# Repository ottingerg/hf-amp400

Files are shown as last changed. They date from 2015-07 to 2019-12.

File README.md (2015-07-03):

# hf-amp400

HF-Amp400 is controllerboard designed to controll the gate biasing and output power of 2 double HF-AMP FETs. 

It therefore provides 4 channels of gate biasing

4 channels of HF-Power mesaurement 

2 resetable fuses up to 10A and one auxilary resetable fuse controll for even higher currents.

This project was done as collaberation between

EMV-Consulting (http://www.emvconsulting.at)

Otelo eGen (http://www.oteloegen.at)

and

Karl Zeilhofer (http://www.zeilhofer.co.at)

it is Open Source Hardware licensed under CC-BY-SA 3.0 and is based on EtherDue which itself is based on Arduino Due

# EtherDue

The EtherDue is an 100% Arduino Due compatible board with onboard Ethernet.

For full details about the EtherDue, including a getting started guide, please visit the [Freetronics EtherDue product page](http://www.freetronics.com/products/etherdue-arduino-due-compatible-with-onboard-ethernet).

Design files were produced with [Kicad](http://kicad-pcb.org). A [PDF of the schematic is available](https://github.com/freetronics/EtherDue/raw/master/EtherDue.pdf).

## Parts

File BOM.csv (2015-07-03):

Count | Reference | Value | Footprint | Library | Part
2 | Q101 Q102 | IPB020NE7N3G | w_smd_trans:d2-pak | EtherDue-cache | NMOSFET2
2 | P102 P103 | MSTBV3 | eagle-con-phoenix-508:MSTBV3 | EtherDue-cache | CONN_01X03
10 | JP101 JP102 JP801 JP1001 JP1002 JP1003 JP1004 JP1701 JP1801 JP1901 | JUMPER3 | Pin_Headers:Pin_Header_Straight_1x03 | freetronics_kicad_sch_lib | JUMPER3
1 | P104 | MSTBV6 | eagle-con-phoenix-508:MSTBV6 | EtherDue-cache | CONN_01X06
4 | R103 R902 R1501 R1601 | 1k | Resistors_SMD:R_0603 | EtherDue-cache | R
7 | C101 C102 C103 C104 C105 C106 C107 | 1nF/X7R | Capacitors_SMD:C_0603 | EtherDue-cache | C
13 | D101 D102 D103 D1001 D1002 D1003 D1004 D1501 D1601 D2001 D2002 D2003 D2004 | BAT54S | w_smd_trans:sot23 | EtherDue-cache | DOUBLE_SCHOTTKY
1 | U101 | AD7415 | Housings_SOT-23_SOT-143_TSOT-6:SOT23-5 | EtherDue-cache | AD7415
2 | R101 R102 | Shunt | eagle-shunt:WSL4026 | EtherDue-cache | Shunt
1 | P101 | CONN_02X04 | w_conn_strip:vasch_strip_4x2 | EtherDue-cache | CONN_02X04
1 | U1701 | MCP6H04 | Housings_SOIC:SOIC-14_3.9x8.7mm_Pitch1.27mm | EtherDue-cache | LM324
11 | R104 R105 R1013 R1016 R1017 R1702 R1706 R1802 R1806 R1902 R1906 | 4k7 | Resistors_SMD:R_0603 | EtherDue-cache | R
57 | C803 C804 C901 C902 C1001 C1002 C1005 C1006 C1007 C1008 C1011 C1012 C1014 C1015 C1016 C1019 C1020 C1021 C1024 C1025 C1027 C1028 C1029 C1030 C1031 C1032 C1101 C1102 C1113 C1114 C1201 C1202 C1213 C1214 C1301 C1302 C1313 C1314 C1401 C1402 C1413 C1414 C1501 C1503 C1504 C1601 C1604 C1701 C1702 C1703 C1704 C1801 C1802 C1804 C1901 C1902 C1904 | 100n/X7R | Capacitors_SMD:C_0603 | EtherDue-cache | C
1 | IC201 | ATSAM3X8E | TQFP144 | freetronics_kicad_sch_lib | ATSAM3X8E
1 | SW202 | RESET | FT:TACTILE_SWITCH_SMD_2PIN_TINY | freetronics_kicad_sch_lib | SW_PUSHBUTTON
28 | C206 C207 C208 C301 C302 C503 C504 C509 C511 C512 C513 C514 C515 C516 C520 C521 C522 C523 C524 C526 C527 C603 C605 C607 C609 C610 C611 C701 | 100nF | SM0402 | EtherDue-cache | C
3 | U202 U503 U504 | FDN340P | FT:SOT23_MOSFET | EtherDue-cache | MOSFET-PCHANNEL
1 | SW201 | ERASE | FT:TACTILE_SWITCH_SMD_2PIN_TINY | freetronics_kicad_sch_lib | SW_PUSHBUTTON
3 | R206 R601 R604 | 1K | FT:RES_CAY16 | freetronics_kicad_sch_lib | RES_PACK4_IND
8 | D201 D202 D204 D302 D303 D601 D605 D606 | YELLOW | zeilhofer:LED-0603 | freetronics_kicad_sch_lib | LED
3 | D203 D602 D603 | GREEN | zeilhofer:LED-0603 | freetronics_kicad_sch_lib | LED
1 | U203 | LMV358IPWR | FT:TSSOP8 | EtherDue-cache | LM358
1 | R201 | 6k8 1% | SM0402_r | EtherDue-cache | R
7 | C201 C202 C205 C303 C304 C601 C602 | 22pF | SM0402 | EtherDue-cache | C
2 | R202 R203 | 39R 1% | SM0402_r | EtherDue-cache | R
2 | C203 C204 | 22pF_NM | SM0402 | EtherDue-cache | C
1 | X202 | ABS07L 32.768kHz | FT:ABS07L | freetronics_kicad_sch_lib | CRYSTAL
5 | L201 L501 L503 L504 L505 | MH2029-300Y | FT:MH2029 | EtherDue-cache | INDUCTOR_SMALL
1 | R204 | 100K | SM0402_r | EtherDue-cache | R
1 | X201 | TXC 7A 12MHz 18pF | FT:TXC_7A | freetronics_kicad_sch_lib | CRYSTAL
2 | SJ202 SJ401 | CLOSED | FT:SJ_SHORTED | freetronics_kicad_sch_lib | SJ
3 | SJ201 SJ203 SJ601 | OPEN | FT:SJ_OPEN | freetronics_kicad_sch_lib | SJ
3 | R205 R207 R304 | 1K5 | SM0402_r | EtherDue-cache | R
1 | R208 | 10K | SMD_Packages:SMD-0402_r | EtherDue-cache | R
1 | R305 | 2K7 | SM0402_r | EtherDue-cache | R
7 | R306 R307 R308 R309 R501 R606 R607 | 1K | SM0402_r | EtherDue-cache | R
5 | R303 R310 R403 R503 R505 | 10K | SM0402_r | EtherDue-cache | R
2 | R301 R302 | 22R | SM0402_r | EtherDue-cache | R
5 | VR401 VR402 VR403 Z301 Z302 | PGB1010603 | FT:0603 | EtherDue-cache | VR
2 | F301 F401 | 500mA PTC 1812 | SM1812 | freetronics_kicad_sch_lib | FUSE
2 | P301 P401 | USB_5PIN_SHELL | FT:USB-MICRO_TH_4PEGS | freetronics_kicad_sch_lib | USB_5PIN_SHELL
1 | C305 | 1uF | SM0402 | EtherDue-cache | C
1 | D301 | CD1206-S | FT:1206_DIODE | freetronics_kicad_sch_lib | DIODE
1 | ICSP301 | M02X03 | Pin_Headers:Pin_Header_Straight_2x03 | freetronics_kicad_sch_lib | M02X03
1 | IC301 | ATMEGA16U2 | FT:QFN32 | freetronics_kicad_sch_lib | ATMEGA16U2
1 | X301 | TXC 7A 16MHz 18pF | FT:TXC_7A | freetronics_kicad_sch_lib | CRYSTAL
1 | DEBUG401 | M04 | Pin_Headers:Pin_Header_Straight_1x04 | freetronics_kicad_sch_lib | M04
8 | C402 C403 C506 C507 C517 C518 C519 C528 | 10uF | FT:SM0603_Capa | EtherDue-cache | C
2 | C401 C505 | 10nF | SM0402 | EtherDue-cache | C
2 | R401 R502 | 100K | FT:RES_CAY16 | freetronics_kicad_sch_lib | RES_PACK4_IND
1 | JP401 | JTAG | FT:2X5_127MMPITCH | freetronics_kicad_sch_lib | M02X05
1 | SHIELD401 | ARDUINO_DUE_SHIELD | FT:ARDUINO_DUE_SHIELD | freetronics_kicad_sch_lib | ARDUINO_DUE_SHIELD
1 | U603 | APX811-31UG-7 | FT:SOT143-R | freetronics_kicad_sch_lib | APX811
3 | C604 C606 C608 | 10uF 6.3V A TANT | SMD_Packages:SMD-1206_Pol | EtherDue-cache | C
2 | L601 L602 | 1uH 250mA | FT:0805 | EtherDue-cache | INDUCTOR_SMALL
1 | R605 | 49R9 1% | FT:RES_CAY16 | freetronics_kicad_sch_lib | RES_PACK4
1 | JP601 | M04 | zeilhofer:FT-POE-MODULE-NOOUTLINE | freetronics_kicad_sch_lib | M04
1 | U602 | HY931147C | FT:HY931147C | freetronics_kicad_sch_lib | HY931147C
1 | D604 | RED | zeilhofer:LED-0603 | freetronics_kicad_sch_lib | LED
1 | R602 | 1M | SM0402_r | EtherDue-cache | R
1 | X601 | TXC 7A 25MHz 18pF | FT:TXC_7A | freetronics_kicad_sch_lib | CRYSTAL
1 | R603 | 12K3 1% | SM0402_r | EtherDue-cache | R
1 | Q601 | 2N7002 | FT:SOT23 | freetronics_kicad_sch_lib | 2N7002
1 | IC601 | W5100 | FT:SQFP80 | freetronics_kicad_sch_lib | W5100
1 | U701 | MICROSD | FT:MICRO-SD-SOCKET-PP | freetronics_kicad_sch_lib | MICROSD
2 | SJ701 SJ702 | SJ | FT:SJ_SHORTED | freetronics_kicad_sch_lib | SJ
1 | U702 | 24AA025E48 | FT:SOT23-6 | freetronics_kicad_sch_lib | 24AA025E48
1 | Q501 | BC847BSMD | FT:SOT23_TRANSISTOR | freetronics_kicad_sch_lib | NPN
1 | U505 | NCP1117ST33T3G | FT:SOT223 | EtherDue-cache | NCP1117ST33T3G
1 | R504 | 52K3 | SM0402_r | EtherDue-cache | R
1 | D503 | STPS2L60A | FT:SMA-DIODE | freetronics_kicad_sch_lib | DIODE
1 | C510 | 100uF 16V | Capacitors_SMD:c_elec_5x5.3 | EtherDue-cache | C
1 | L502 | 10uH SRR0604-100ML | FT:SRR0604 | EtherDue-cache | INDUCTOR_SMALL
1 | D502 | CD1206-S01575 | FT:1206_DIODE | freetronics_kicad_sch_lib | DIODE
1 | U502 | LM2734Y | FT:SOT23-6 | freetronics_kicad_sch_lib | LM2734Y
1 | C502 | 10uF 25V | SM1206 | EtherDue-cache | C
1 | C501 | 47uF 25V | Capacitors_SMD:c_elec_5x5.3 | EtherDue-cache | C
1 | D501 | 1N4004 | FT:SMB-DIODE | freetronics_kicad_sch_lib | DIODE
1 | U501 | POWERJACK | FT:POWER_JACK_PTH | freetronics_kicad_sch_lib | POWERJACK
2 | C702 C802 | 2n2/50V/COG | Capacitors_SMD:C_0603 | EtherDue-cache | C
1 | P801 | MSTBV2 | eagle-con-phoenix-508:MSTBV2 | EtherDue-cache | CONN_01X02
1 | F801 | SMD100F | eagle-switch-raychem:SMD050F | freetronics_kicad_sch_lib | FUSE
1 | D801 | ZENER2 | Diodes_SMD:Diode-SMB_Standard | EtherDue-cache | ZENER2
1 | L801 | WE-TI-744732331 | eagle-WE-TI:WE-TI_8075_SHRINKTUBE | EtherDue-cache | INDUCTOR_SMALL
19 | C801 C805 C806 C807 C813 C815 C816 C817 C1013 C1026 C1033 C1108 C1112 C1208 C1212 C1308 C1312 C1408 C1412 | 10u/25V/X7R | Capacitors_SMD:C_1206 | EtherDue-cache | C
3 | U801 U802 U803 | TPS7A4501DCQT | zeilhofer:DCQ(R-PDSO-G6) | EtherDue-cache | TPS7A4501DCQT
2 | R801 R802 | 18k | Resistors_SMD:R_0603 | EtherDue-cache | R
2 | R805 R807 | 2k2 | Resistors_SMD:R_0603 | EtherDue-cache | R
3 | R803 R804 R806 | 22k | Resistors_SMD:R_0603 | EtherDue-cache | R
1 | R808 | 3k9 | Resistors_SMD:R_0603 | EtherDue-cache | R
5 | U804 U1102 U1202 U1302 U1402 | REG101NA-5 | zeilhofer:DBV(R-PDSO-G5) | EtherDue-cache | REG101NA-5
1 | C808 | 1u/25V/X7R | Capacitors_SMD:C_0805 | EtherDue-cache | C
28 | C809 C810 C811 C812 C814 C818 C819 C820 C1106 C1109 C1206 C1209 C1306 C1309 C1406 C1409 C1705 C1706 C1805 C1806 C1905 C1906 C2001 C2002 C2003 C2010 C2011 C2012 | 10n/X7R | Capacitors_SMD:C_0603 | EtherDue-cache | C
17 | R809 R810 R811 R1103 R1106 R1203 R1206 R1303 R1306 R1403 R1406 R1708 R1709 R1808 R1809 R1908 R1909 | 0R | Resistors_SMD:R_0603 | EtherDue-cache | R
11 | L802 L803 L804 L805 L1101 L1201 L1301 L1401 L1701 L1801 L1901 | WE-CBF-742792093 | Resistors_SMD:R_0805 | EtherDue-cache | INDUCTOR_SMALL
1 | U901 | TJA1040T | Housings_SOIC:SOIC-8_3.9x4.9mm_Pitch1.27mm | EtherDue-cache | TJA1040T
1 | R903 | 47k | Resistors_SMD:R_0603 | EtherDue-cache | R
2 | SJ901 SJ902 | Solder-Jumper | FT:SJ_2W | freetronics_kicad_sch_lib | JUMPER_SJ3
2 | R904 R905 | 60R | Resistors_SMD:R_1206 | EtherDue-cache | R
2 | R906 R907 | 1k3 | Resistors_SMD:R_0603 | EtherDue-cache | R
2 | P901 P902 | 677006144621 | eagle-InputOutputIO:677006144621 | EtherDue-cache | CONN_01X06
1 | R901 | 1k8 | Resistors_SMD:R_0603 | EtherDue-cache | R
1 | L901 | WE-SL1-744212510 | eagle-WE-SL1:WE-SL1 | EtherDue-cache | WE-SL1
1 | U1001 | AD7294BSUZ | eagle-ADI-Phase-2:QFP40P900X900X120-64N | EtherDue-cache | AD7294BSUZ
20 | X1001 X1002 X1003 X1004 X1005 X1006 X1007 X1008 X1009 X1010 X1011 X1012 X1102 X1103 X1202 X1203 X1302 X1303 X1402 X1403 | SMB | zeilhofer:SMB-RS#420-5401_wirepad | EtherDue-cache | CONN_COAX
19 | R1001 R1002 R1003 R1004 R1005 R1006 R1007 R1008 R1014 R1015 R1703 R1705 R1707 R1803 R1805 R1807 R1903 R1905 R1907 | 100R | Resistors_SMD:R_0603 | EtherDue-cache | R
7 | Q1001 Q1703 Q1704 Q1803 Q1804 Q1903 Q1904 | BSS308 | zeilhofer:sot23-gsd | EtherDue-cache | PMOSFET2
4 | LED1001 LED1701 LED1801 LED1901 | RED | LEDs:LED-0805 | EtherDue-cache | LED2
4 | R1009 R1010 R1011 R1012 | 5k6 | Resistors_SMD:R_0603 | EtherDue-cache | R
23 | C1003 C1004 C1009 C1010 C1017 C1018 C1022 C1023 C1034 C1035 C1036 C1037 C1710 C1810 C1910 C2004 C2005 C2006 C2007 C2008 C2009 C2013 C2014 | 1n/X7R | Capacitors_SMD:C_0603 | EtherDue-cache | C
4 | VR1001 VR1002 VR1003 VR1004 | 10k | Potentiometers:Potentiometer_Bourns_3296W_3-8Zoll_Inline_ScrewUp | EtherDue-cache | POT123
4 | U1101 U1201 U1301 U1401 | ADL5513 | zeilhofer:LFCSP16 | EtherDue-cache | ADL5513
8 | P1101 P1102 P1201 P1202 P1301 P1302 P1401 P1402 | CONN_01X02 | Pin_Headers:Pin_Header_Straight_1x02 | EtherDue-cache | CONN_01X02
4 | R1104 R1204 R1304 R1404 | 12k | Resistors_SMD:R_0805 | EtherDue-cache | R
7 | R1105 R1205 R1305 R1405 R1710 R1810 R1910 | 2k2 | Resistors_SMD:R_0805 | EtherDue-cache | R
4 | C1110 C1210 C1310 C1410 | 47p/X7R | Capacitors_SMD:C_0603 | EtherDue-cache | C
8 | C1103 C1104 C1203 C1204 C1303 C1304 C1403 C1404 | 100p/X7R | Capacitors_SMD:C_0603 | EtherDue-cache | C
4 | X1101 X1201 X1301 X1401 | SMA | zeilhofer:SMA-RS#616-3422 | EtherDue-cache | CONN_COAX
8 | C1105 C1107 C1205 C1207 C1305 C1307 C1405 C1407 | 47n/C0G | Capacitors_SMD:C_0402 | EtherDue-cache | C
4 | R1102 R1202 R1302 R1402 | 820R/1% | Resistors_SMD:R_0603 | EtherDue-cache | R
4 | C1111 C1211 C1311 C1411 | 100n/X7R | Capacitors_SMD:C_0805 | EtherDue-cache | C
4 | R1101 R1201 R1301 R1401 | 56R/1% | Resistors_SMD:R_0603 | EtherDue-cache | R
2 | R1502 R1602 | 100k | Resistors_SMD:R_0603 | EtherDue-cache | R
2 | C1502 C1602 | 1u/X7R | Capacitors_SMD:C_0805 | EtherDue-cache | C
10 | Q1501 Q1502 Q1601 Q1602 Q1701 Q1702 Q1801 Q1802 Q1901 Q1902 | BSS123 | zeilhofer:sot23-gsd | EtherDue-cache | NMOSFET2
12 | R1503 R1504 R1505 R1603 R1604 R1605 R1701 R1801 R1901 R2007 R2008 R2009 | 10k | Resistors_SMD:R_0603 | EtherDue-cache | R
1 | U1501 | 4013_with_supply | Housings_SOIC:SOIC-14_3.9x8.7mm_Pitch1.27mm | EtherDue-cache | 4013_with_supply
3 | SW1701 SW1801 SW1901 | SW_PUSH | FT:SW_TACTILE_SMD | EtherDue-cache | SW_PUSH
3 | U1702 U1801 U1901 | INA207 | Housings_SOIC:SOIC-14_3.9x8.7mm_Pitch1.27mm | EtherDue-cache | INA207
3 | C1709 C1809 C1909 | DNP | Capacitors_SMD:C_0603 | EtherDue-cache | C
3 | U1703 U1802 U1902 | MEU1S1212ZC | zeilhofer:MEU1-Murata-DCDC | EtherDue-cache | MEU1
3 | R1704 R1804 R1904 | 1k | Resistors_SMD:R_1206 | EtherDue-cache | R
6 | C1707 C1708 C1807 C1808 C1907 C1908 | 1n/X7R | Capacitors_SMD:C_0805 | EtherDue-cache | C
3 | VR1701 VR1801 VR1901 | 100k | Potentiometers:Potentiometer_Bourns_3296W_3-8Zoll_Inline_ScrewUp | EtherDue-cache | POT123
2 | R2010 R2011 | 6k8 | Resistors_SMD:R_0603 | EtherDue-cache | R
1 | R2012 | TBD | Resistors_SMD:R_0603 | EtherDue-cache | R
3 | R2001 R2002 R2003 | 47k | Resistors_SMD:R_0805 | EtherDue-cache | R
3 | R2004 R2005 R2006 | 2k7 | Resistors_SMD:R_0603 | EtherDue-cache | R
576

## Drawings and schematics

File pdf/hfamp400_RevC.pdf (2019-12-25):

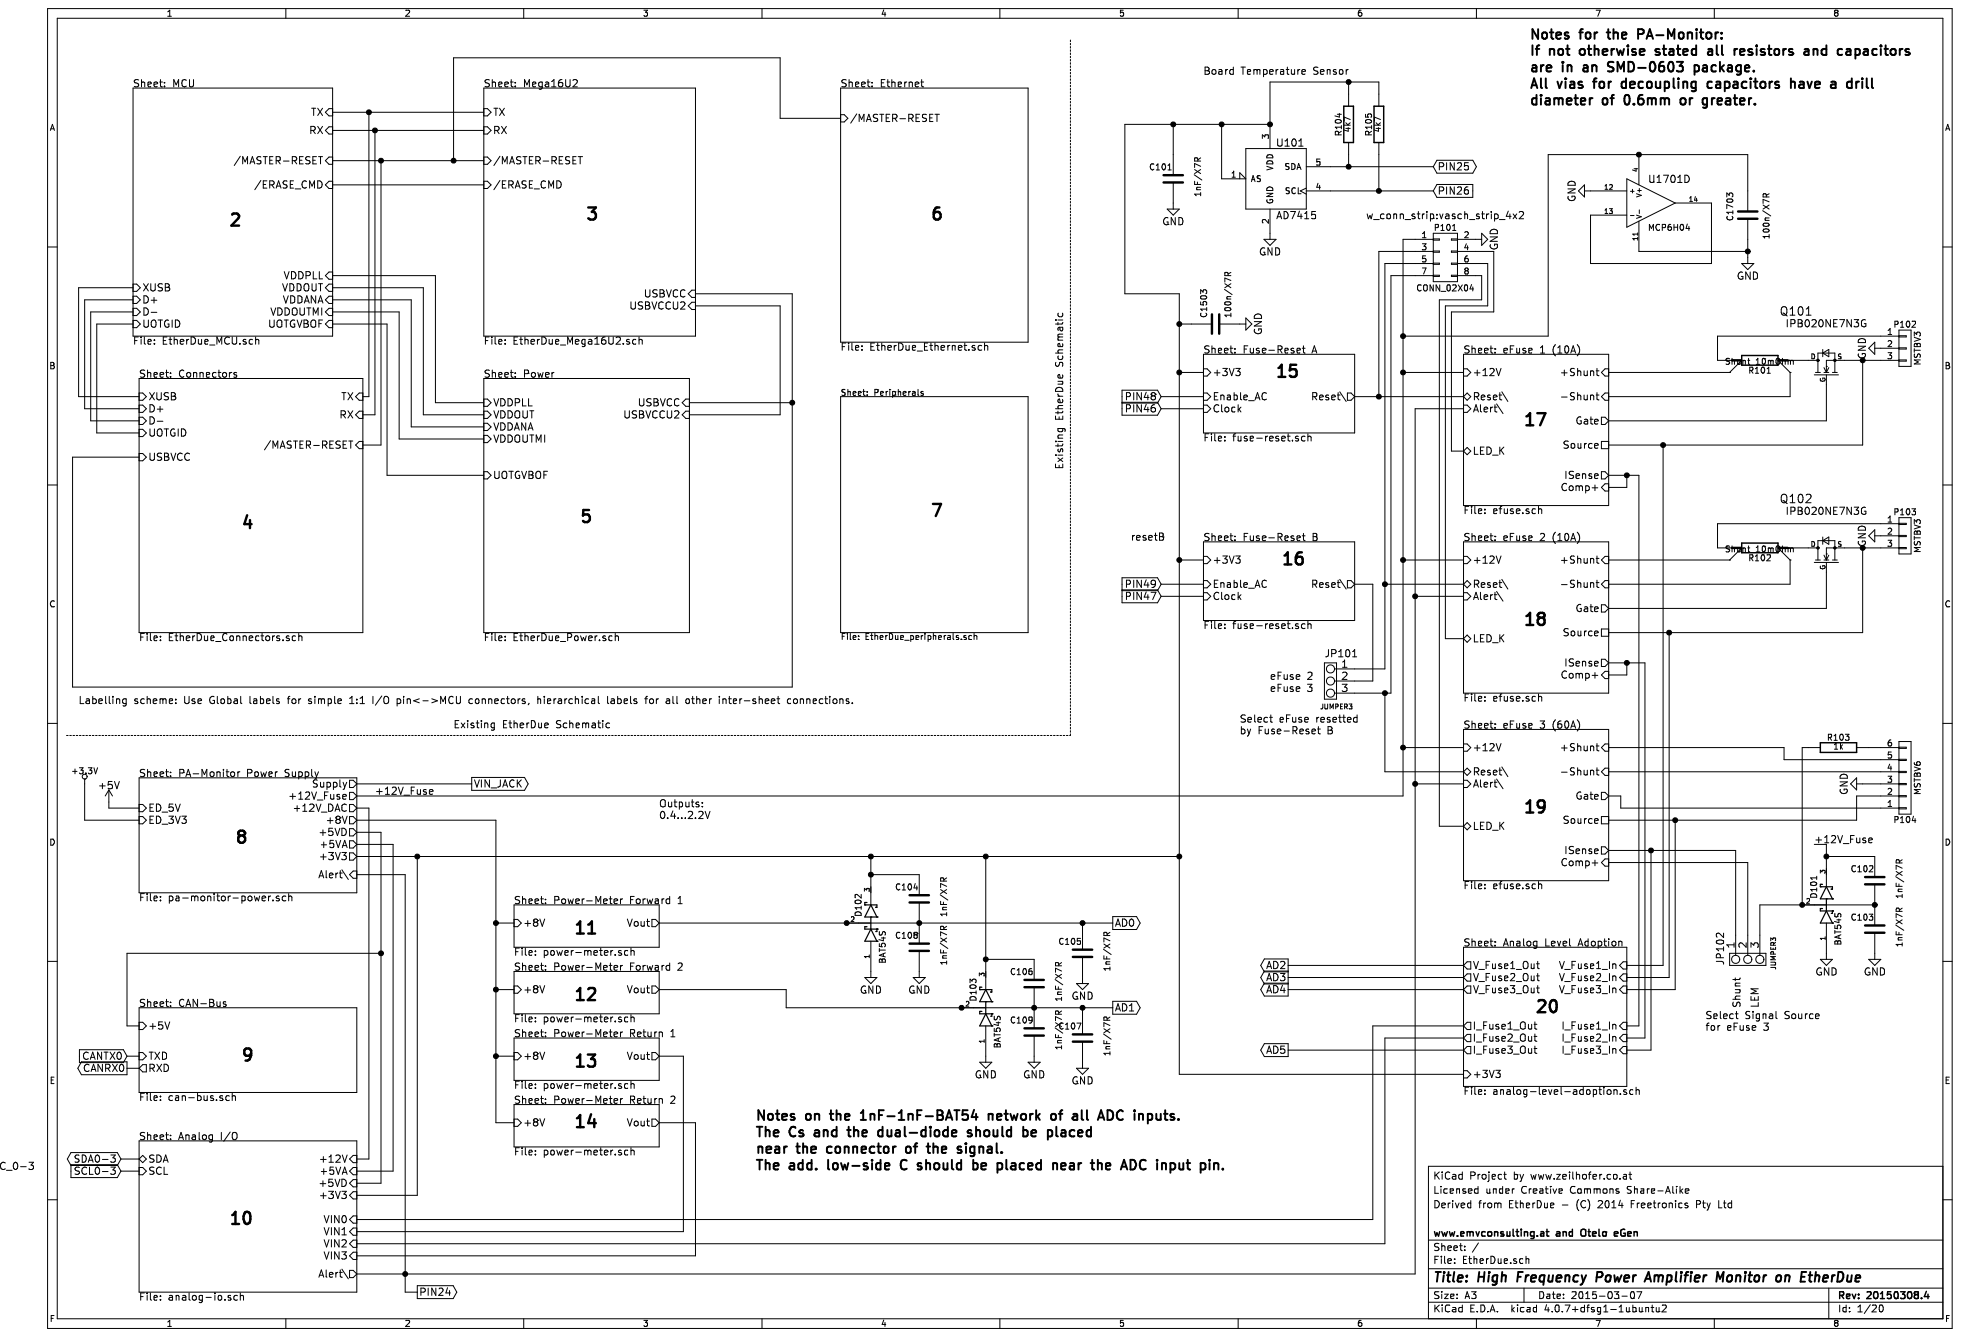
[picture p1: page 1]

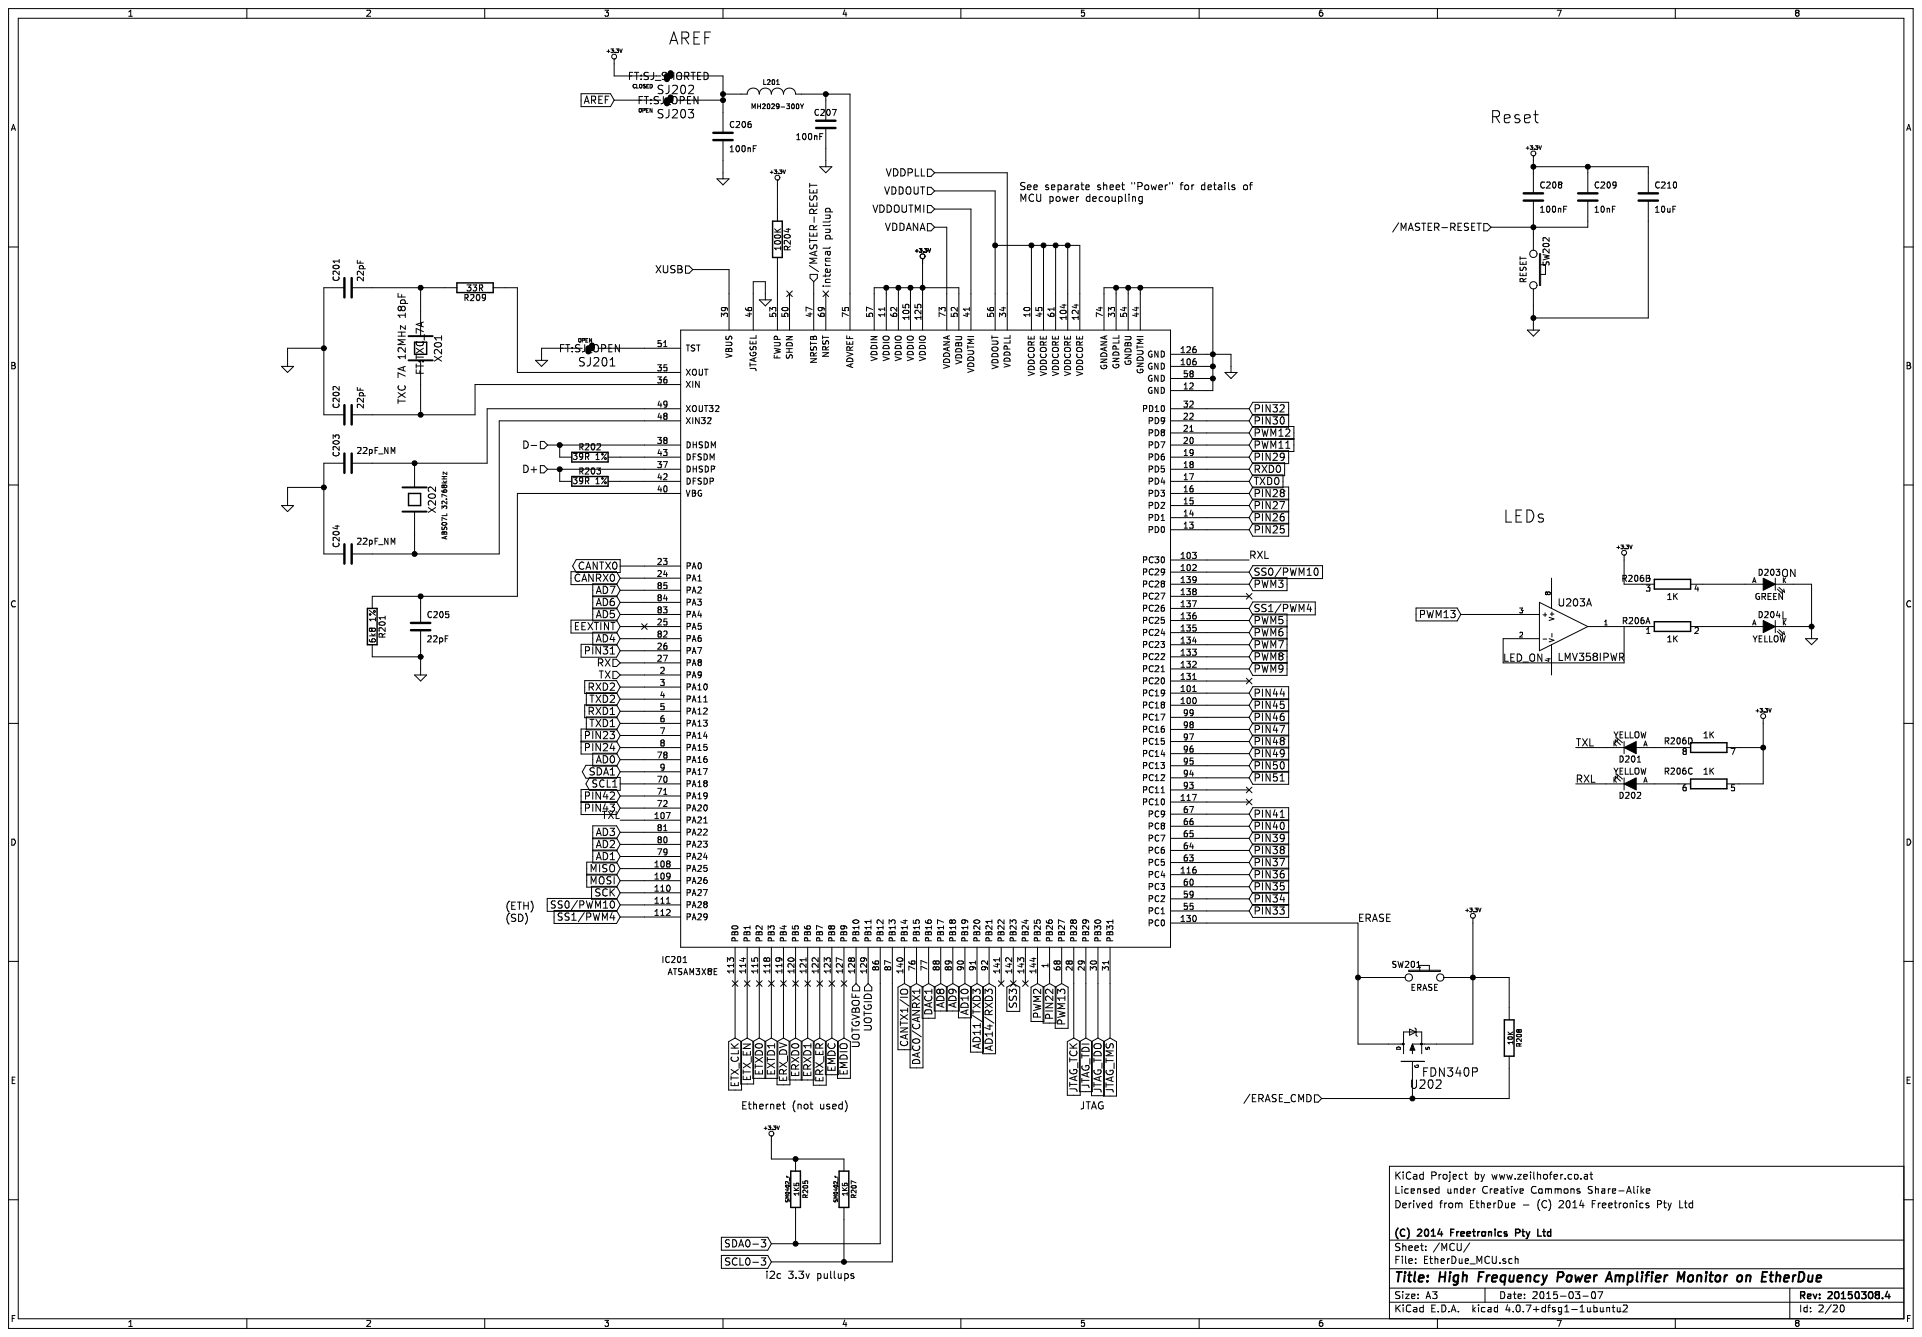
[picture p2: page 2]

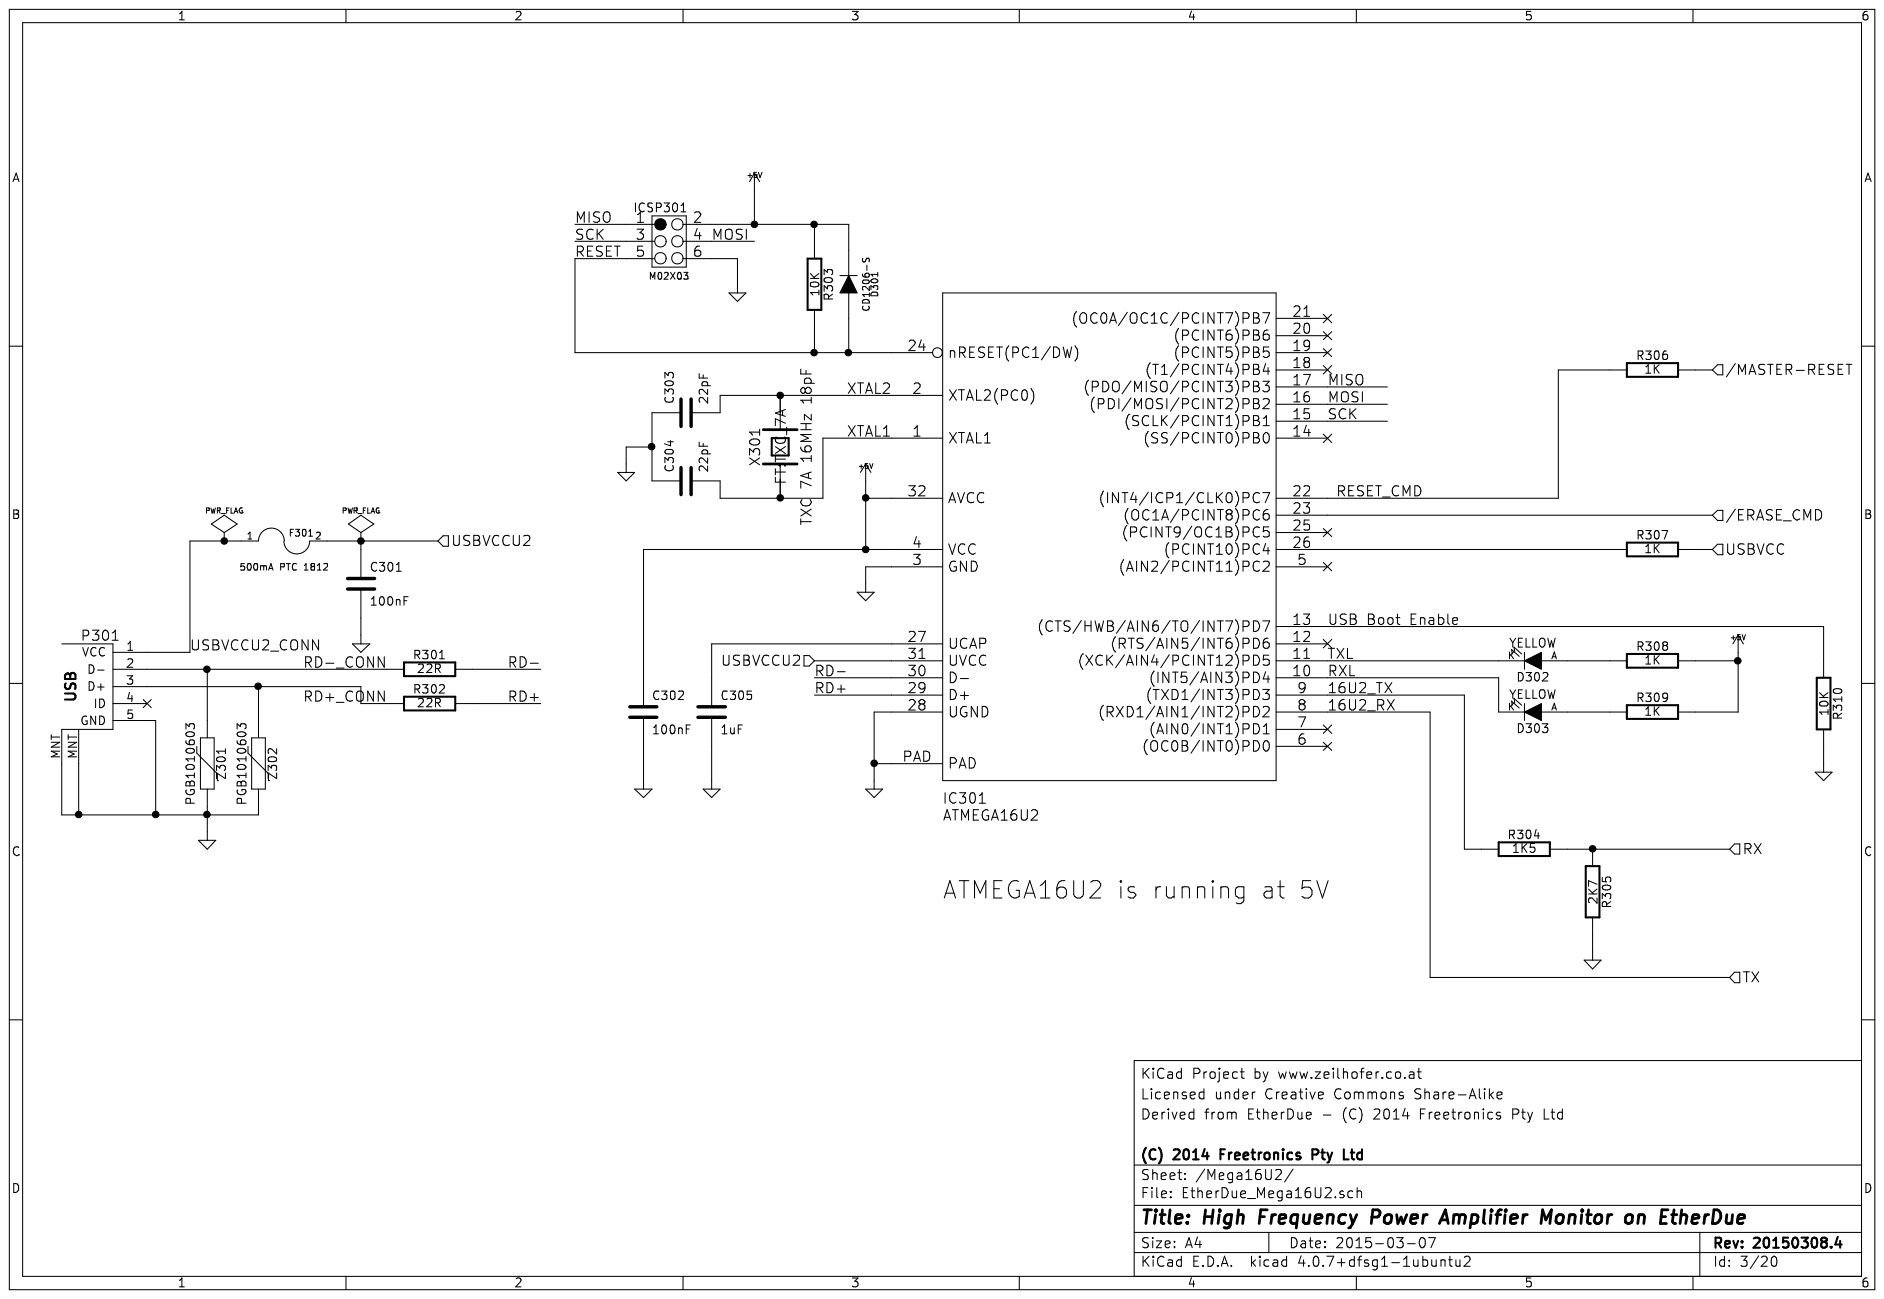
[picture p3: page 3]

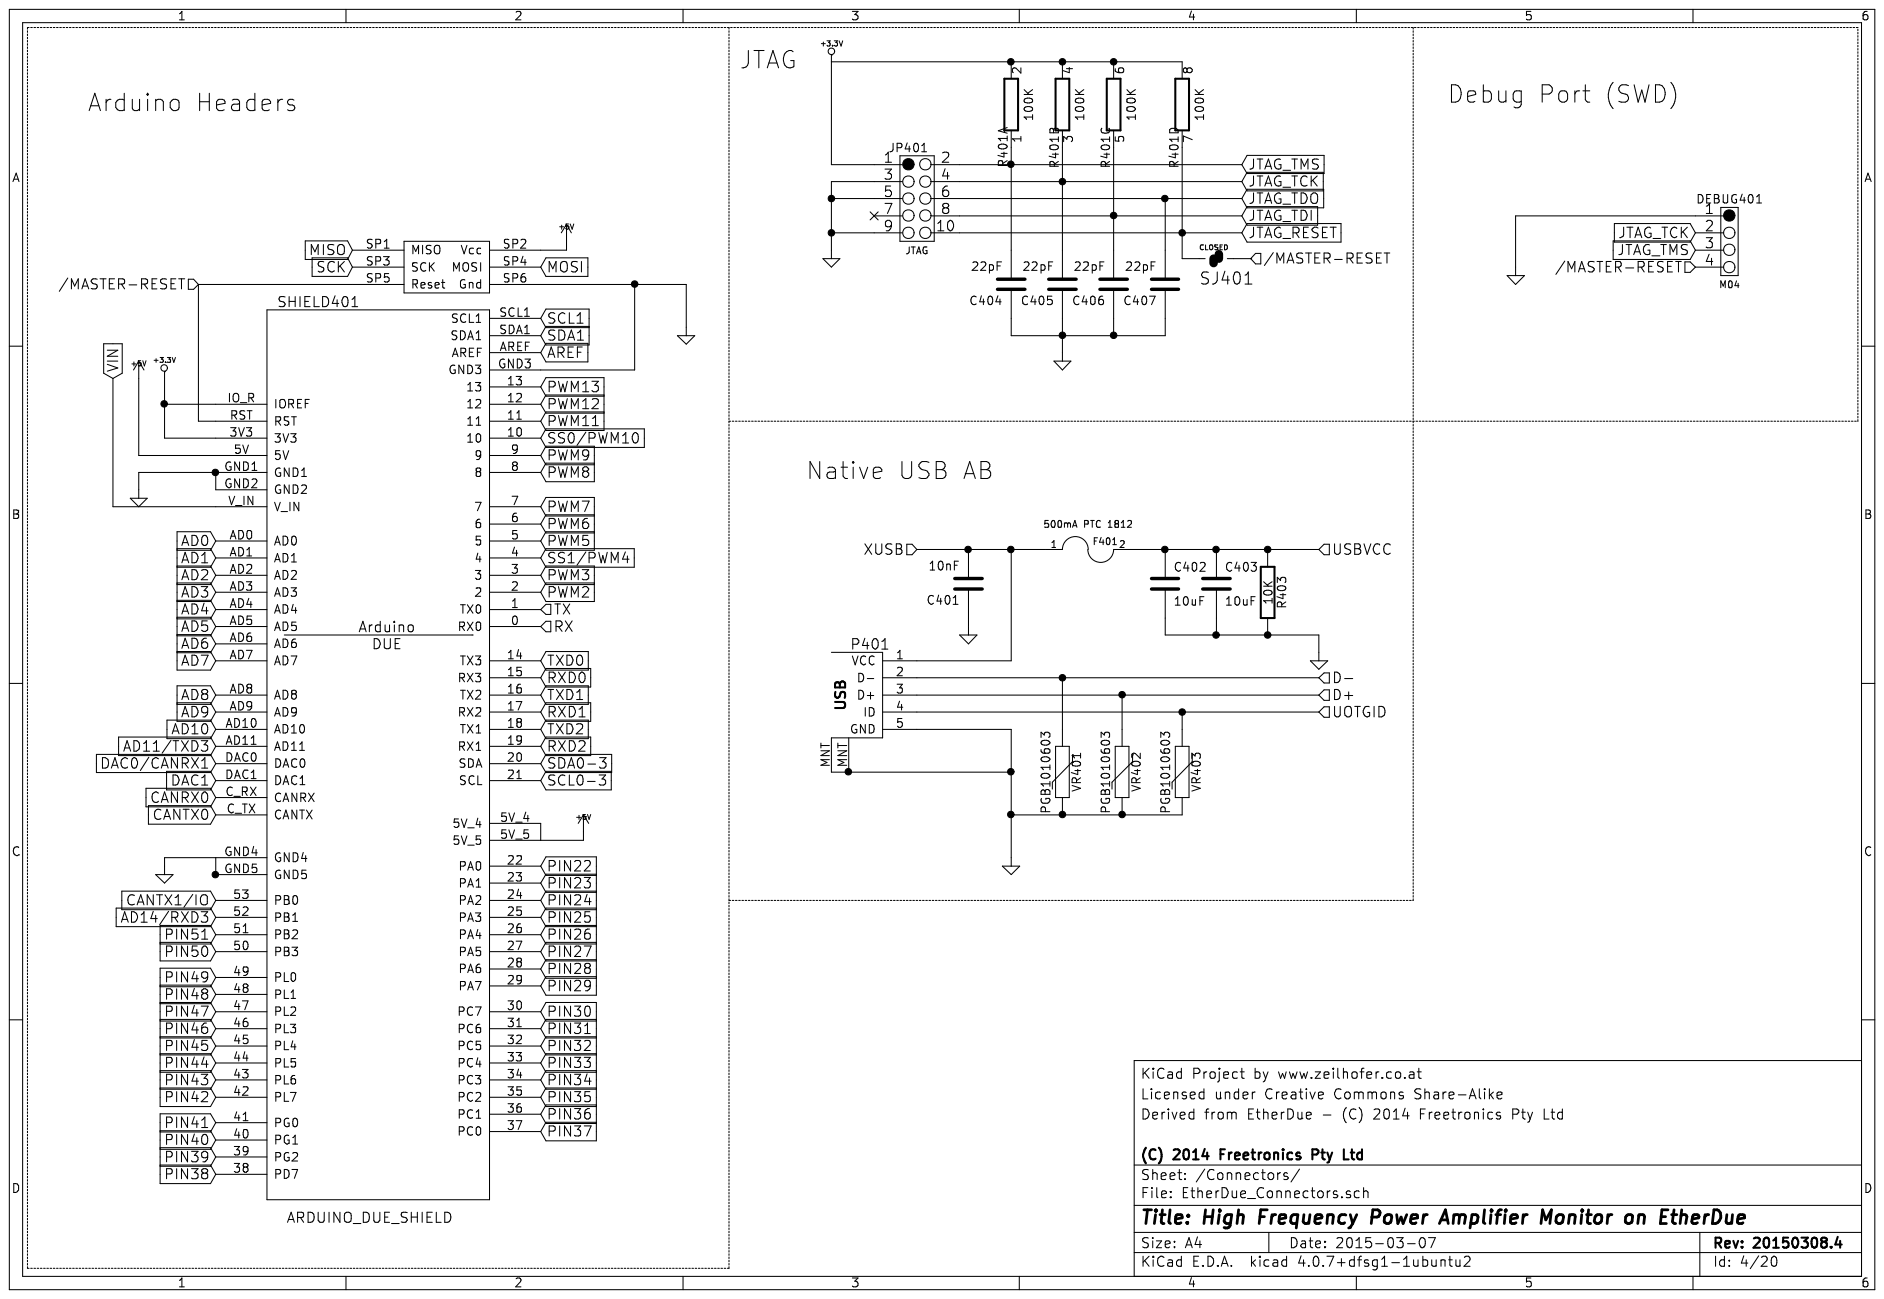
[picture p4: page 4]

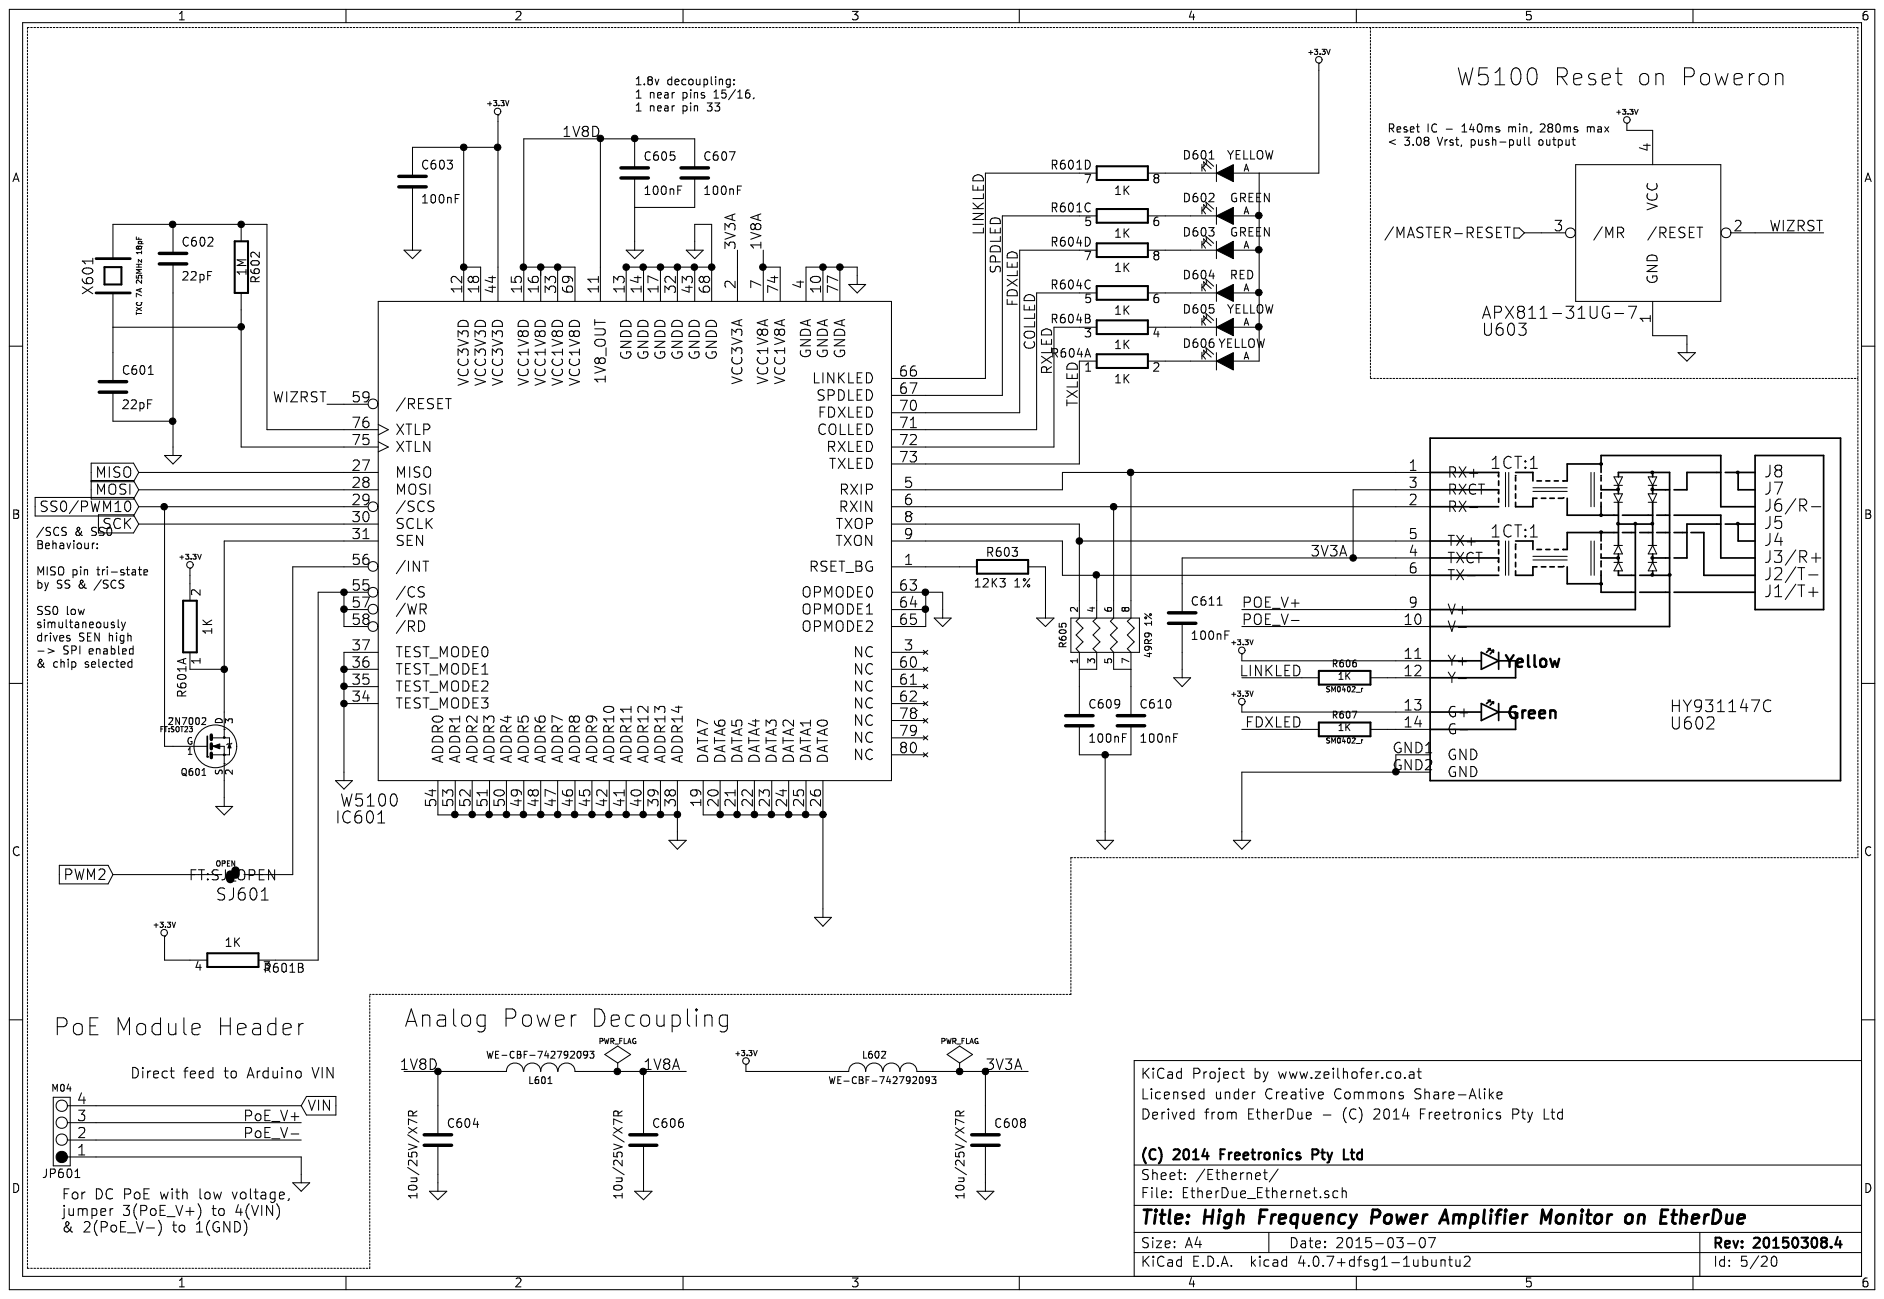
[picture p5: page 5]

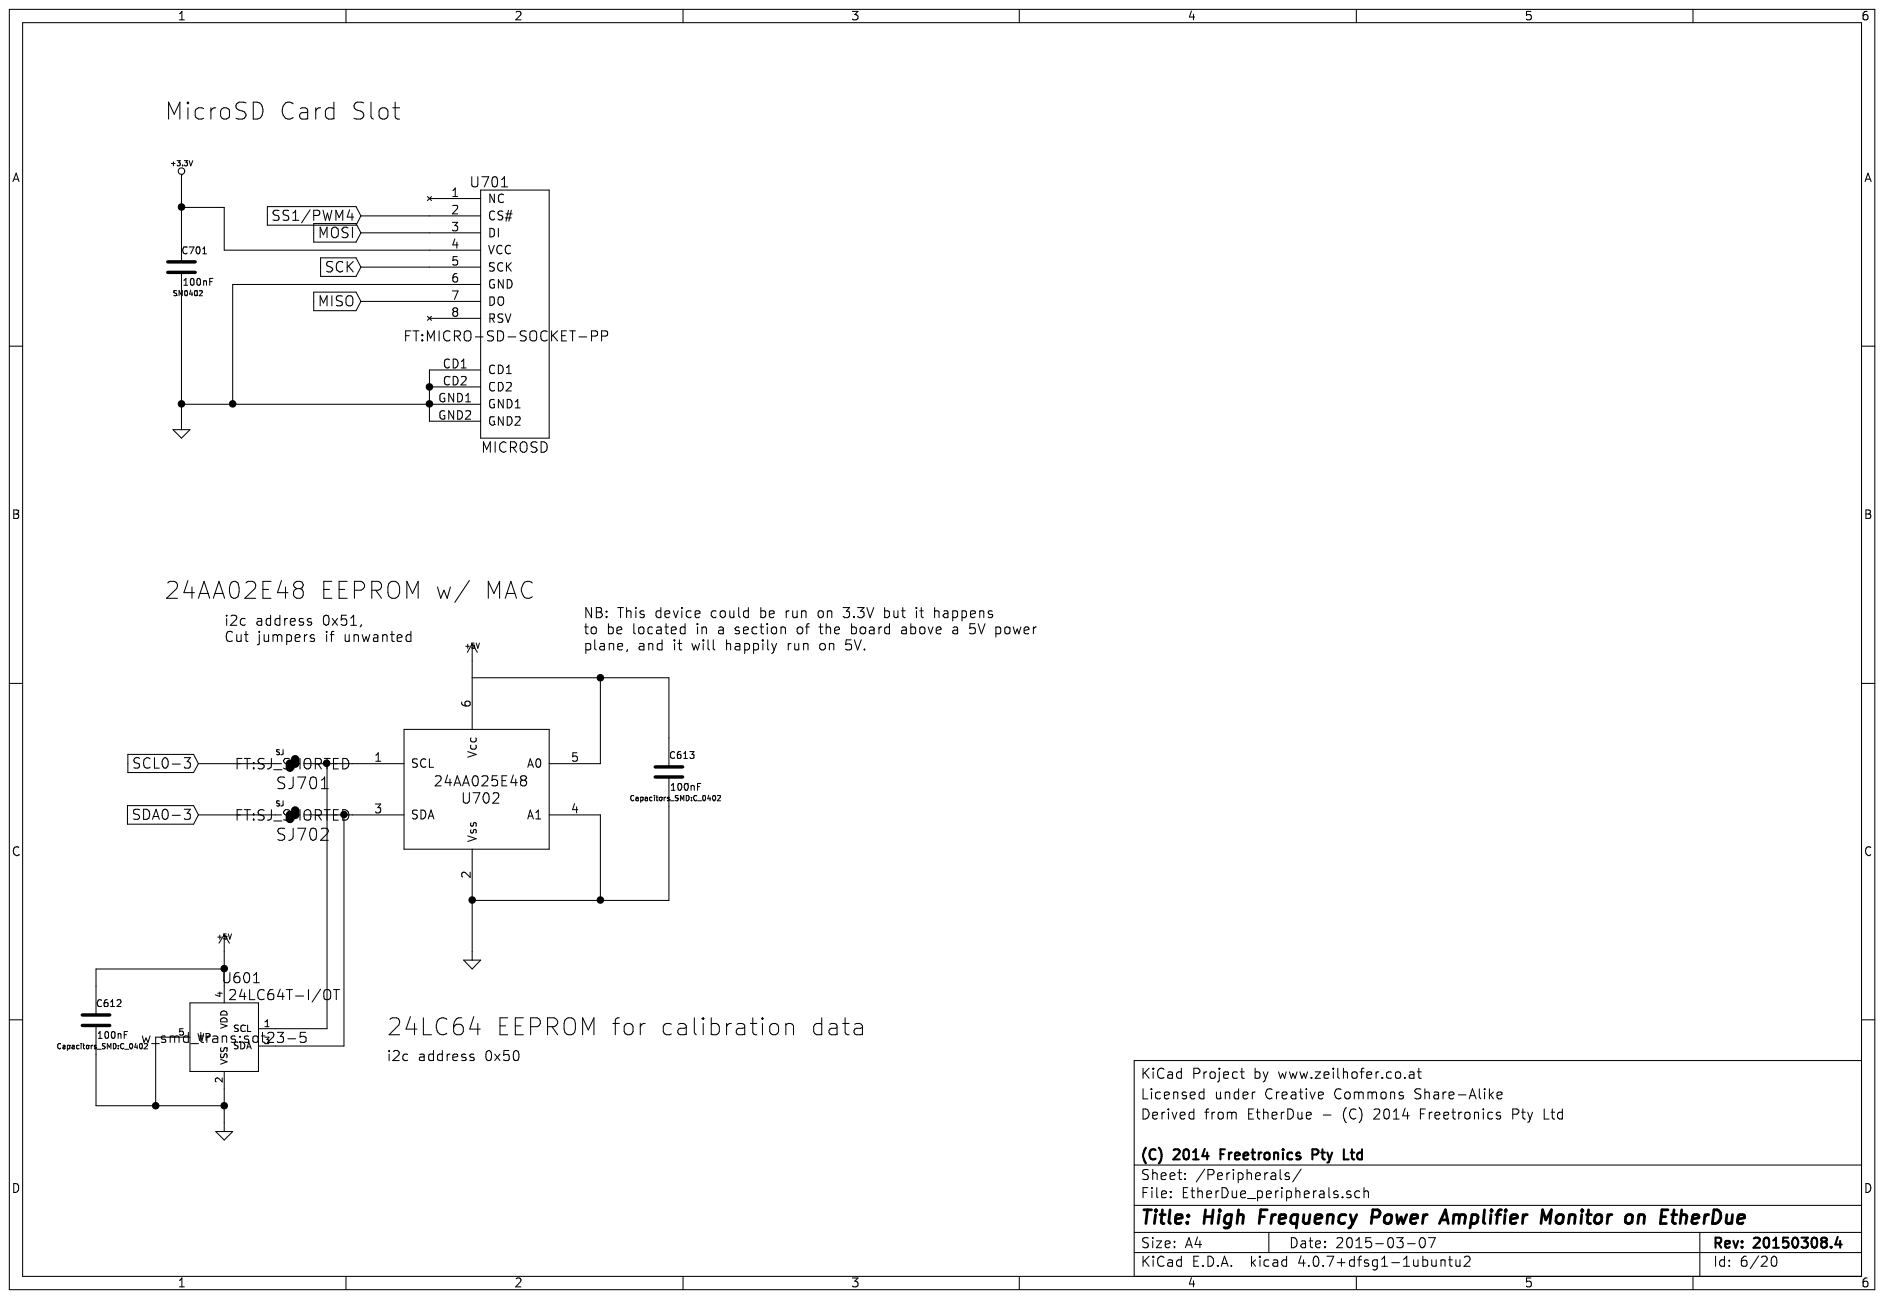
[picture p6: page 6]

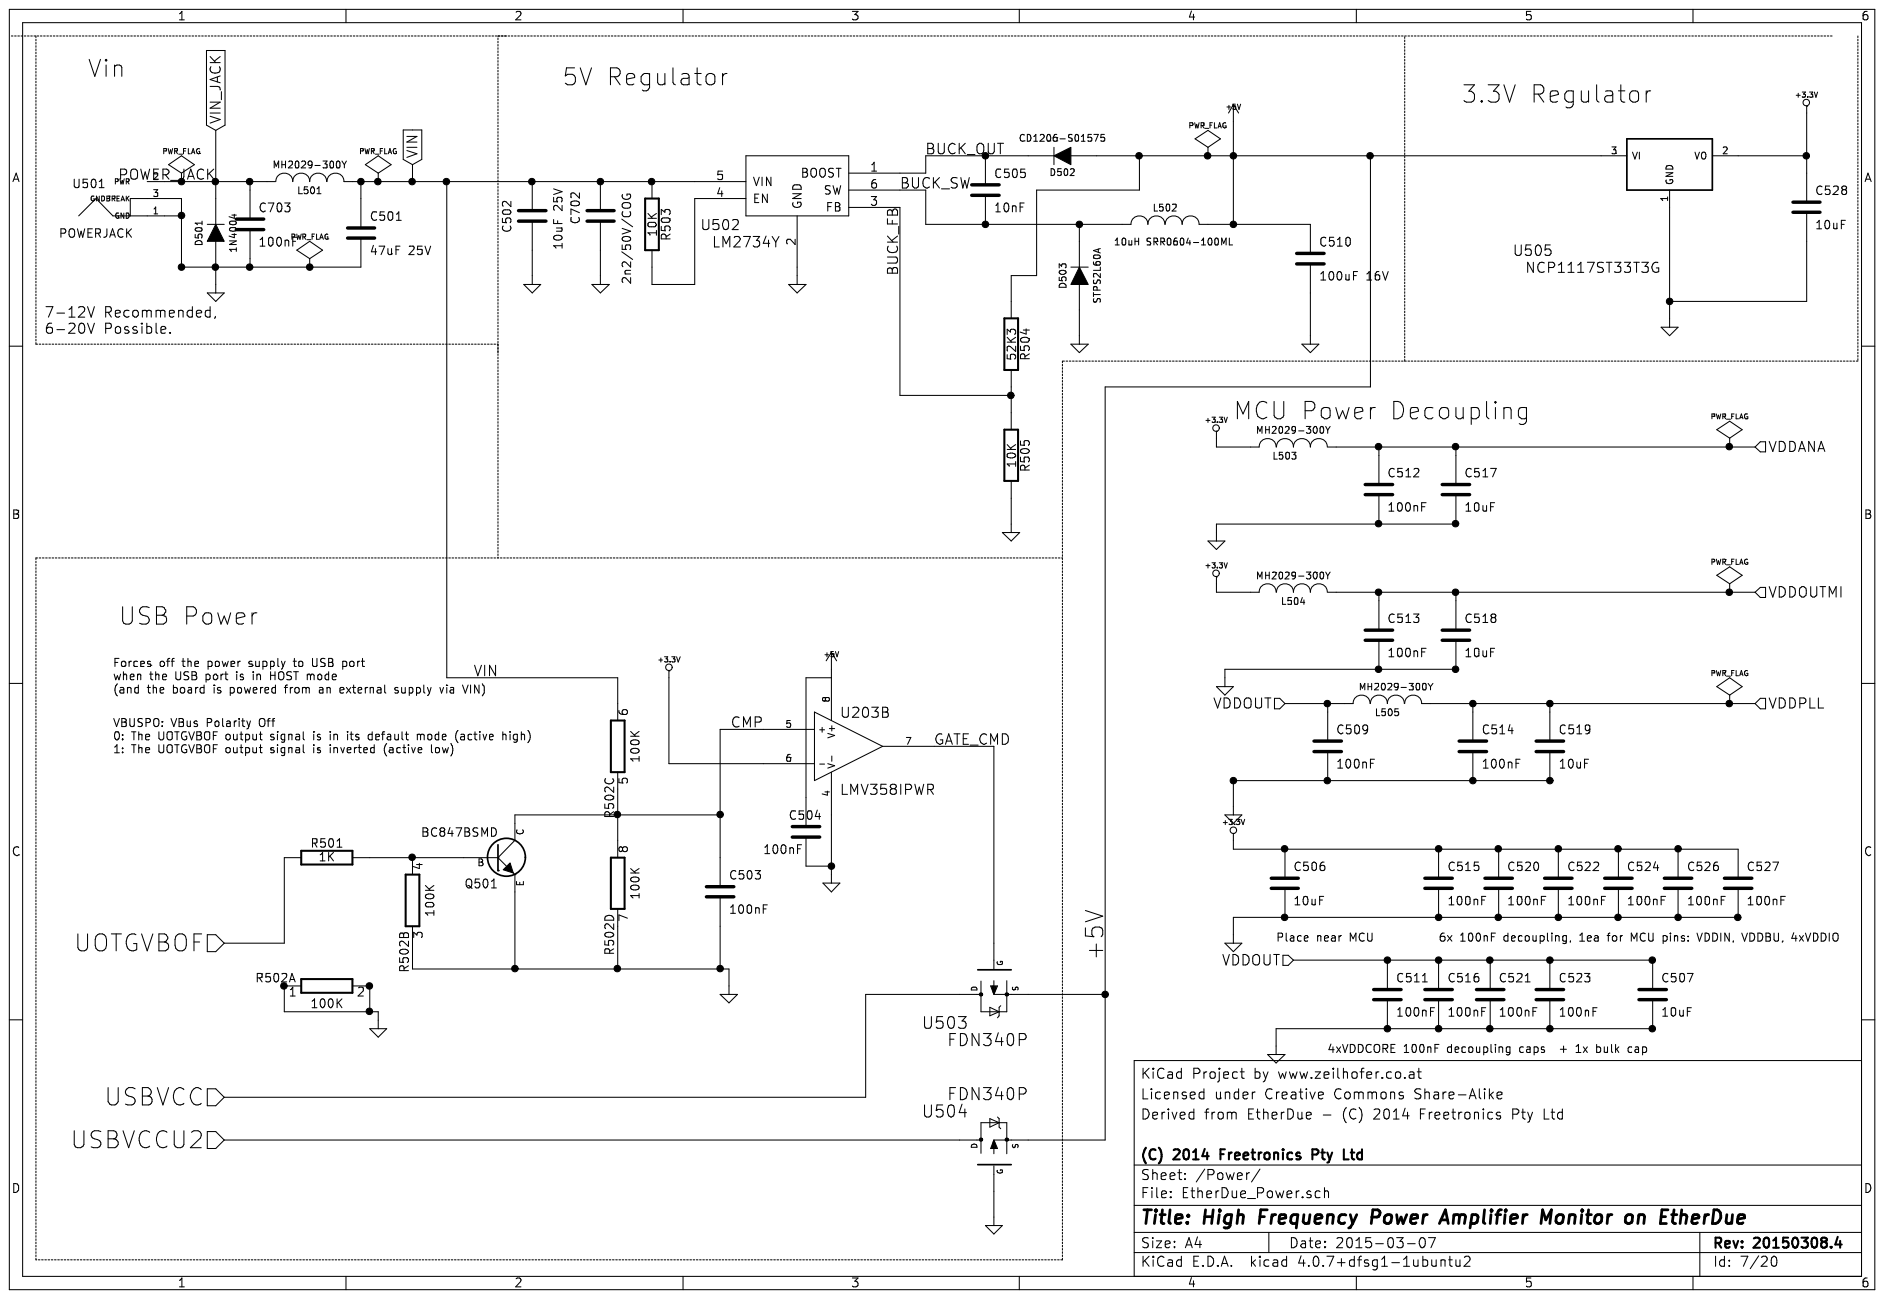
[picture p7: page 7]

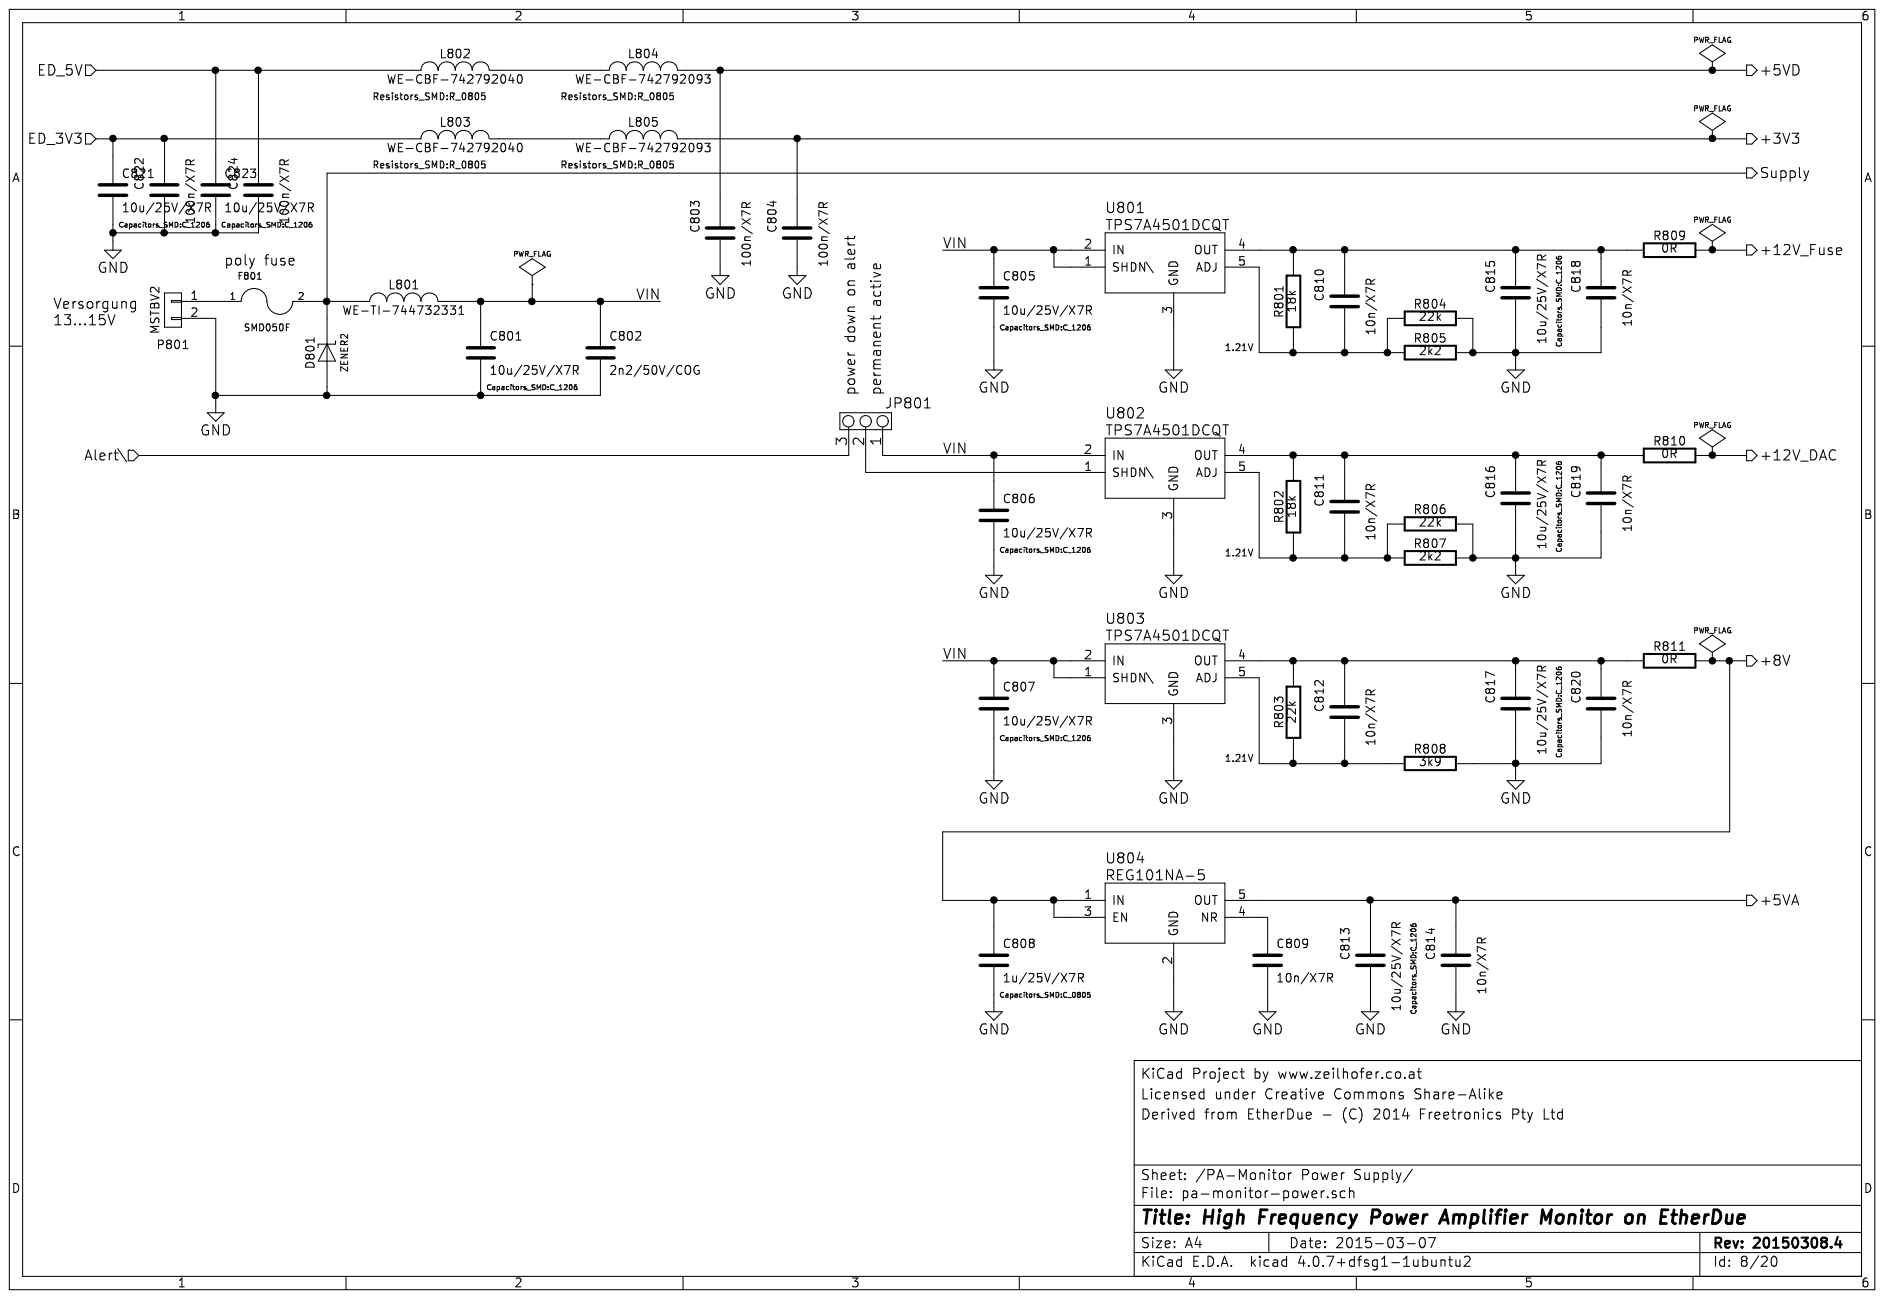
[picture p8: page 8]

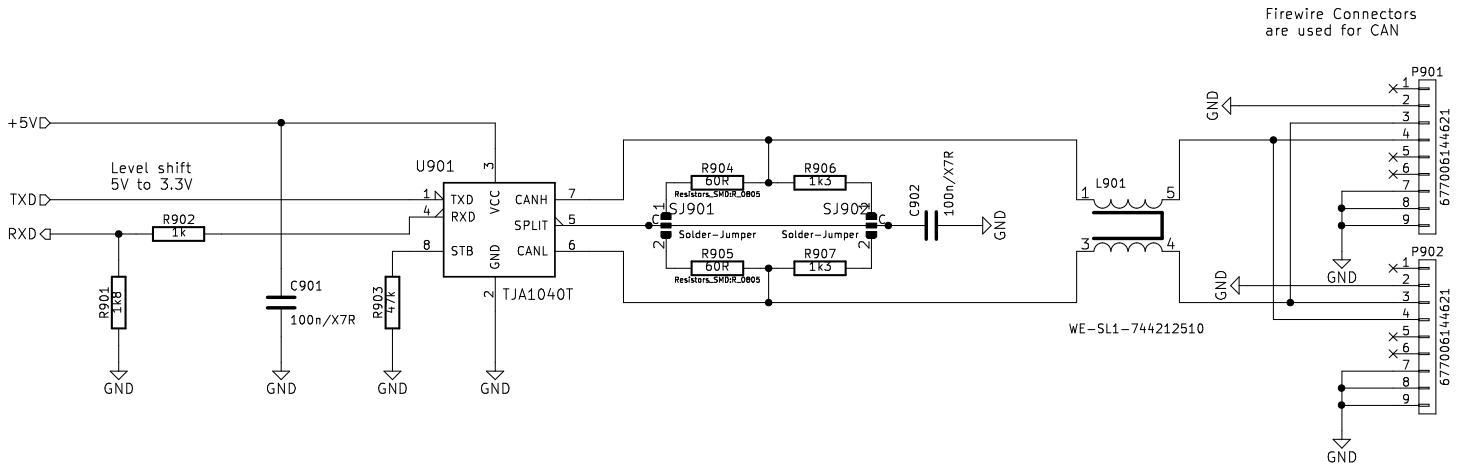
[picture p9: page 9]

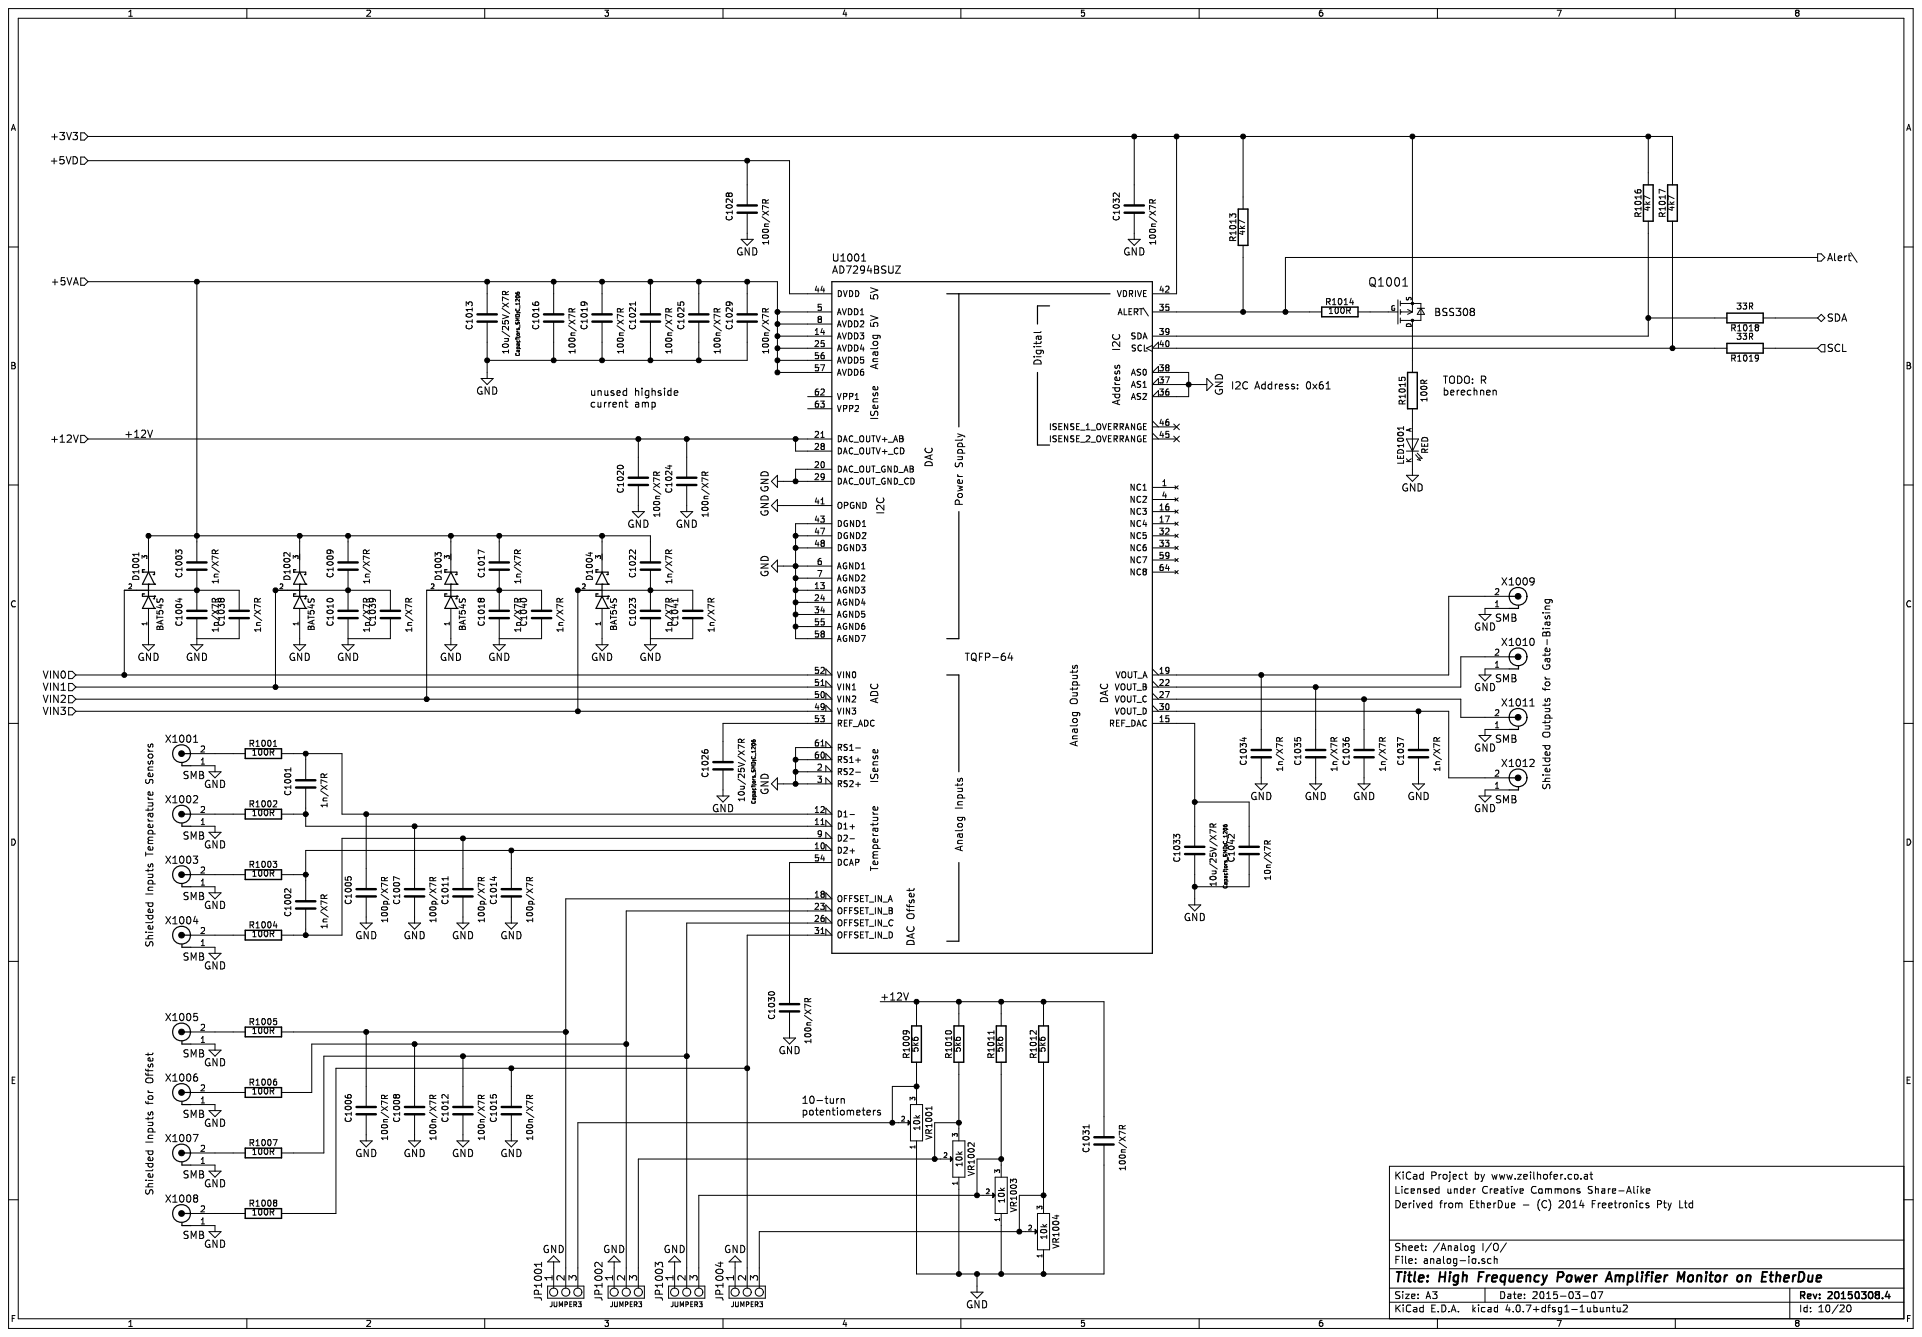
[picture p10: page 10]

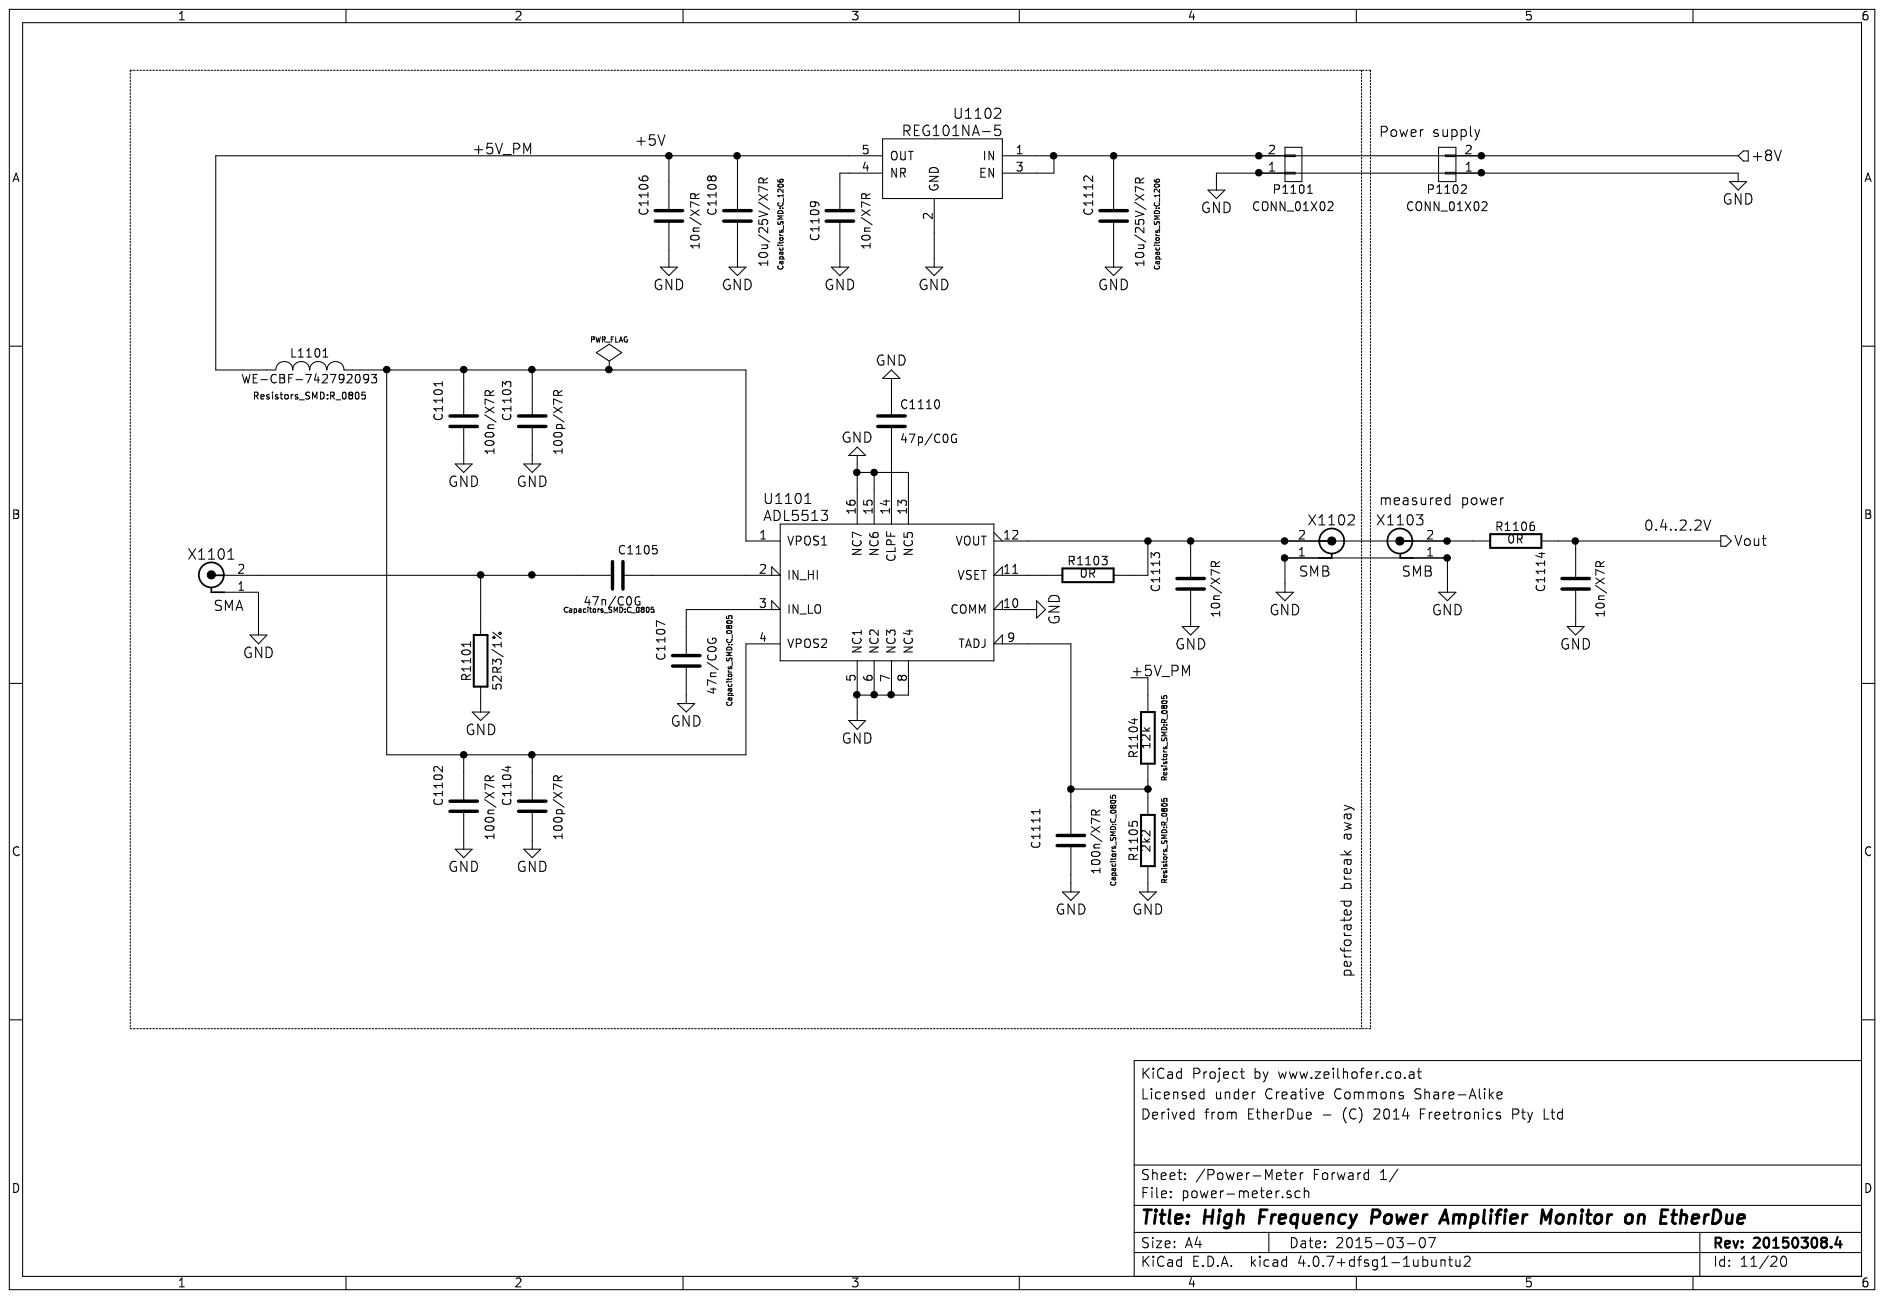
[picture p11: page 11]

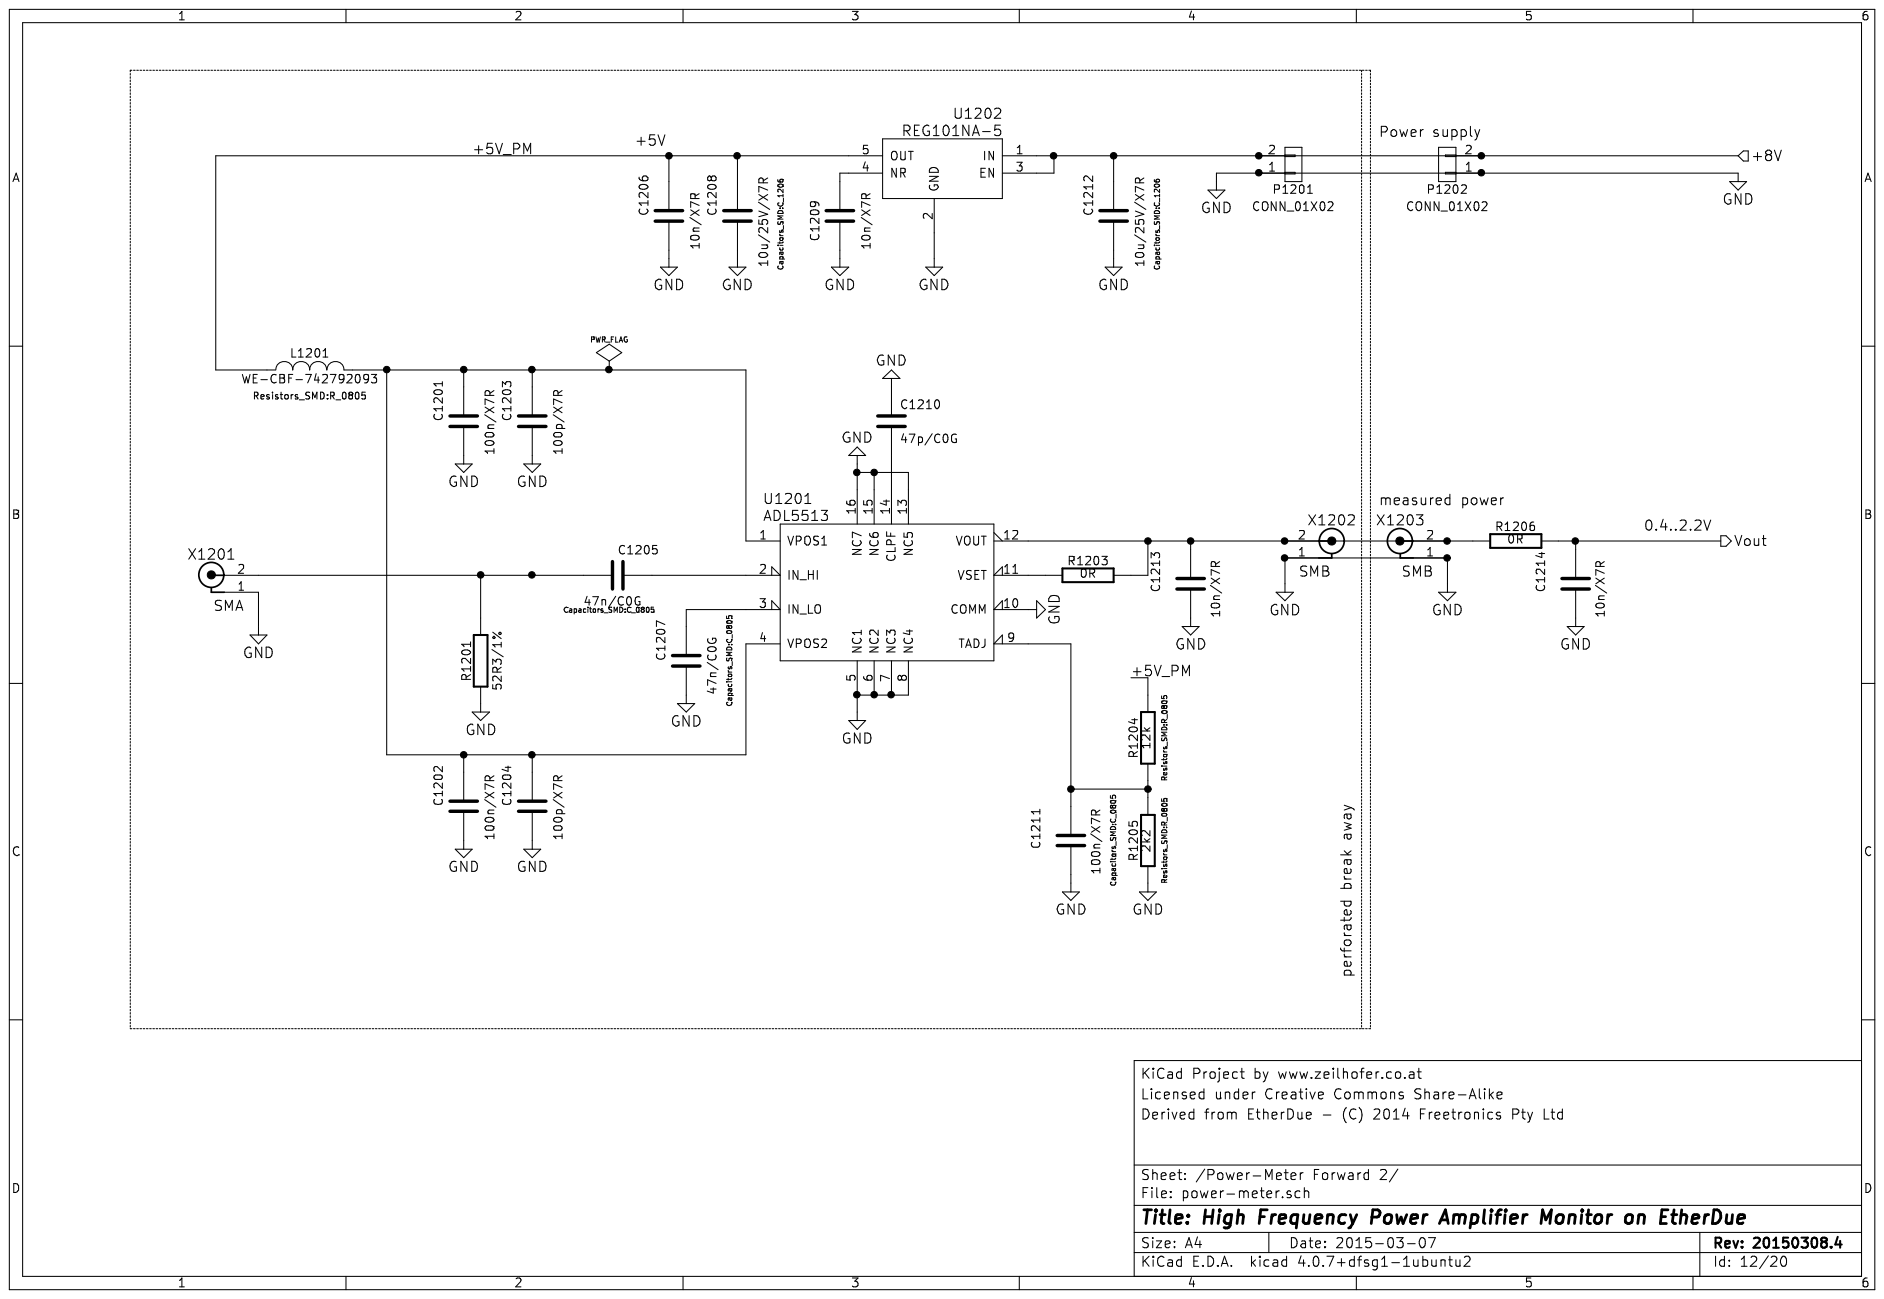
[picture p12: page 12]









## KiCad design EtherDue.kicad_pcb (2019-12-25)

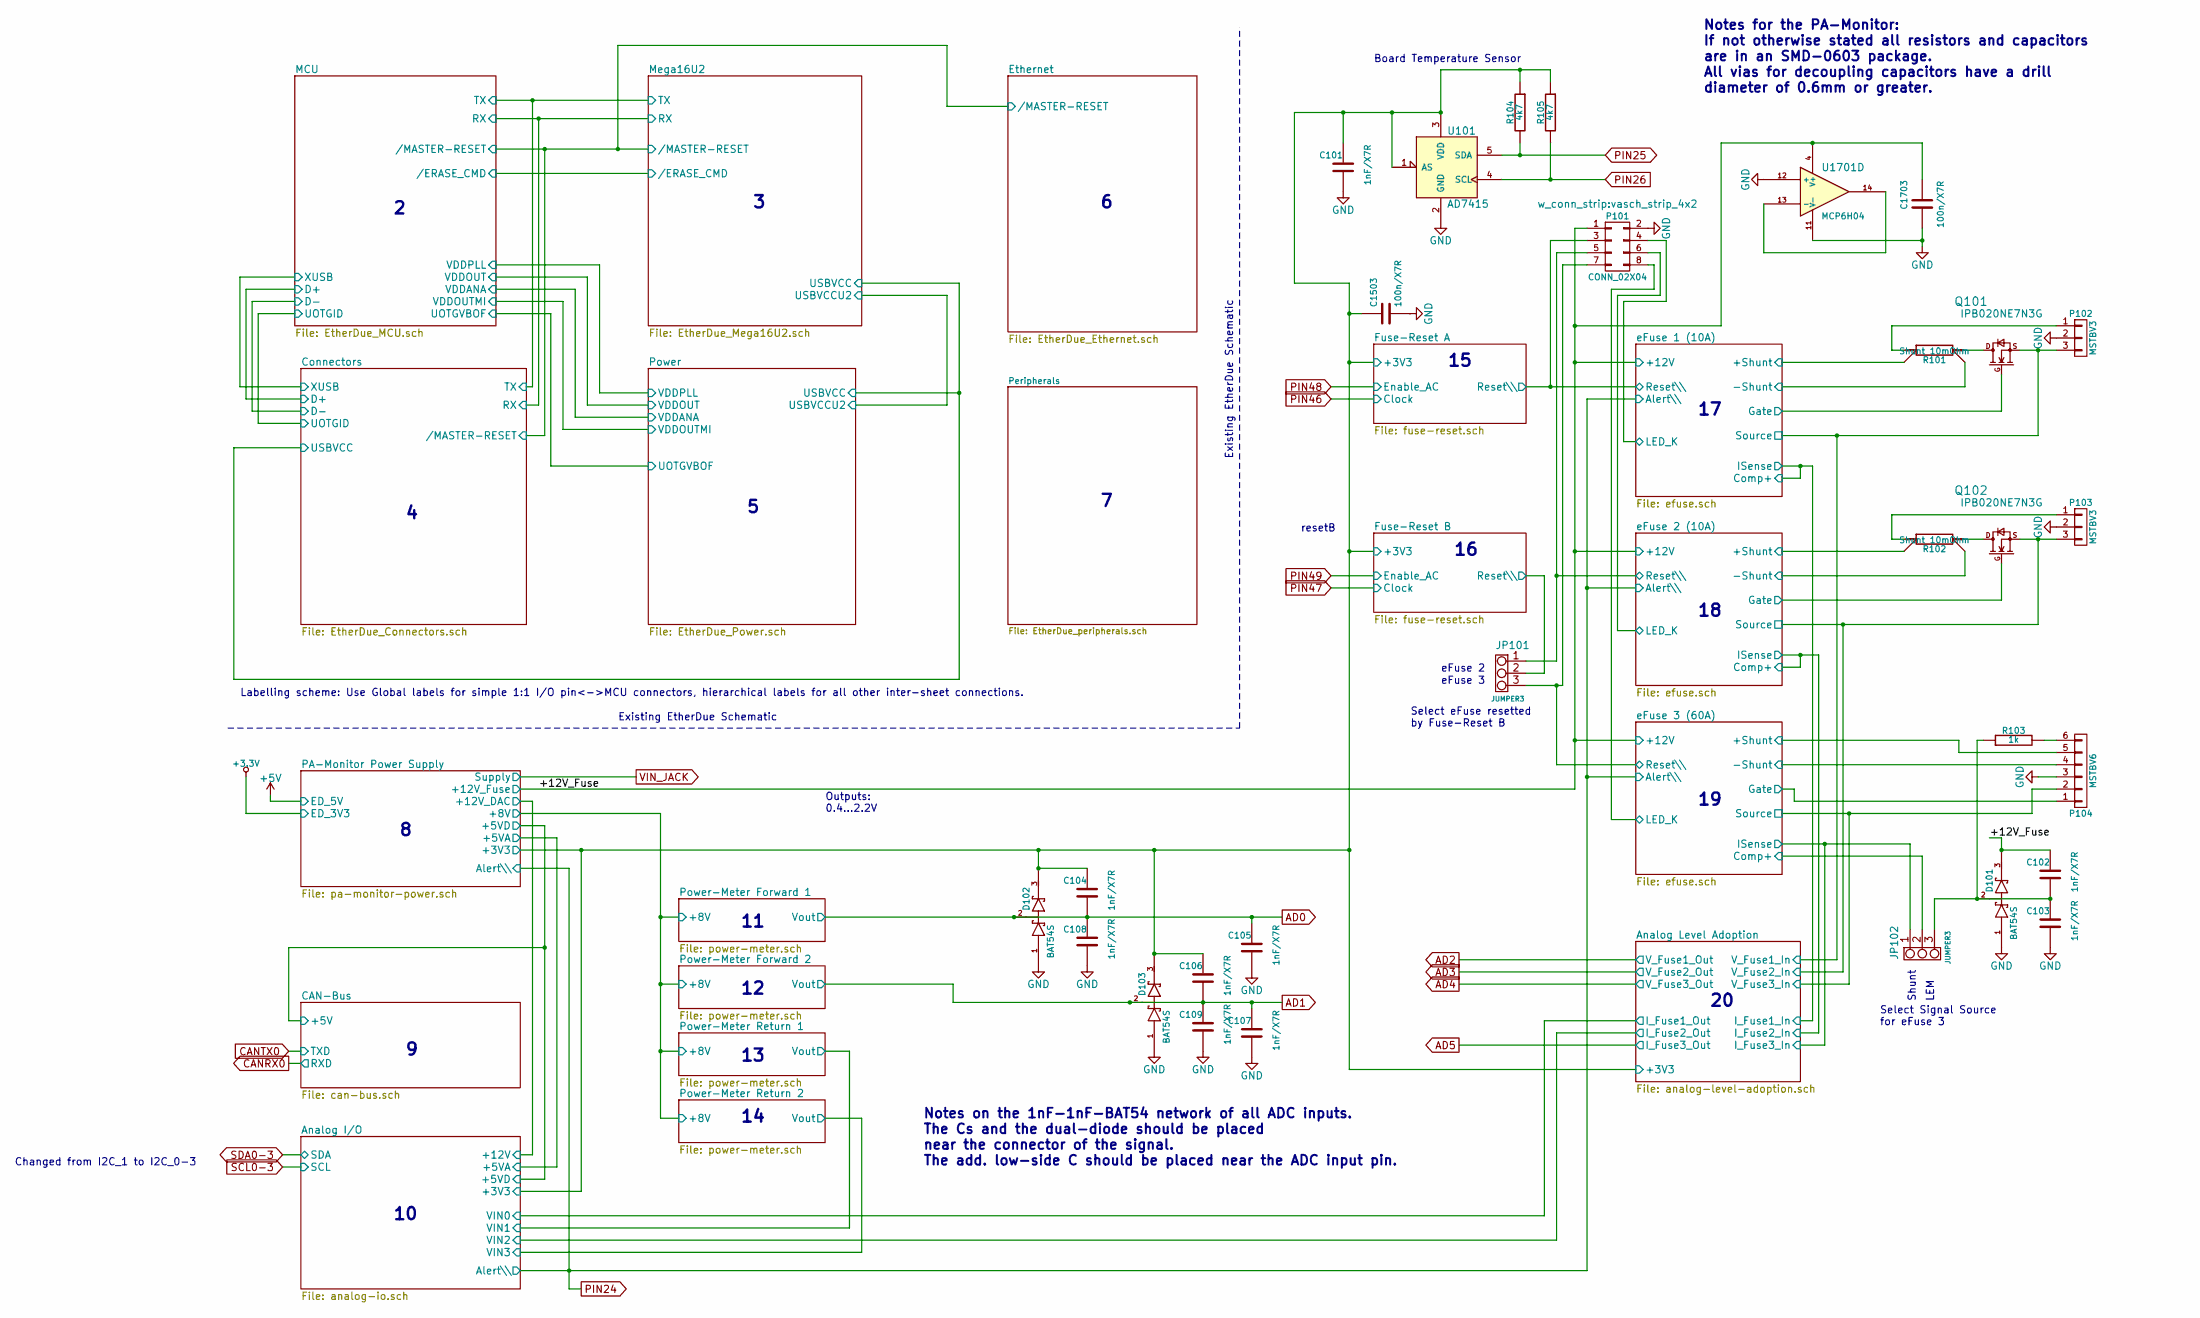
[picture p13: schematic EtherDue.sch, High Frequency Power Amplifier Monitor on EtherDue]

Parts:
C101, C102, C103, C104, C105, C106, C107, C108, C109: 1nF/X7R; C_0603
C1503, C1703: 100n/X7R; C_0603
D101, D102, D103: BAT54S; sot23
JP101, JP102: JUMPER3; Pin_Header_Straight_1x03
P101: CONN_02X04; vasch_strip_4x2
P102, P103: MSTBV3
P104: MSTBV6
Q101, Q102: IPB020NE7N3G; d2-pak
R101, R102: Shunt 10mOhm; WSL4026
R103: 1k; R_0603
R104, R105: 4k7; R_0603
U101: AD7415; SOT23-5
U1701: MCP6H04; SOIC-14_3.9x8.7mm_Pitch1.27mm

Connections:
/Analog I/O/+3V3: C101.1, C104.1, C106.1, C1503.1, D102.3 (cathode), D103.3 (cathode), R104.1, R105.1, U101.1 (AS), U101.3 (VDD); also elsewhere on the board
/Fuse-Reset B/Reset\: JP101.2; also elsewhere on the board
/eFuse 1 (10A)/+Shunt: R101.SA; also elsewhere on the board
/eFuse 1 (10A)/-Shunt: R101.SB; also elsewhere on the board
/eFuse 1 (10A)/Gate: Q101.G; also elsewhere on the board
/eFuse 1 (10A)/LED_K: P101.4; also elsewhere on the board
/eFuse 1 (10A)/Source: P102.3, Q101.S; also elsewhere on the board
/eFuse 2 (10A)/+Shunt: R102.SA; also elsewhere on the board
/eFuse 2 (10A)/-Shunt: R102.SB; also elsewhere on the board
/eFuse 2 (10A)/Gate: Q102.G; also elsewhere on the board
/eFuse 2 (10A)/LED_K: P101.6; also elsewhere on the board
/eFuse 2 (10A)/Reset\: JP101.1, P101.5; also elsewhere on the board
/eFuse 2 (10A)/Source: P103.3, Q102.S; also elsewhere on the board
/eFuse 3 (60A)/+Shunt: P104.5; also elsewhere on the board
/eFuse 3 (60A)/-Shunt: P104.4; also elsewhere on the board
/eFuse 3 (60A)/Comp+: JP102.2; also elsewhere on the board
/eFuse 3 (60A)/Gate: P104.1; also elsewhere on the board
/eFuse 3 (60A)/ISense: JP102.1; also elsewhere on the board
/eFuse 3 (60A)/LED_K: P101.8; also elsewhere on the board
/eFuse 3 (60A)/Reset\: JP101.3, P101.7; also elsewhere on the board
/eFuse 3 (60A)/Source: P104.2; also elsewhere on the board
AD0: C104.2, C105.1, C108.1, D102.2 (AK); also elsewhere on the board
AD1: C106.2, C107.1, C109.1, D103.2 (AK); also elsewhere on the board
unnamed: C102.2, C103.1, D101.2 (AK), JP102.3, R103.1
unnamed: P102.1, R101.A
unnamed: P103.1, R102.A
unnamed: P104.6, R103.2
unnamed: Q101.D, R101.B
unnamed: Q102.D, R102.B
unnamed: U1701.13 (-), U1701.14
PIN25: R104.2, U101.5 (SDA); also elsewhere on the board
PIN26: R105.2, U101.4 (SCL); also elsewhere on the board

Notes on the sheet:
Labelling scheme: Use Global labels for simple 1:1 I/O pin<->MCU connectors, hierarchical labels for all other inter-sheet connections.
Existing EtherDue Schematic
Outputs: 0.4...2.2V
resetB
Board Temperature Sensor
Notes for the PA-Monitor: If not otherwise stated all resistors and capacitors are in an SMD-0603 package. All vias for decoupling capacitors have a drill diameter of 0.6mm or greater.
Notes on the 1nF-1nF-BAT54 network of all ADC inputs. The Cs and the dual-diode should be placed near the connector of the signal. The add. low-side C should be placed near the ADC input pin.
Shunt
LEM
Select Signal Source for eFuse 3
Select eFuse resetted by Fuse-Reset B
eFuse 2
eFuse 3
Changed from I2C_1 to I2C_0-3

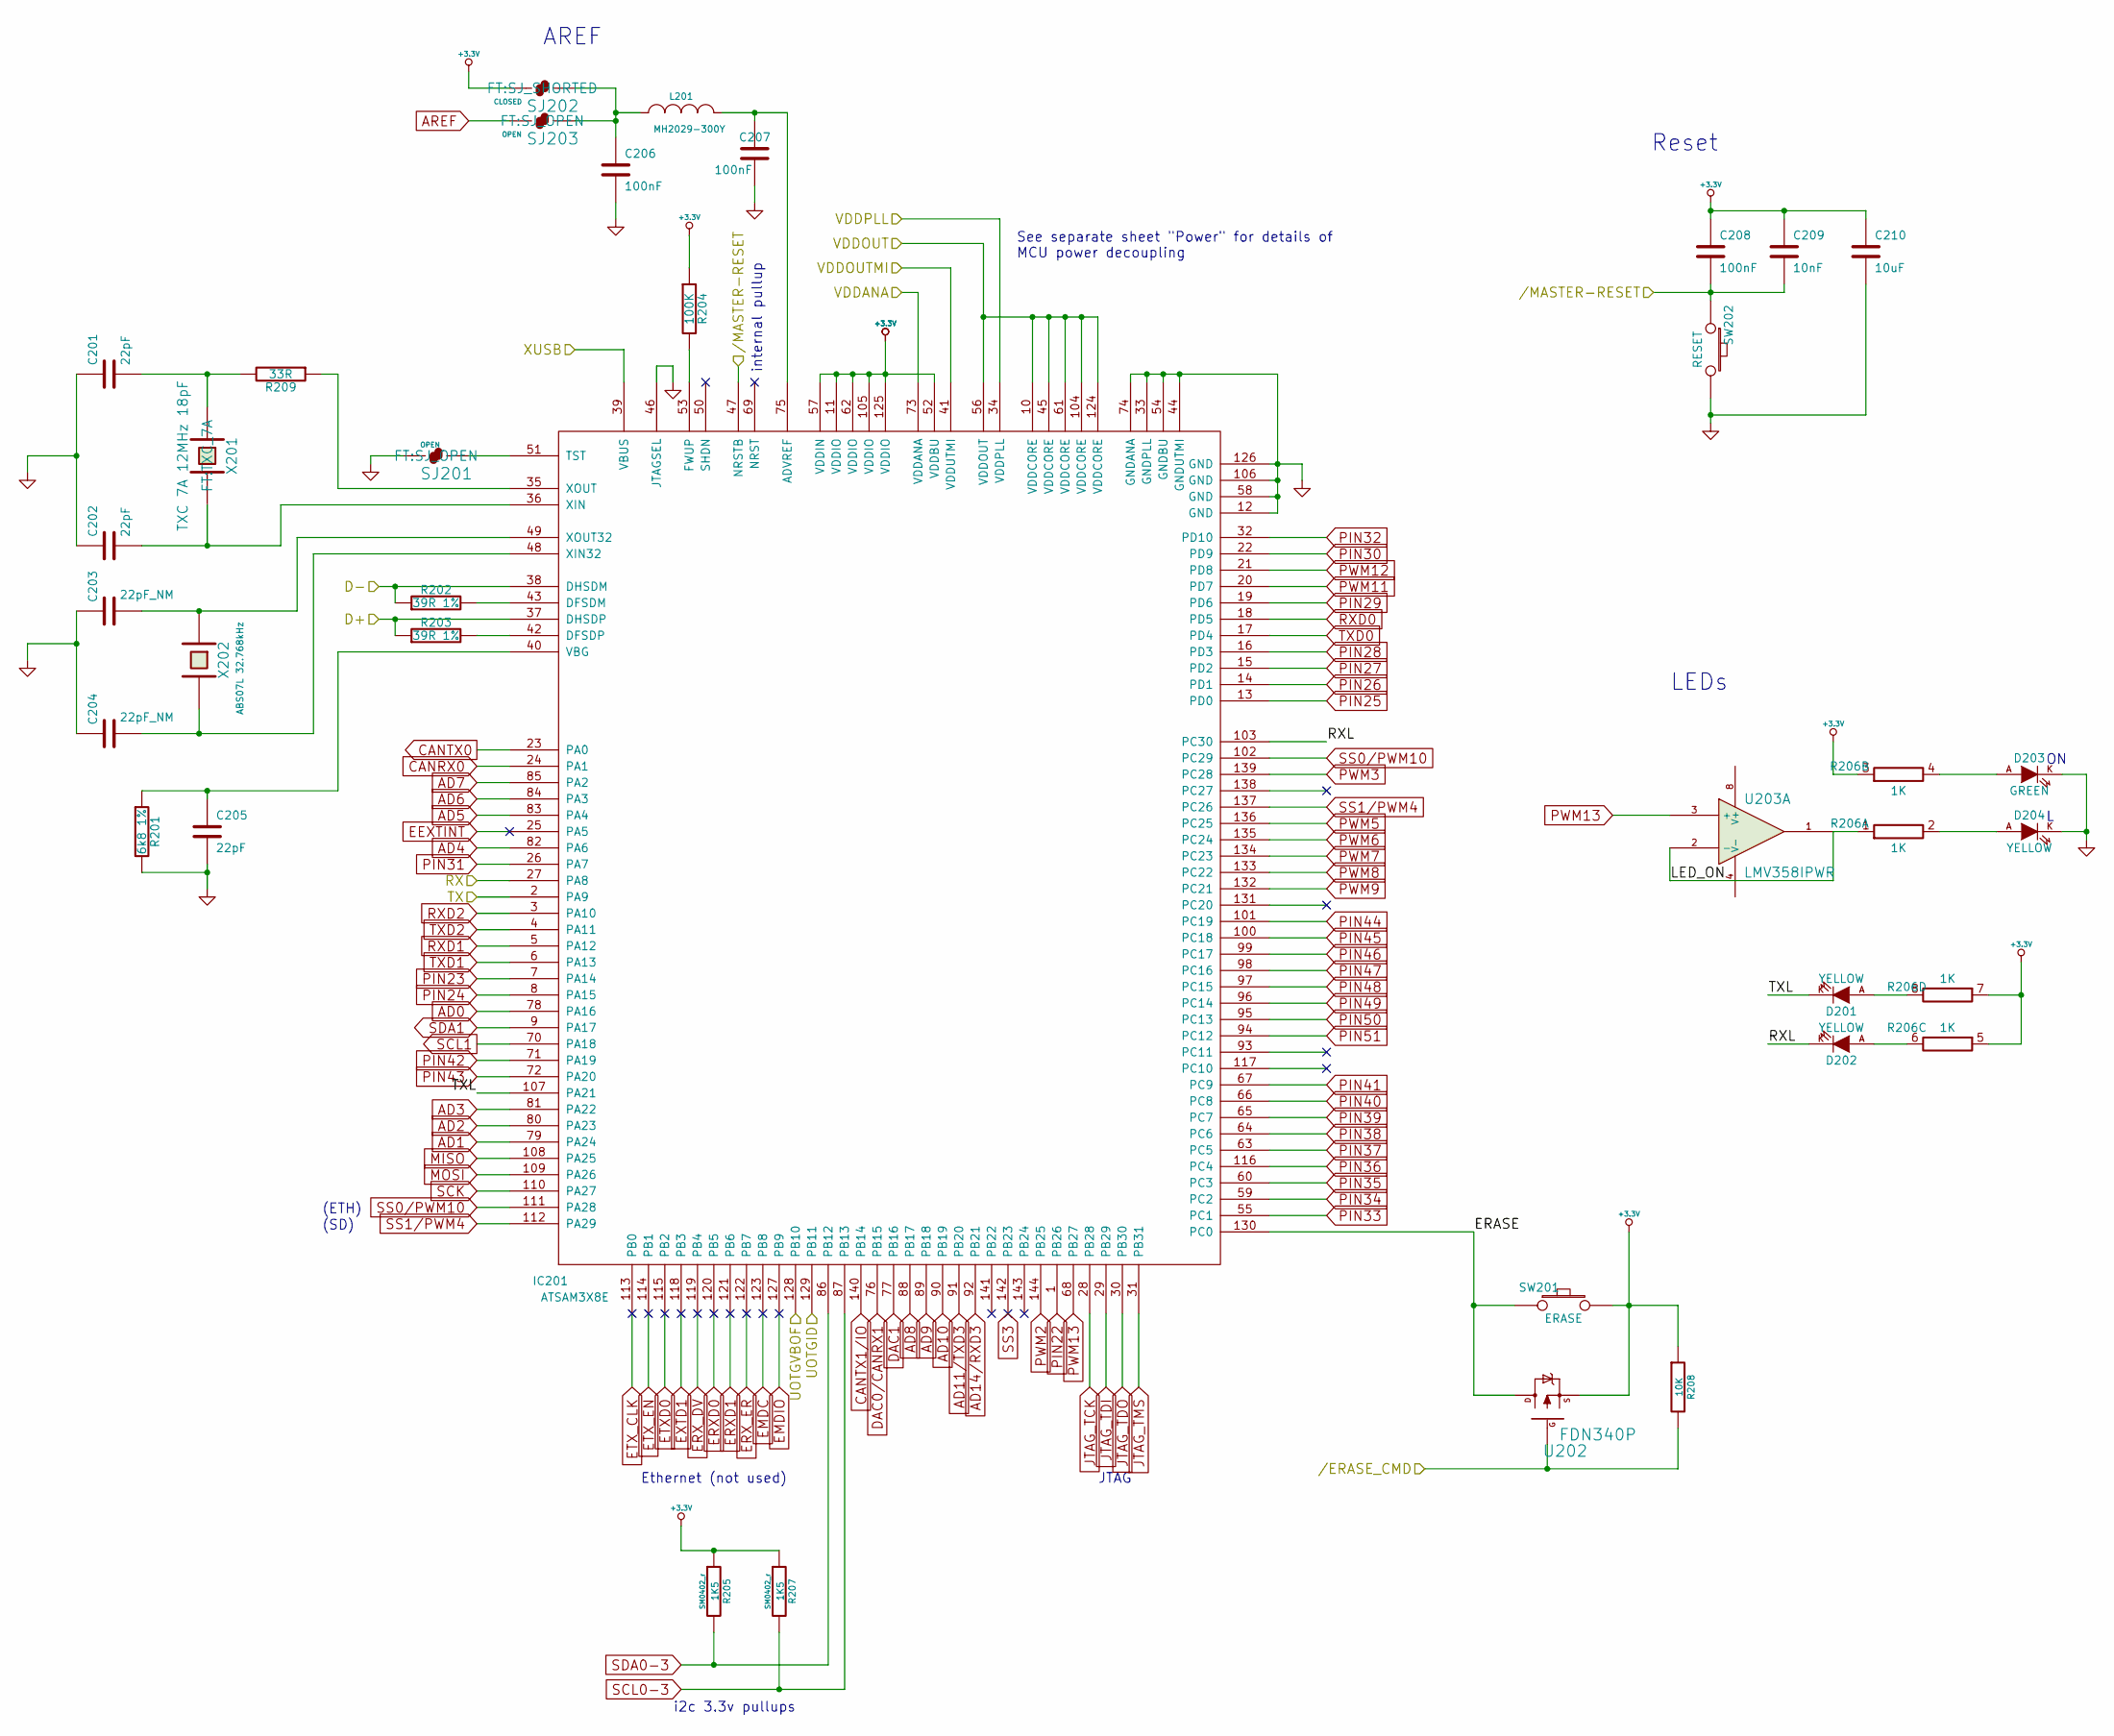
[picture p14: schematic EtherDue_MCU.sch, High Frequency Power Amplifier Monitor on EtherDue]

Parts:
C201, C202, C205: 22pF; SM0402
C203, C204: 22pF_NM; SM0402
C206, C207, C208: 100nF; SM0402
C209: 10nF; C0402
C210: 10uF; SM0603_Capa
D201, D202, D204: YELLOW; LED-0603
D203: GREEN; LED-0603
IC201: ATSAM3X8E; TQFP144
L201: MH2029-300Y; MH2029
R201: 6k8 1%; SM0402_r
R202, R203: 39R 1%; SM0402_r
R204: 100K; SM0402_r
R205, R207: 1K5; SM0402_r
R206: 1K; RES_CAY16
R208: 10K; SMD-0402_r
R209: 33R; R_0402
SJ201, SJ203: OPEN; SJ_OPEN
SJ202: CLOSED; SJ_SHORTED
SW201: ERASE; TACTILE_SWITCH_SMD_2PIN_TINY
SW202: RESET; TACTILE_SWITCH_SMD_2PIN_TINY
U202: FDN340P; SOT23_MOSFET
U203: LMV358IPWR; TSSOP8
X201: TXC 7A 12MHz 18pF; TXC_7A
X202: ABS07L 32.768kHz; ABS07L

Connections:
+3.3V: C208.1, C209.1, C210.1, IC201.11 (VDDIO), IC201.52 (VDDBU), IC201.57 (VDDIN), IC201.62 (VDDIO), IC201.105 (VDDIO), IC201.125 (VDDIO), R204.1, R205.1, R206.3 (7), R206.5 (7), R206.7, R207.1, R208.1, SJ202.1, SW201.2, U202.S; also elsewhere on the board
+5V: U203.8 (V+); also elsewhere on the board
/Connectors//MASTER-RESET: C208.2, C209.2, IC201.47 (NRSTB), SW202.1; also elsewhere on the board
/Connectors/D+: IC201.37 (DHSDP), R203.1; also elsewhere on the board
/Connectors/D-: IC201.38 (DHSDM), R202.1; also elsewhere on the board
/Connectors/RX: IC201.27 (PA8); also elsewhere on the board
/Connectors/TX: IC201.2 (PA9); also elsewhere on the board
/Connectors/UOTGID: IC201.129 (PB11); also elsewhere on the board
/Connectors/XUSB: IC201.39 (VBUS); also elsewhere on the board
/MCU//ERASE_CMD: R208.2, U202.G; also elsewhere on the board
/MCU/ERASE: IC201.130 (PC0), SW201.1, U202.D
/MCU/LED_ON: R206.1 (7), U203.1, U203.2 (-)
/MCU/RXL: D202.K, IC201.103 (PC30)
/MCU/TXL: D201.K, IC201.107 (PA21)
/MCU/UOTGVBOF: IC201.128 (PB10); also elsewhere on the board
/MCU/VDDANA: IC201.73 (VDDANA); also elsewhere on the board
/MCU/VDDOUT: IC201.10 (VDDCORE), IC201.45 (VDDCORE), IC201.56 (VDDOUT), IC201.61 (VDDCORE), IC201.104 (VDDCORE), IC201.124 (VDDCORE); also elsewhere on the board
/MCU/VDDOUTMI: IC201.41 (VDDUTMI); also elsewhere on the board
/MCU/VDDPLL: IC201.34 (VDDPLL); also elsewhere on the board
AD0: IC201.78 (PA16); also elsewhere on the board
AD1: IC201.79 (PA24); also elsewhere on the board
AD2: IC201.80 (PA23); also elsewhere on the board
AD3: IC201.81 (PA22); also elsewhere on the board
AD4: IC201.82 (PA6); also elsewhere on the board
AD5: IC201.83 (PA4); also elsewhere on the board
AD6: IC201.84 (PA3); also elsewhere on the board
AD7: IC201.85 (PA2); also elsewhere on the board
AD8: IC201.88 (PB17); also elsewhere on the board
AD9: IC201.89 (PB18); also elsewhere on the board
AD10: IC201.90 (PB19); also elsewhere on the board
AD11/TXD3: IC201.91 (PB20); also elsewhere on the board
AD14/RXD3: IC201.92 (PB21); also elsewhere on the board
AREF: SJ203.1; also elsewhere on the board
CANRX0: IC201.24 (PA1); also elsewhere on the board
CANTX0: IC201.23 (PA0); also elsewhere on the board
CANTX1/IO: IC201.140 (PB14); also elsewhere on the board
DAC0/CANRX1: IC201.76 (PB15); also elsewhere on the board
DAC1: IC201.77 (PB16); also elsewhere on the board
EEXTINT: IC201.25 (PA5)
EMDC: IC201.123 (PB8)
EMDIO: IC201.127 (PB9)
ERXD0: IC201.120 (PB5)
ERXD1: IC201.121 (PB6)
ERX_DV: IC201.119 (PB4)
ERX_ER: IC201.122 (PB7)
ETXD0: IC201.115 (PB2)
ETX_CLK: IC201.113 (PB0)
ETX_EN: IC201.114 (PB1)
EXTD1: IC201.118 (PB3)
JTAG_TCK: IC201.28 (PB28); also elsewhere on the board
JTAG_TDI: IC201.29 (PB29); also elsewhere on the board
JTAG_TDO: IC201.30 (PB30); also elsewhere on the board
JTAG_TMS: IC201.31 (PB31); also elsewhere on the board
MISO: IC201.108 (PA25); also elsewhere on the board
MOSI: IC201.109 (PA26); also elsewhere on the board
unnamed: C201.2, R209.2, X201.1
unnamed: C202.2, IC201.36 (XIN), X201.2
unnamed: C203.2, IC201.49 (XOUT32), X202.1
unnamed: C204.2, IC201.48 (XIN32), X202.2
unnamed: C205.1, IC201.40 (VBG), R201.1
unnamed: C206.1, L201.1, SJ202.2, SJ203.2
unnamed: C207.1, IC201.75 (ADVREF), L201.2
unnamed: D201.A, R206.8
unnamed: D202.A, R206.6 (8)
unnamed: D203.A, R206.4 (8)
unnamed: D204.A, R206.2 (8)
unnamed: IC201.35 (XOUT), R209.1
unnamed: IC201.42 (DFSDP), R203.2
unnamed: IC201.43 (DFSDM), R202.2
unnamed: IC201.51 (TST), SJ201.2
unnamed: IC201.53 (FWUP), R204.2
PIN22: IC201.1 (PB26); also elsewhere on the board
PIN23: IC201.7 (PA14); also elsewhere on the board
PIN24: IC201.8 (PA15); also elsewhere on the board
PIN25: IC201.13 (PD0); also elsewhere on the board
PIN26: IC201.14 (PD1); also elsewhere on the board
PIN27: IC201.15 (PD2); also elsewhere on the board
PIN28: IC201.16 (PD3); also elsewhere on the board
PIN29: IC201.19 (PD6); also elsewhere on the board
PIN30: IC201.22 (PD9); also elsewhere on the board
PIN31: IC201.26 (PA7); also elsewhere on the board
PIN32: IC201.32 (PD10); also elsewhere on the board
PIN33: IC201.55 (PC1); also elsewhere on the board
PIN34: IC201.59 (PC2); also elsewhere on the board
PIN35: IC201.60 (PC3); also elsewhere on the board
PIN36: IC201.116 (PC4); also elsewhere on the board
PIN37: IC201.63 (PC5); also elsewhere on the board
PIN38: IC201.64 (PC6); also elsewhere on the board
PIN39: IC201.65 (PC7); also elsewhere on the board
PIN40: IC201.66 (PC8); also elsewhere on the board
PIN41: IC201.67 (PC9); also elsewhere on the board
PIN42: IC201.71 (PA19); also elsewhere on the board
PIN43: IC201.72 (PA20); also elsewhere on the board
PIN44: IC201.101 (PC19); also elsewhere on the board
PIN45: IC201.100 (PC18); also elsewhere on the board
PIN46: IC201.99 (PC17); also elsewhere on the board
PIN47: IC201.98 (PC16); also elsewhere on the board
PIN48: IC201.97 (PC15); also elsewhere on the board
PIN49: IC201.96 (PC14); also elsewhere on the board
PIN50: IC201.95 (PC13); also elsewhere on the board
PIN51: IC201.94 (PC12); also elsewhere on the board
PWM2: IC201.144 (PB25); also elsewhere on the board
PWM3: IC201.139 (PC28); also elsewhere on the board
PWM5: IC201.136 (PC25); also elsewhere on the board
PWM6: IC201.135 (PC24); also elsewhere on the board
PWM7: IC201.134 (PC23); also elsewhere on the board
PWM8: IC201.133 (PC22); also elsewhere on the board
PWM9: IC201.132 (PC21); also elsewhere on the board
PWM11: IC201.20 (PD7); also elsewhere on the board
PWM12: IC201.21 (PD8); also elsewhere on the board
PWM13: IC201.68 (PB27), U203.3 (+); also elsewhere on the board
RXD0: IC201.18 (PD5); also elsewhere on the board
RXD1: IC201.5 (PA12); also elsewhere on the board
RXD2: IC201.3 (PA10); also elsewhere on the board
SCK: IC201.110 (PA27); also elsewhere on the board
SCL0-3: IC201.87 (PB13), R207.2; also elsewhere on the board
SCL1: IC201.70 (PA18); also elsewhere on the board
SDA0-3: IC201.86 (PB12), R205.2; also elsewhere on the board
SDA1: IC201.9 (PA17); also elsewhere on the board
SS0/PWM10: IC201.102 (PC29), IC201.111 (PA28); also elsewhere on the board
SS1/PWM4: IC201.112 (PA29), IC201.137 (PC26); also elsewhere on the board
SS3: IC201.142 (PB23)
TXD0: IC201.17 (PD4); also elsewhere on the board
TXD1: IC201.6 (PA13); also elsewhere on the board
TXD2: IC201.4 (PA11); also elsewhere on the board

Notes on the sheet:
i2c 3.3v pullups
Ethernet (not used)
JTAG
See separate sheet "Power" for details of MCU power decoupling
Reset
LEDs
AREF
(SD)
(ETH)
internal pullup

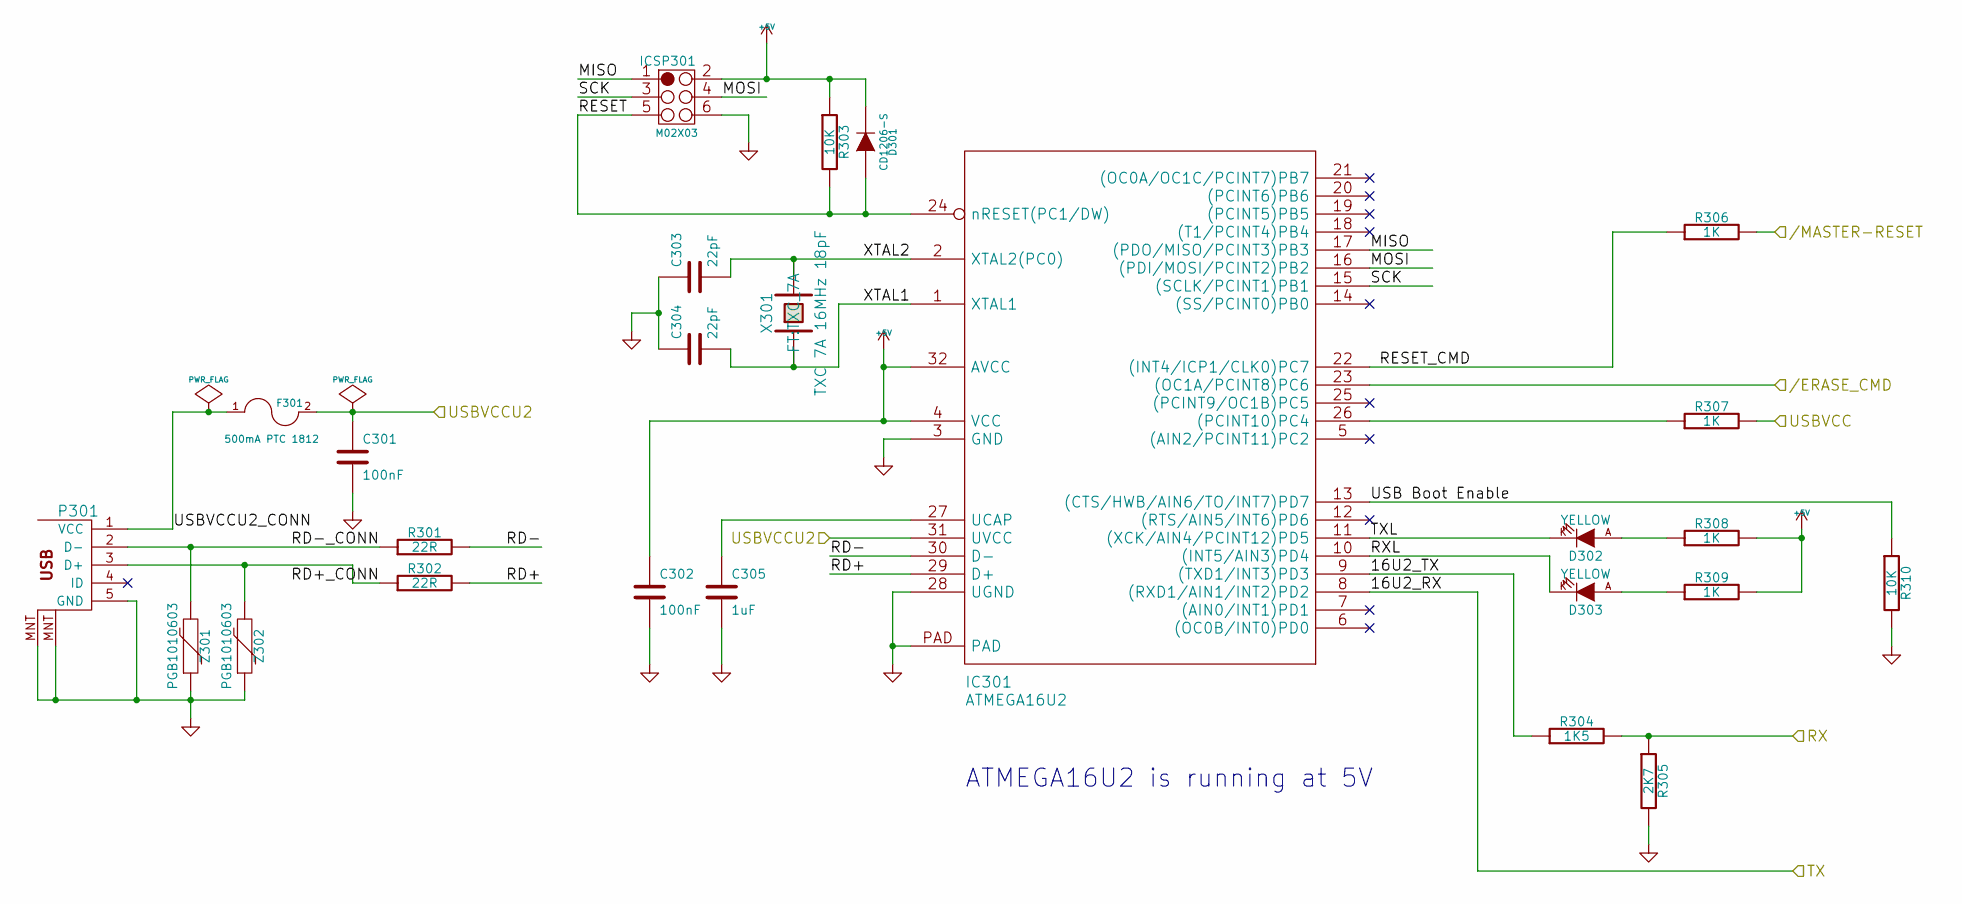
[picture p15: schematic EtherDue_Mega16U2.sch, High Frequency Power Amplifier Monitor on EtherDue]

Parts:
C301, C302: 100nF; SM0402
C303, C304: 22pF; SM0402
C305: 1uF; SM0402
D301: CD1206-S; 1206_DIODE
D302, D303: YELLOW; LED-0603
F301: 500mA PTC 1812; SM1812
IC301: ATMEGA16U2; QFN32
ICSP301: M02X03; Pin_Header_Straight_2x03
P301: USB_5PIN_SHELL; USB-MICRO_TH_4PEGS
R301, R302: 22R; SM0402_r
R303, R310: 10K; SM0402_r
R304: 1K5; SM0402_r
R305: 2K7; SM0402_r
R306, R307, R308, R309: 1K; SM0402_r
X301: TXC 7A 16MHz 18pF; TXC_7A
Z301, Z302: PGB1010603; 0603

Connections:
+5V: C302.1, D301.K, IC301.4 (VCC), IC301.32 (AVCC), ICSP301.2, R303.1, R308.2, R309.2; also elsewhere on the board
/Connectors//MASTER-RESET: R306.2; also elsewhere on the board
/Connectors/RX: R304.2, R305.1; also elsewhere on the board
/Connectors/TX: IC301.8 ((RXD1/AIN1/INT2)PD2); also elsewhere on the board
/Connectors/USBVCC: R307.2; also elsewhere on the board
/MCU//ERASE_CMD: IC301.23 ((OC1A/PCINT8)PC6); also elsewhere on the board
/Mega16U2/16U2_TX: IC301.9 ((TXD1/INT3)PD3), R304.1
/Mega16U2/MISO: IC301.17 ((PDO/MISO/PCINT3)PB3), ICSP301.1
/Mega16U2/MOSI: IC301.16 ((PDI/MOSI/PCINT2)PB2), ICSP301.4
/Mega16U2/RD+: IC301.29 (D+), R302.2
/Mega16U2/RD+_CONN: P301.3 (D+), R302.1, Z302.2
/Mega16U2/RD-: IC301.30 (D-), R301.2
/Mega16U2/RD-_CONN: P301.2 (D-), R301.1, Z301.2
/Mega16U2/RESET: D301.A, IC301.24 (nRESET(PC1/DW)), ICSP301.5, R303.2
/Mega16U2/RESET_CMD: IC301.22 ((INT4/ICP1/CLK0)PC7), R306.1
/Mega16U2/RXL: D303.K, IC301.10 ((INT5/AIN3)PD4)
/Mega16U2/SCK: IC301.15 ((SCLK/PCINT1)PB1), ICSP301.3
/Mega16U2/TXL: D302.K, IC301.11 ((XCK/AIN4/PCINT12)PD5)
/Mega16U2/USB Boot Enable: IC301.13 ((CTS/HWB/AIN6/TO/INT7)PD7), R310.1
/Mega16U2/USBVCCU2: C301.1, F301.2, IC301.31 (UVCC); also elsewhere on the board
/Mega16U2/USBVCCU2_CONN: F301.1, P301.1 (VCC)
/Mega16U2/XTAL1: C304.2, IC301.1 (XTAL1), X301.1
/Mega16U2/XTAL2: C303.2, IC301.2 (XTAL2(PC0)), X301.2
unnamed: C305.1, IC301.27 (UCAP)
unnamed: D302.A, R308.1
unnamed: D303.A, R309.1
unnamed: IC301.26 ((PCINT10)PC4), R307.1

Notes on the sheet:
ATMEGA16U2 is running at 5V

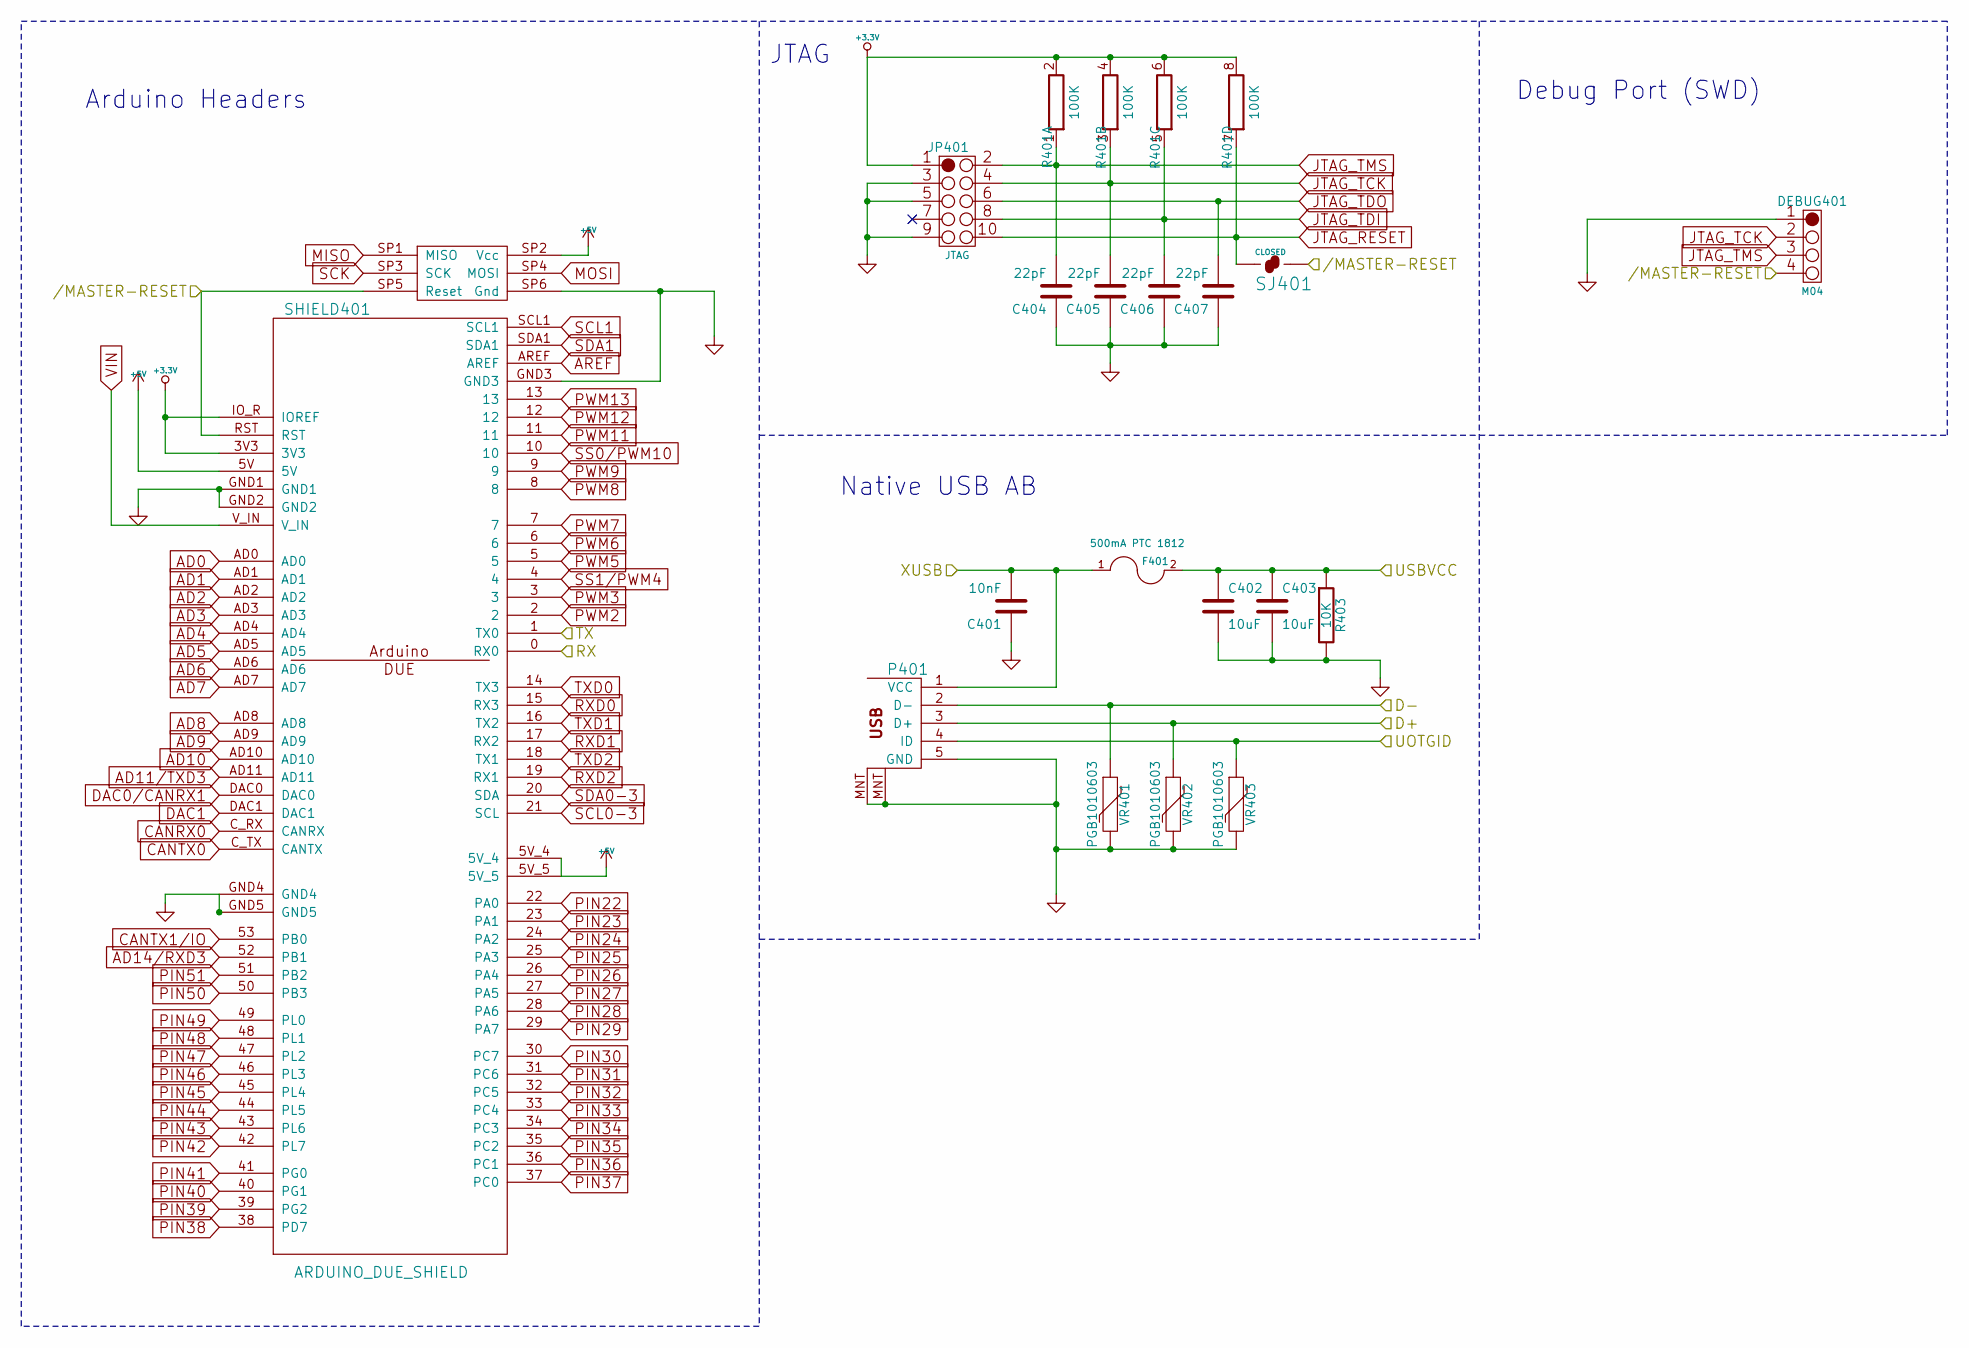
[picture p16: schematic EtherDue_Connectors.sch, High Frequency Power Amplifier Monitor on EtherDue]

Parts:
C401: 10nF; SM0402
C402, C403: 10uF; SM0603_Capa
C404, C405, C406, C407: 22pF; C0402
DEBUG401: M04; Pin_Header_Straight_1x04
F401: 500mA PTC 1812; SM1812
JP401: JTAG; 2X5_127MMPITCH
P401: USB_5PIN_SHELL; USB-MICRO_TH_4PEGS
R401: 100K; RES_CAY16
R403: 10K; SM0402_r
SHIELD401: ARDUINO_DUE_SHIELD
SJ401: CLOSED; SJ_SHORTED
VR401, VR402, VR403: PGB1010603; 0603

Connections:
+3.3V: JP401.1, R401.2 (8), R401.4 (8), R401.6 (8), R401.8, SHIELD401.3V3, SHIELD401.IO_R (IOREF); also elsewhere on the board
+5V: SHIELD401.5V, SHIELD401.5V_4, SHIELD401.5V_5, SHIELD401.SP2 (Vcc); also elsewhere on the board
/Connectors//MASTER-RESET: DEBUG401.4, SHIELD401.RST, SHIELD401.SP5 (Reset), SJ401.2; also elsewhere on the board
/Connectors/D+: P401.3 (D+), VR402.1; also elsewhere on the board
/Connectors/D-: P401.2 (D-), VR401.1; also elsewhere on the board
/Connectors/RX: SHIELD401.0 (RX0); also elsewhere on the board
/Connectors/TX: SHIELD401.1 (TX0); also elsewhere on the board
/Connectors/UOTGID: P401.4 (ID), VR403.1; also elsewhere on the board
/Connectors/USBVCC: C402.1, C403.1, F401.2, R403.1; also elsewhere on the board
/Connectors/XUSB: C401.2, F401.1, P401.1 (VCC); also elsewhere on the board
AD0: SHIELD401.AD0; also elsewhere on the board
AD1: SHIELD401.AD1; also elsewhere on the board
AD2: SHIELD401.AD2; also elsewhere on the board
AD3: SHIELD401.AD3; also elsewhere on the board
AD4: SHIELD401.AD4; also elsewhere on the board
AD5: SHIELD401.AD5; also elsewhere on the board
AD6: SHIELD401.AD6; also elsewhere on the board
AD7: SHIELD401.AD7; also elsewhere on the board
AD8: SHIELD401.AD8; also elsewhere on the board
AD9: SHIELD401.AD9; also elsewhere on the board
AD10: SHIELD401.AD10; also elsewhere on the board
AD11/TXD3: SHIELD401.AD11; also elsewhere on the board
AD14/RXD3: SHIELD401.52 (PB1); also elsewhere on the board
AREF: SHIELD401.AREF; also elsewhere on the board
CANRX0: SHIELD401.C_RX (CANRX); also elsewhere on the board
CANTX0: SHIELD401.C_TX (CANTX); also elsewhere on the board
CANTX1/IO: SHIELD401.53 (PB0); also elsewhere on the board
DAC0/CANRX1: SHIELD401.DAC0; also elsewhere on the board
DAC1: SHIELD401.DAC1; also elsewhere on the board
JTAG_RESET: JP401.10, R401.7, SJ401.1
JTAG_TCK: C405.2, DEBUG401.2, JP401.4, R401.3 (7); also elsewhere on the board
JTAG_TDI: C406.2, JP401.8, R401.5 (7); also elsewhere on the board
JTAG_TDO: C407.2, JP401.6; also elsewhere on the board
JTAG_TMS: C404.2, DEBUG401.3, JP401.2, R401.1 (7); also elsewhere on the board
MISO: SHIELD401.SP1 (MISO); also elsewhere on the board
MOSI: SHIELD401.SP4 (MOSI); also elsewhere on the board
PIN22: SHIELD401.22 (PA0); also elsewhere on the board
PIN23: SHIELD401.23 (PA1); also elsewhere on the board
PIN24: SHIELD401.24 (PA2); also elsewhere on the board
PIN25: SHIELD401.25 (PA3); also elsewhere on the board
PIN26: SHIELD401.26 (PA4); also elsewhere on the board
PIN27: SHIELD401.27 (PA5); also elsewhere on the board
PIN28: SHIELD401.28 (PA6); also elsewhere on the board
PIN29: SHIELD401.29 (PA7); also elsewhere on the board
PIN30: SHIELD401.30 (PC7); also elsewhere on the board
PIN31: SHIELD401.31 (PC6); also elsewhere on the board
PIN32: SHIELD401.32 (PC5); also elsewhere on the board
PIN33: SHIELD401.33 (PC4); also elsewhere on the board
PIN34: SHIELD401.34 (PC3); also elsewhere on the board
PIN35: SHIELD401.35 (PC2); also elsewhere on the board
PIN36: SHIELD401.36 (PC1); also elsewhere on the board
PIN37: SHIELD401.37 (PC0); also elsewhere on the board
PIN38: SHIELD401.38 (PD7); also elsewhere on the board
PIN39: SHIELD401.39 (PG2); also elsewhere on the board
PIN40: SHIELD401.40 (PG1); also elsewhere on the board
PIN41: SHIELD401.41 (PG0); also elsewhere on the board
PIN42: SHIELD401.42 (PL7); also elsewhere on the board
PIN43: SHIELD401.43 (PL6); also elsewhere on the board
PIN44: SHIELD401.44 (PL5); also elsewhere on the board
PIN45: SHIELD401.45 (PL4); also elsewhere on the board
PIN46: SHIELD401.46 (PL3); also elsewhere on the board
PIN47: SHIELD401.47 (PL2); also elsewhere on the board
PIN48: SHIELD401.48 (PL1); also elsewhere on the board
PIN49: SHIELD401.49 (PL0); also elsewhere on the board
PIN50: SHIELD401.50 (PB3); also elsewhere on the board
PIN51: SHIELD401.51 (PB2); also elsewhere on the board
PWM2: SHIELD401.2; also elsewhere on the board
PWM3: SHIELD401.3; also elsewhere on the board
PWM5: SHIELD401.5; also elsewhere on the board
PWM6: SHIELD401.6; also elsewhere on the board
PWM7: SHIELD401.7; also elsewhere on the board
PWM8: SHIELD401.8; also elsewhere on the board
PWM9: SHIELD401.9; also elsewhere on the board
PWM11: SHIELD401.11; also elsewhere on the board
PWM12: SHIELD401.12; also elsewhere on the board
PWM13: SHIELD401.13; also elsewhere on the board
RXD0: SHIELD401.15 (RX3); also elsewhere on the board
RXD1: SHIELD401.17 (RX2); also elsewhere on the board
RXD2: SHIELD401.19 (RX1); also elsewhere on the board
SCK: SHIELD401.SP3 (SCK); also elsewhere on the board
SCL0-3: SHIELD401.21 (SCL); also elsewhere on the board
SCL1: SHIELD401.SCL1; also elsewhere on the board
SDA0-3: SHIELD401.20 (SDA); also elsewhere on the board
SDA1: SHIELD401.SDA1; also elsewhere on the board
SS0/PWM10: SHIELD401.10; also elsewhere on the board
SS1/PWM4: SHIELD401.4; also elsewhere on the board
TXD0: SHIELD401.14 (TX3); also elsewhere on the board
TXD1: SHIELD401.16 (TX2); also elsewhere on the board
TXD2: SHIELD401.18 (TX1); also elsewhere on the board
VIN: SHIELD401.V_IN; also elsewhere on the board

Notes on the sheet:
Debug Port (SWD)
Native USB AB
JTAG
Arduino Headers

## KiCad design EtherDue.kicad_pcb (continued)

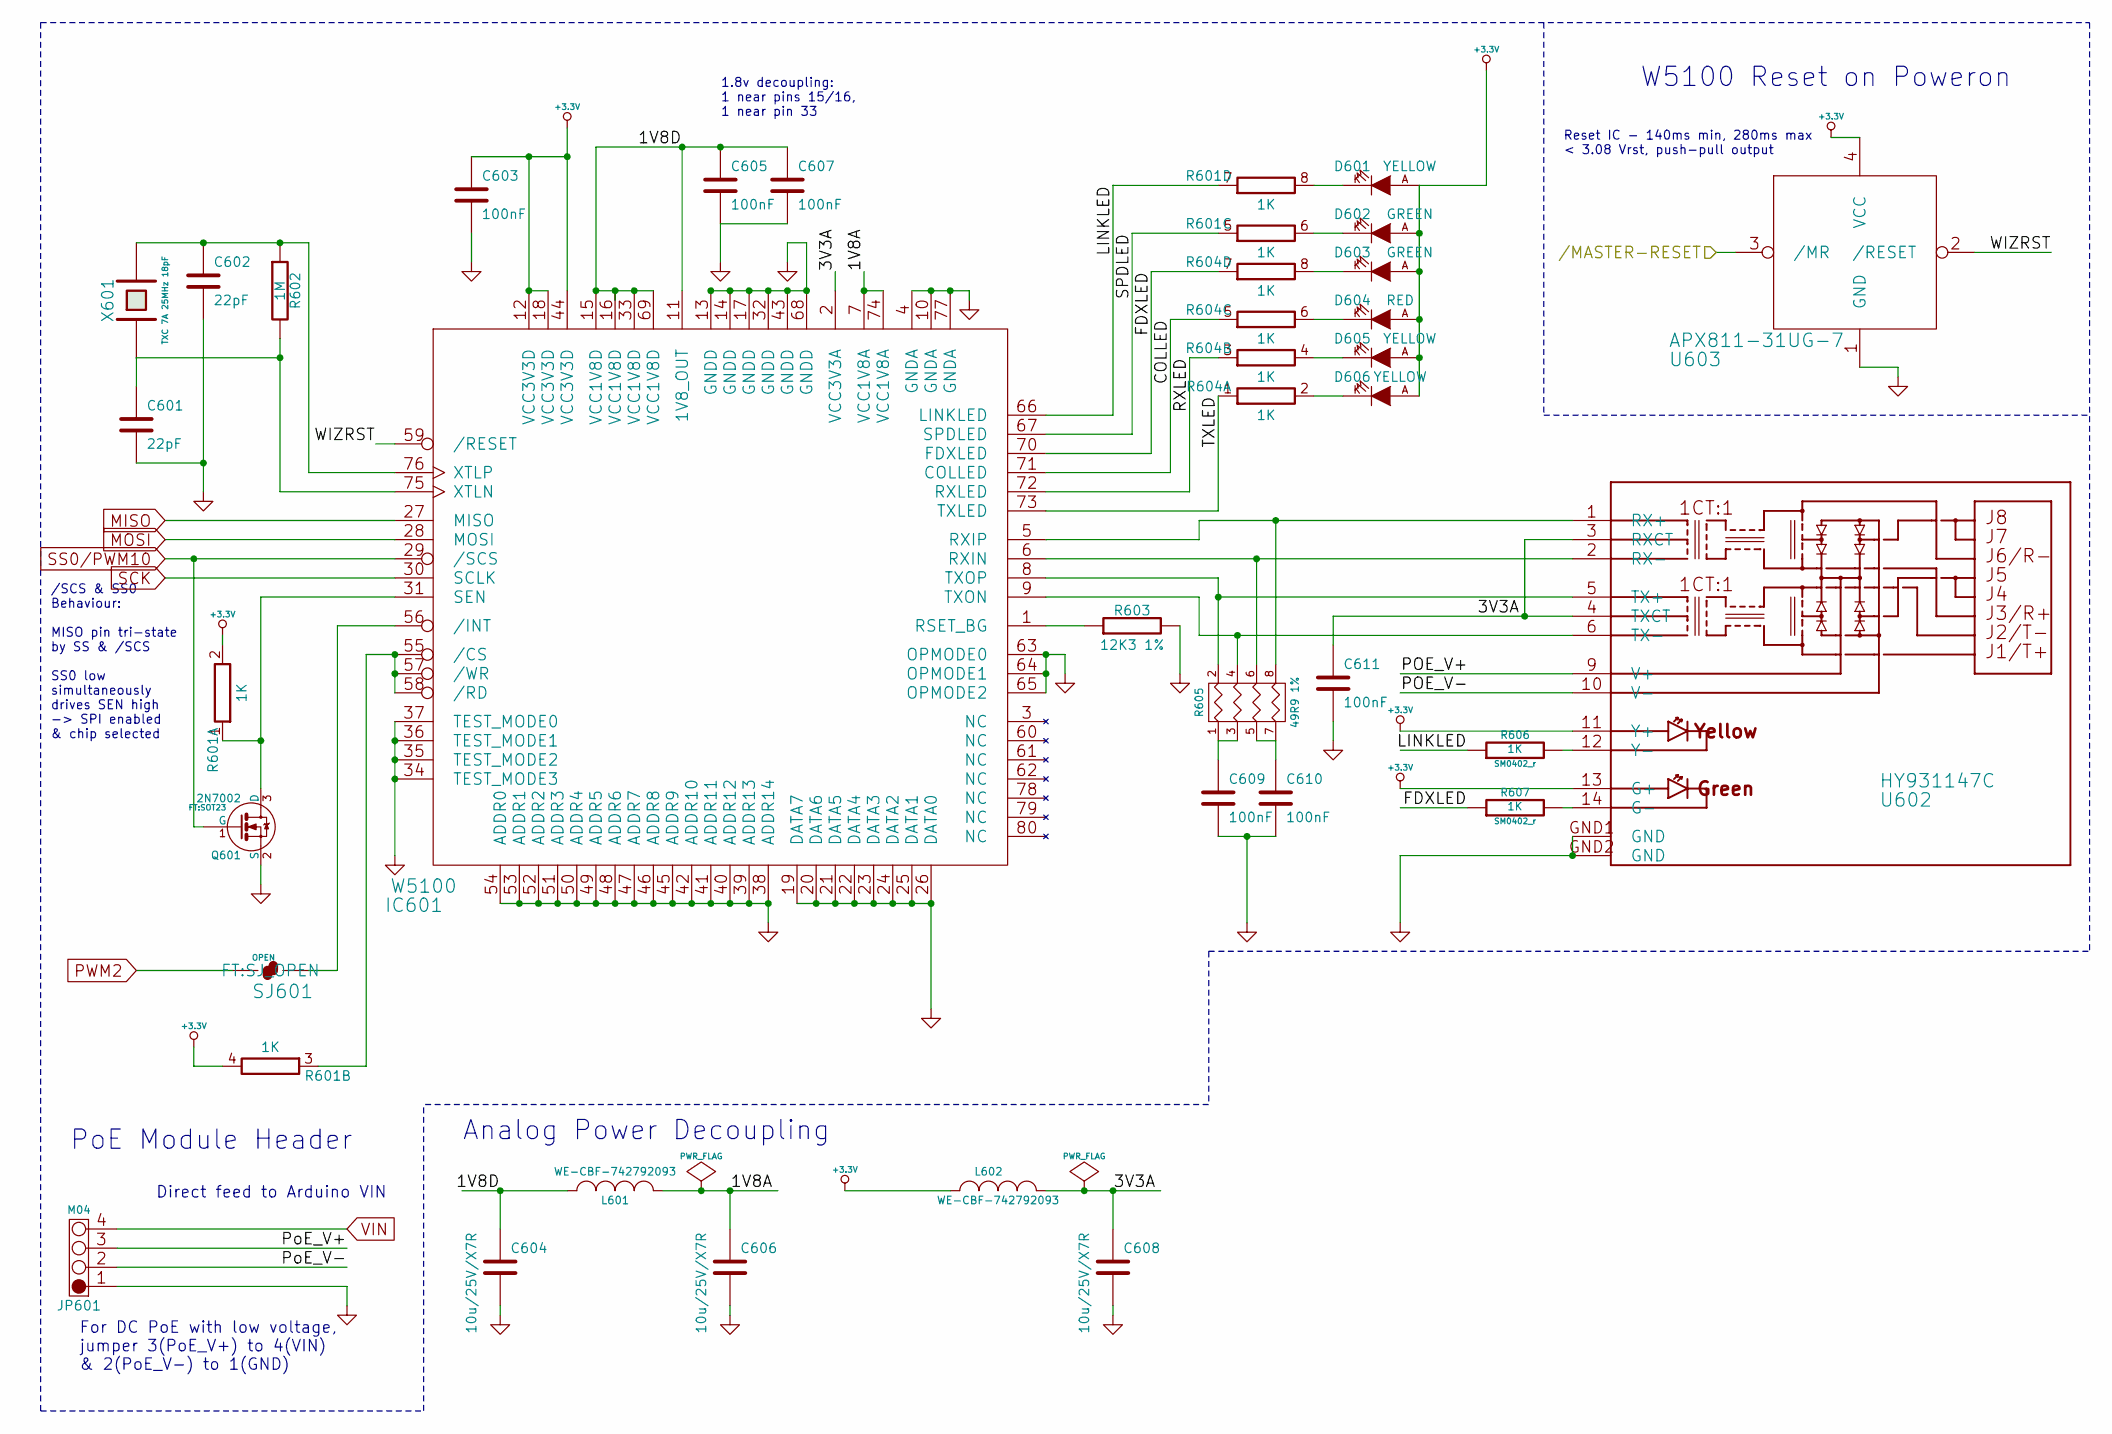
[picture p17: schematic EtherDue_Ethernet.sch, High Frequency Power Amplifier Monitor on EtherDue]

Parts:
C601, C602: 22pF; SM0402
C603, C605, C607, C609, C610, C611: 100nF; SM0402
C604, C606, C608: 10u/25V/X7R; SMD-1206_Pol
D601, D605, D606: YELLOW; LED-0603
D602, D603: GREEN; LED-0603
D604: RED; LED-0603
IC601: W5100; SQFP80
JP601: M04; FT-POE-MODULE-NOOUTLINE
L601, L602: WE-CBF-742792093; 0805
Q601: 2N7002; SOT23
R601, R604: 1K; RES_CAY16
R602: 1M; SM0402_r
R603: 12K3 1%; SM0402_r
R605: 49R9 1%; RES_CAY16
R606, R607: 1K; SM0402_r
SJ601: OPEN; SJ_OPEN
U602: HY931147C
U603: APX811-31UG-7; SOT143-R
X601: TXC 7A 25MHz 18pF; TXC_7A

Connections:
+3.3V: C603.1, D601.A, D602.A, D603.A, D604.A, D605.A, D606.A, IC601.12 (VCC3V3D), IC601.18 (VCC3V3D), IC601.44 (VCC3V3D), L602.1, R601.2 (8), R601.4 (8), U602.11 (Y+), U602.13 (G+), U603.4 (VCC); also elsewhere on the board
/Connectors//MASTER-RESET: U603.3 (/MR); also elsewhere on the board
/Ethernet/1V8A: C606.1, IC601.7 (VCC1V8A), IC601.74 (VCC1V8A), L601.2
/Ethernet/1V8D: C604.1, C605.1, C607.1, IC601.11 (1V8_OUT), IC601.15 (VCC1V8D), IC601.16 (VCC1V8D), IC601.33 (VCC1V8D), IC601.69 (VCC1V8D), L601.1
/Ethernet/3V3A: C608.1, C611.1, IC601.2 (VCC3V3A), L602.2, U602.3 (RXCT), U602.4 (TXCT)
/Ethernet/COLLED: IC601.71 (COLLED), R604.5 (7)
/Ethernet/FDXLED: IC601.70 (FDXLED), R604.7, R607.1
/Ethernet/LINKLED: IC601.66 (LINKLED), R601.7, R606.1
/Ethernet/POE_V+: JP601.3, U602.9 (V+)
/Ethernet/POE_V-: JP601.2, U602.10 (V-)
/Ethernet/RXLED: IC601.72 (RXLED), R604.3 (7)
/Ethernet/SPDLED: IC601.67 (SPDLED), R601.5 (7)
/Ethernet/TXLED: IC601.73 (TXLED), R604.1 (7)
/Ethernet/WIZRST: IC601.59 (/RESET), U603.2 (/RESET)
MISO: IC601.27 (MISO); also elsewhere on the board
MOSI: IC601.28 (MOSI); also elsewhere on the board
unnamed: C601.1, IC601.75 (XTLN), R602.2, X601.1
unnamed: C602.1, IC601.76 (XTLP), R602.1, X601.2
unnamed: C609.1, R605.1, R605.3 (P2)
unnamed: C610.1, R605.5 (P3), R605.7 (P4)
unnamed: D601.K, R601.8
unnamed: D602.K, R601.6 (8)
unnamed: D603.K, R604.8
unnamed: D604.K, R604.6 (8)
unnamed: D605.K, R604.4 (8)
unnamed: D606.K, R604.2 (8)
unnamed: IC601.1 (RSET_BG), R603.1
unnamed: IC601.5 (RXIP), R605.8 (R4), U602.1 (RX+)
unnamed: IC601.6 (RXIN), R605.6 (R3), U602.2 (RX-)
unnamed: IC601.8 (TXOP), R605.2 (R1), U602.5 (TX+)
unnamed: IC601.9 (TXON), R605.4 (R1), U602.6 (TX-)
unnamed: IC601.31 (SEN), Q601.3 (D), R601.1 (7)
unnamed: IC601.55 (/CS), IC601.57 (/WR), IC601.58 (/RD), R601.3 (7)
unnamed: IC601.56 (/INT), SJ601.2
unnamed: R606.2, U602.12 (Y-)
unnamed: R607.2, U602.14 (G-)
PWM2: SJ601.1; also elsewhere on the board
SCK: IC601.30 (SCLK); also elsewhere on the board
SS0/PWM10: IC601.29 (/SCS), Q601.1 (G); also elsewhere on the board
VIN: JP601.4; also elsewhere on the board

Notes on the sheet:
W5100 Reset on Poweron
Analog Power Decoupling
For DC PoE with low voltage, jumper 3(PoE_V+) to 4(VIN) & 2(PoE_V-) to 1(GND)
Direct feed to Arduino VIN
PoE Module Header
1.8v decoupling: 1 near pins 15/16, 1 near pin 33
/SCS & SS0 Behaviour: MISO pin tri-state by SS & /SCS SS0 low simultaneously drives SEN high -> SPI enabled & chip selected
Reset IC - 140ms min, 280ms max < 3.08 Vrst, push-pull output

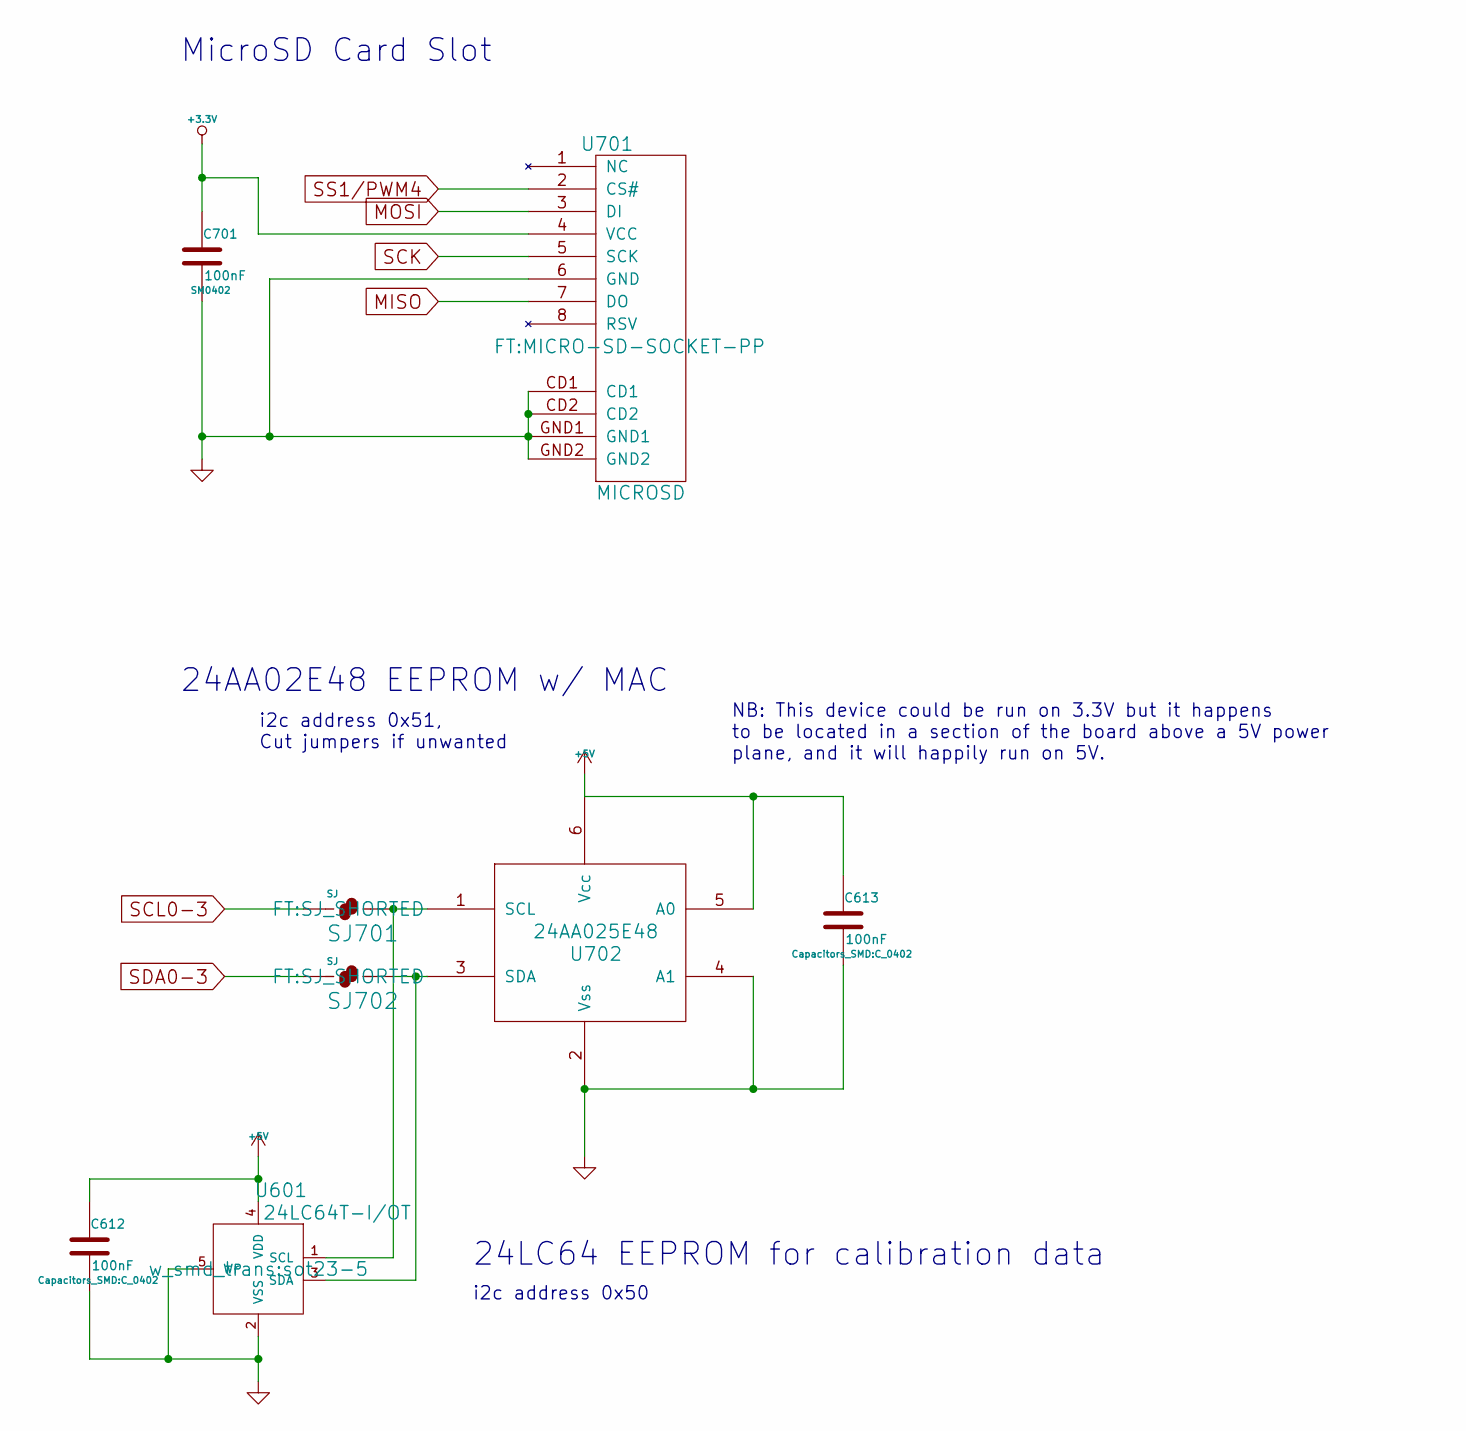
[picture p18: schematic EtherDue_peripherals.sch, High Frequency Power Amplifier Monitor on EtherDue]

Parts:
C612, C613: 100nF; C_0402
C701: 100nF; SM0402
SJ701, SJ702: SJ; SJ_SHORTED
U601: 24LC64T-I/OT; sot23-5
U701: MICROSD; MICRO-SD-SOCKET-PP
U702: 24AA025E48; SOT23-6

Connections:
+3.3V: C701.1, U701.4 (VCC); also elsewhere on the board
+5V: C612.1, C613.1, U601.4 (VDD), U702.5 (A0), U702.6 (Vcc); also elsewhere on the board
MISO: U701.7 (DO); also elsewhere on the board
MOSI: U701.3 (DI); also elsewhere on the board
unnamed: SJ701.2, U601.1 (SCL), U702.1 (SCL)
unnamed: SJ702.2, U601.3 (SDA), U702.3 (SDA)
SCK: U701.5 (SCK); also elsewhere on the board
SCL0-3: SJ701.1; also elsewhere on the board
SDA0-3: SJ702.1; also elsewhere on the board
SS1/PWM4: U701.2 (CS#); also elsewhere on the board

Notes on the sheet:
24AA02E48 EEPROM w/ MAC
i2c address 0x51, Cut jumpers if unwanted
MicroSD Card Slot
NB: This device could be run on 3.3V but it happens to be located in a section of the board above a 5V power plane, and it will happily run on 5V.
24LC64 EEPROM for calibration data
i2c address 0x50

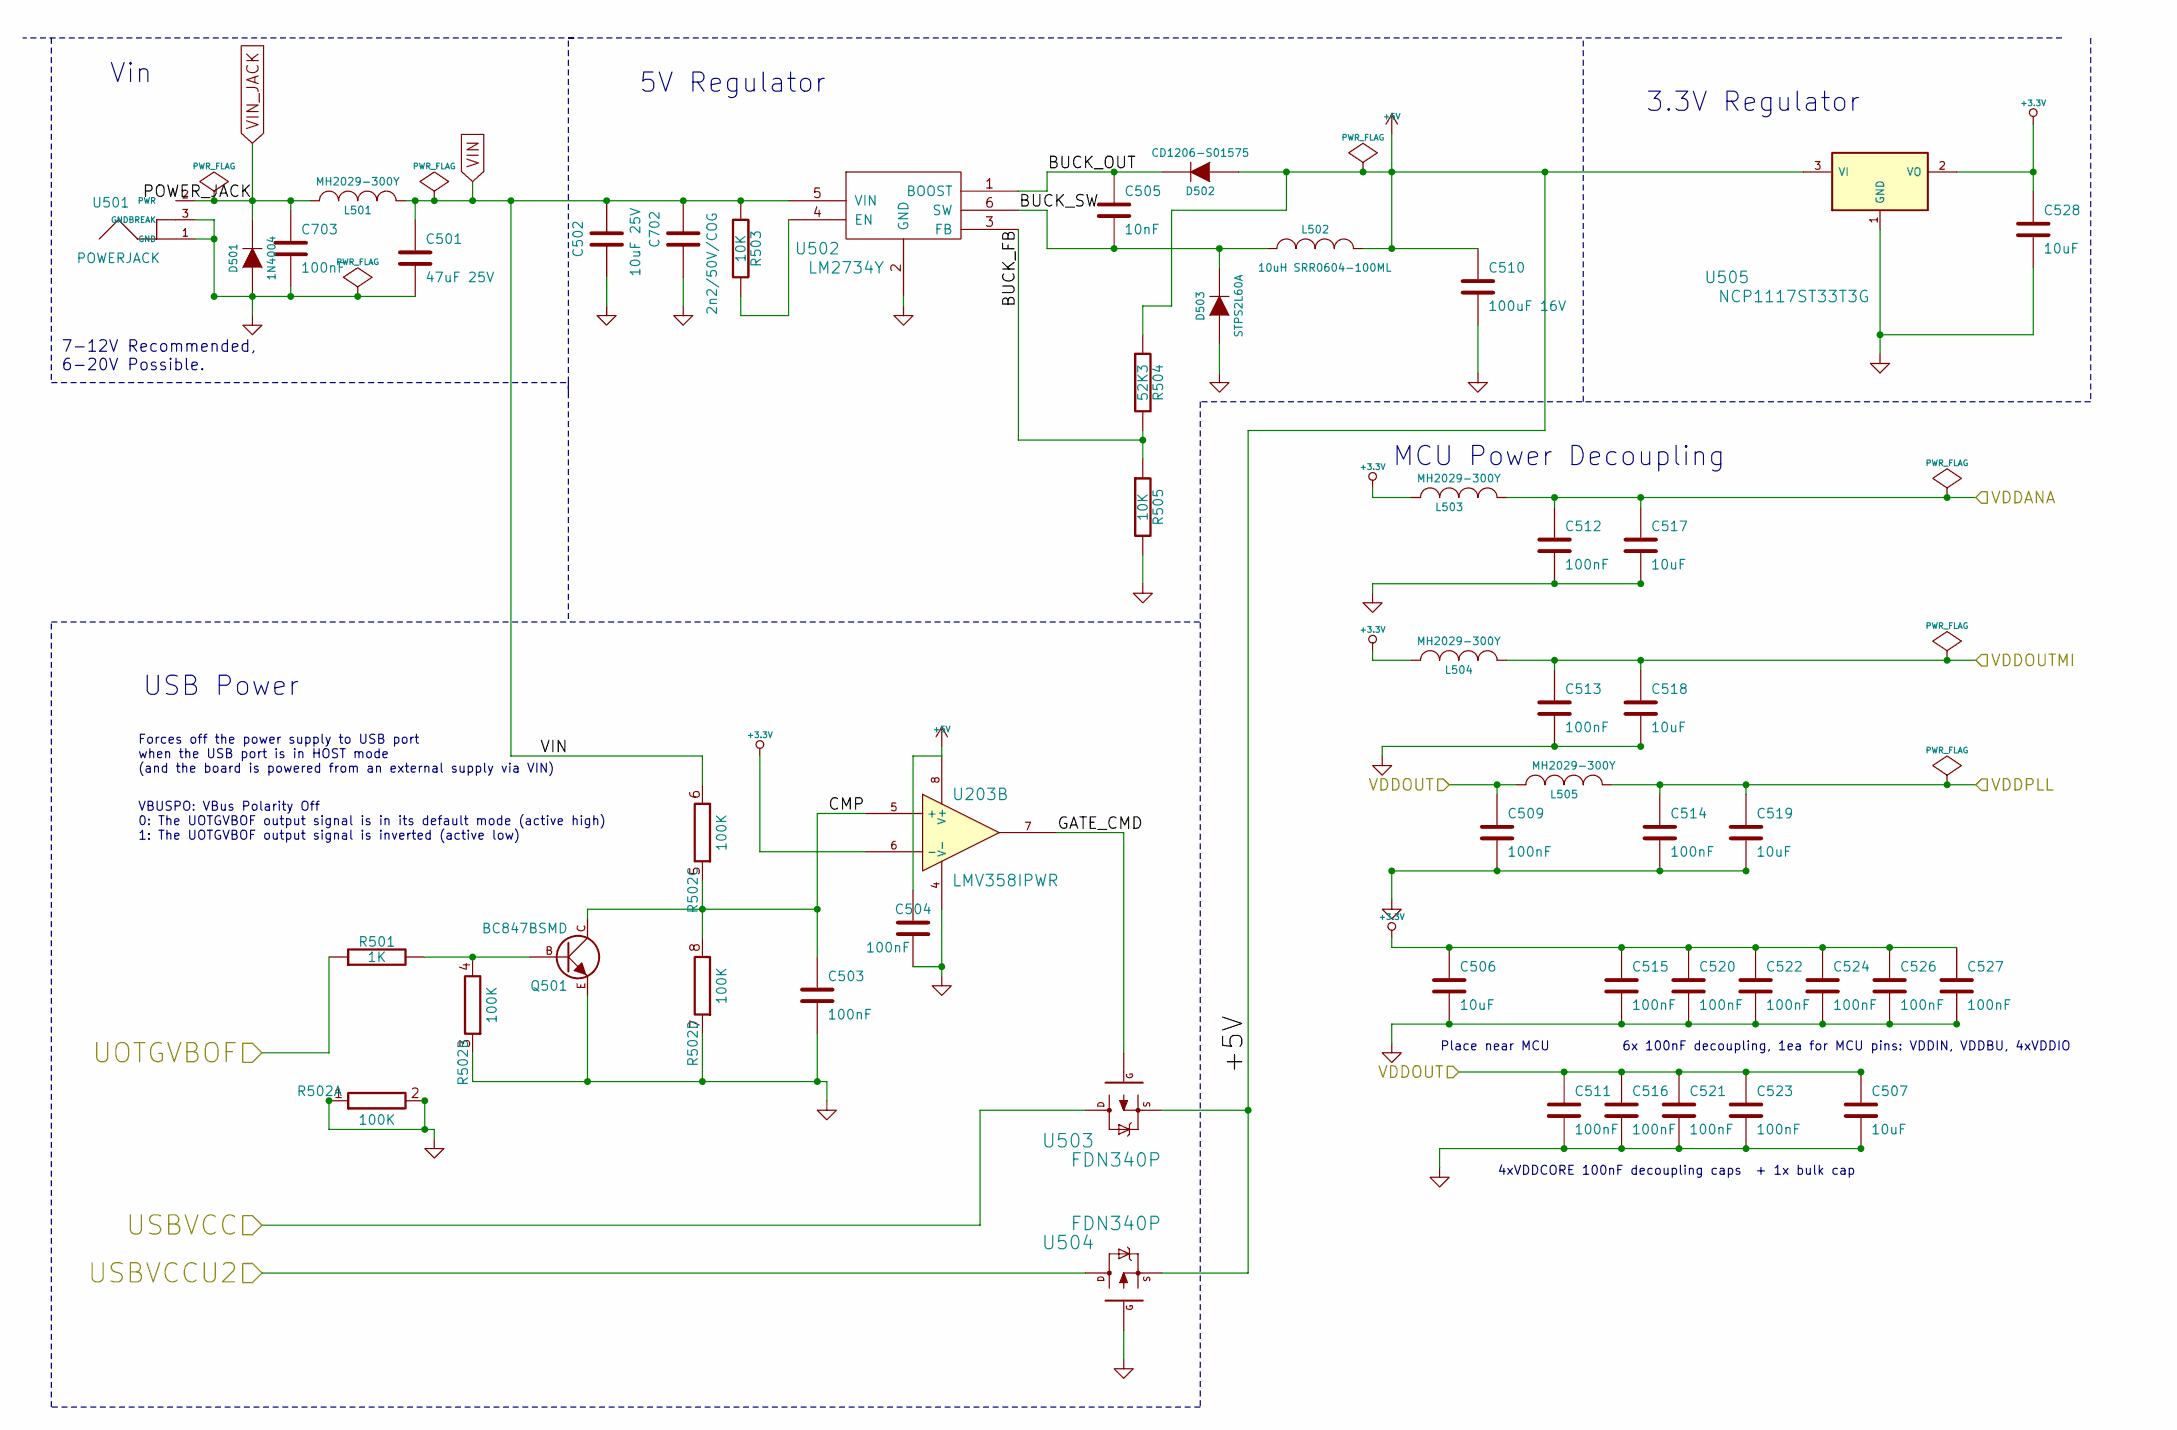
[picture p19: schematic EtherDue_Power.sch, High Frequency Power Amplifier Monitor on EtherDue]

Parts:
C501: 47uF 25V; c_elec_6.3x5.8
C502: 10uF 25V; SM1206
C503, C504, C509, C511, C512, C513, C514, C515, C516, C520, C521, C522, C523, C524, C526, C527: 100nF; SM0402
C505: 10nF; SM0402
C506, C507, C517, C518, C519, C528: 10uF; SM0603_Capa
C510: 100uF 16V; c_elec_6.3x5.8
C702: 2n2/50V/COG; C_0603
C703: 100nF; SM0603_Capa
D501: 1N4004; SMB-DIODE
D502: CD1206-S01575; 1206_DIODE
D503: STPS2L60A; SMA-DIODE
L501, L503, L504, L505: MH2029-300Y; MH2029
L502: 10uH SRR0604-100ML; SRR0604
Q501: BC847BSMD; SOT23_TRANSISTOR
R501: 1K; SM0402_r
R502: 100K; RES_CAY16
R503, R505: 10K; SM0402_r
R504: 52K3; SM0402_r
U203: LMV358IPWR; TSSOP8
U501: POWERJACK; POWER_JACK_PTH
U502: LM2734Y; SOT23-6
U503, U504: FDN340P; SOT23_MOSFET
U505: NCP1117ST33T3G; SOT223

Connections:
+3.3V: C506.1, C515.1, C520.1, C522.1, C524.1, C526.1, C527.1, C528.1, L503.1, L504.1, U203.6 (-), U505.2 (VO); also elsewhere on the board
+5V: C504.1, C510.1, D502.A, L502.2, R504.1, U203.8 (V+), U503.S, U504.S, U505.3 (VI); also elsewhere on the board
/Connectors/USBVCC: U503.D; also elsewhere on the board
/MCU/UOTGVBOF: R501.1; also elsewhere on the board
/MCU/VDDANA: C512.1, C517.1, L503.2; also elsewhere on the board
/MCU/VDDOUT: C507.1, C509.1, C511.1, C516.1, C521.1, C523.1, L505.1; also elsewhere on the board
/MCU/VDDOUTMI: C513.1, C518.1, L504.2; also elsewhere on the board
/MCU/VDDPLL: C514.1, C519.1, L505.2; also elsewhere on the board
/Mega16U2/USBVCCU2: U504.D; also elsewhere on the board
/Power/BUCK_FB: R504.2, R505.1, U502.3 (FB)
/Power/BUCK_OUT: C505.1, D502.K, U502.1 (BOOST)
/Power/BUCK_SW: C505.2, D503.K, L502.1, U502.6 (SW)
/Power/CMP: C503.1, Q501.C, R502.5 (7), R502.8, U203.5 (+)
/Power/GATE_CMD: U203.7, U503.G
unnamed: Q501.B, R501.2, R502.4 (8)
unnamed: R503.2, U502.4 (EN)
VIN: C501.1, C502.1, C702.1, L501.2, R502.6 (8), R503.1, U502.5 (VIN); also elsewhere on the board
VIN_JACK: C703.1, D501.K, L501.1, U501.2 (PWR); also elsewhere on the board

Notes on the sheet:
4xVDDCORE 100nF decoupling caps + 1x bulk cap
Place near MCU
6x 100nF decoupling, 1ea for MCU pins: VDDIN, VDDBU, 4xVDDIO
MCU Power Decoupling
VBUSPO: VBus Polarity Off 0: The UOTGVBOF output signal is in its default mode (active high) 1: The UOTGVBOF output signal is inverted (active low)
Forces off the power supply to USB port when the USB port is in HOST mode (and the board is powered from an external supply via VIN)
USB Power
3.3V Regulator
5V Regulator
Vin
7-12V Recommended, 6-20V Possible.

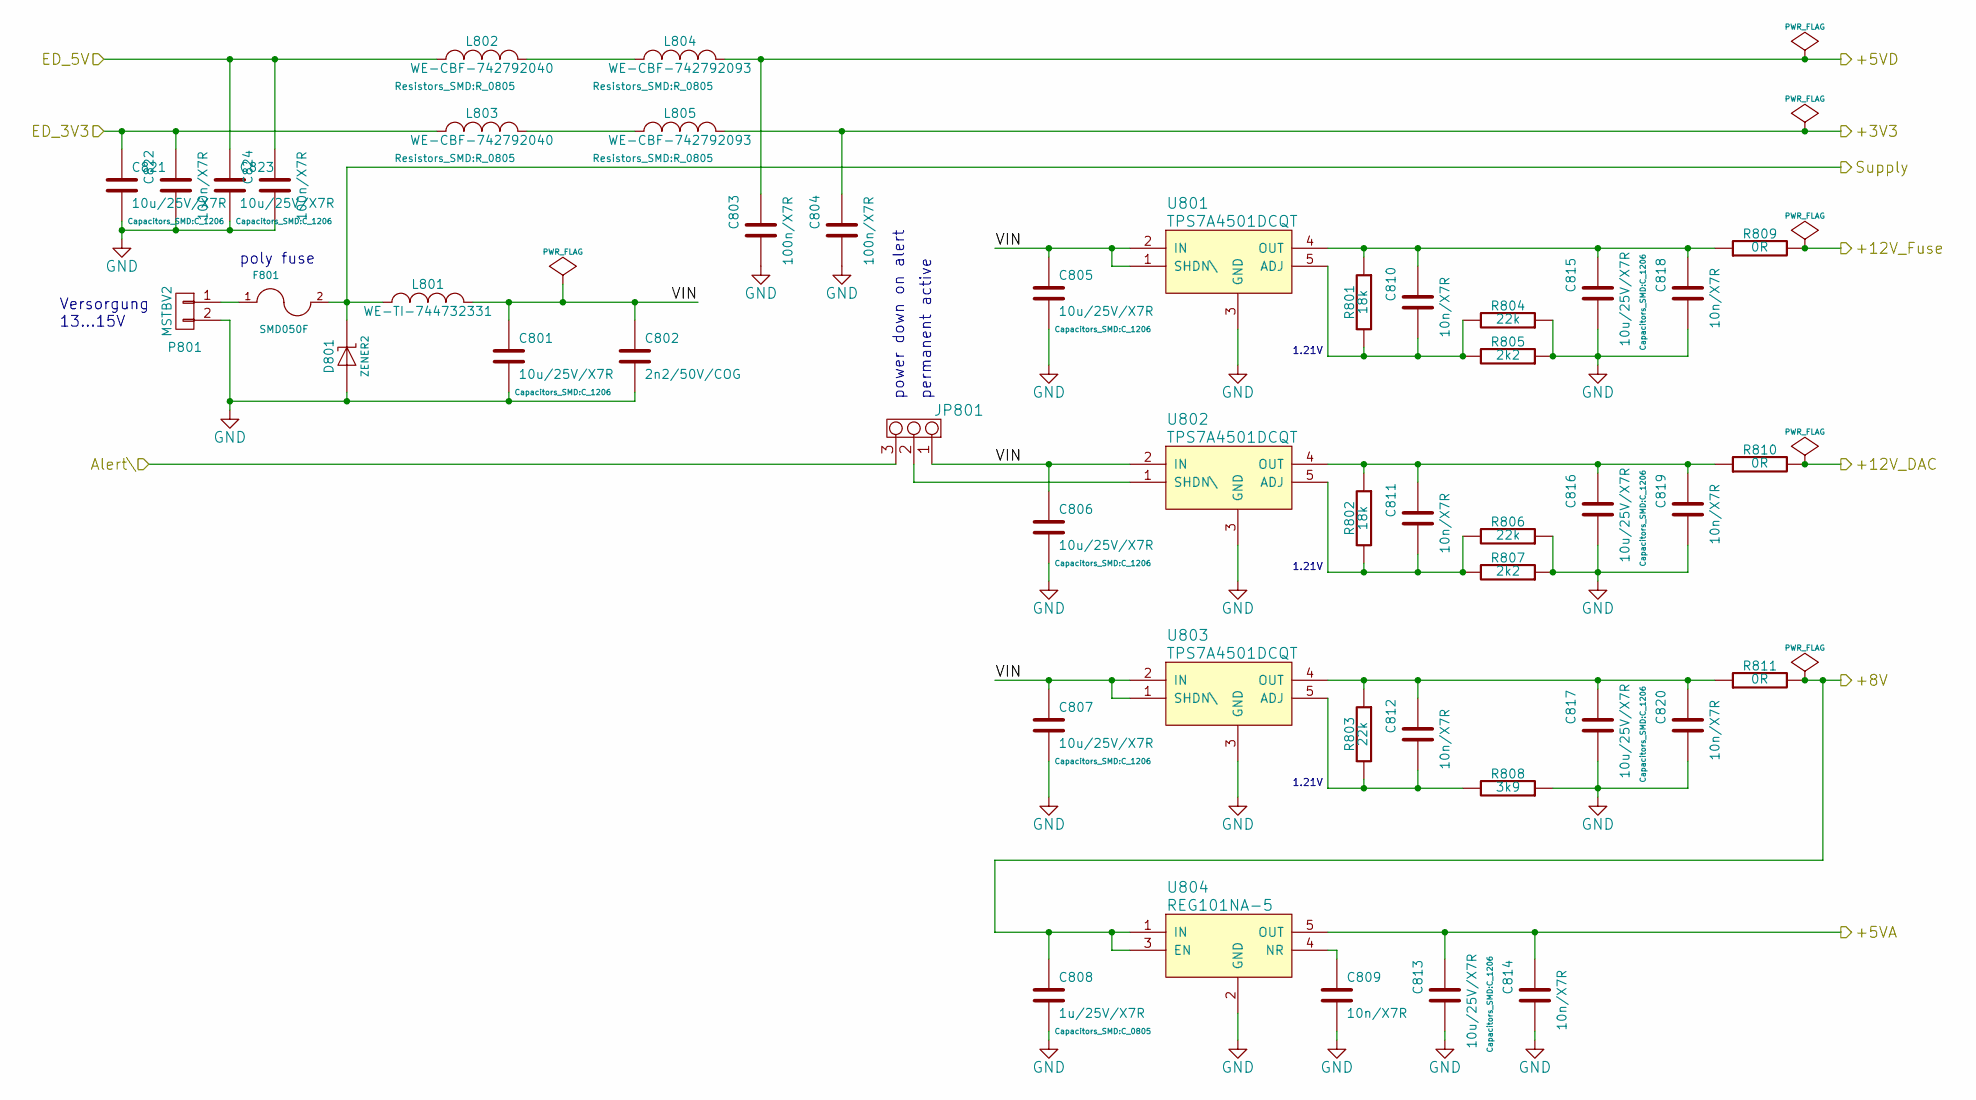
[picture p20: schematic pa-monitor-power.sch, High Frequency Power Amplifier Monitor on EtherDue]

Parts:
C801, C805, C806, C807, C813, C815, C816, C817, C821, C823: 10u/25V/X7R; C_1206
C802: 2n2/50V/COG; C_0603
C803, C804, C822, C824: 100n/X7R; C_0603
C808: 1u/25V/X7R; C_0805
C809, C810, C811, C812, C814, C818, C819, C820: 10n/X7R; C_0603
D801: ZENER2; Diode-SMB_Standard
F801: SMD050F
JP801: JUMPER3; Pin_Header_Straight_1x03
L801: WE-TI-744732331; WE-TI_8075_SHRINKTUBE
L802, L803: WE-CBF-742792040; R_0805
L804, L805: WE-CBF-742792093; R_0805
P801: MSTBV2
R801, R802: 18k; R_0603
R803, R804, R806: 22k; R_0603
R805, R807: 2k2; R_0603
R808: 3k9; R_0603
R809, R810, R811: 0R; R_0603
U801, U802, U803: TPS7A4501DCQT; DCQ(R-PDSO-G6)
U804: REG101NA-5; DBV(R-PDSO-G5)

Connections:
+3.3V: C821.1, C822.1, L803.1; also elsewhere on the board
+5V: C823.1, C824.1, L802.1; also elsewhere on the board
/Analog I/O/+3V3: C804.1, L805.2; also elsewhere on the board
/Analog I/O/+5VA: C813.1, C814.1, U804.5 (OUT); also elsewhere on the board
/Analog I/O/+12V: R810.2; also elsewhere on the board
/CAN-Bus/+5V: C803.1, L804.2; also elsewhere on the board
/PA-Monitor Power Supply/+8V: C808.1, R811.2, U804.1 (IN), U804.3 (EN); also elsewhere on the board
/PA-Monitor Power Supply/VIN: C801.1, C802.1, C805.1, C806.1, C807.1, JP801.1, L801.2, U801.1 (SHDN\), U801.2 (IN), U802.2 (IN), U803.1 (SHDN\), U803.2 (IN)
unnamed: C809.1, U804.4 (NR)
unnamed: C810.1, C815.1, C818.1, R801.1, R809.1, U801.4 (OUT)
unnamed: C810.2, R801.2, R804.2, R805.2, U801.5 (ADJ)
unnamed: C811.1, C816.1, C819.1, R802.1, R810.1, U802.4 (OUT)
unnamed: C811.2, R802.2, R806.2, R807.2, U802.5 (ADJ)
unnamed: C812.1, C817.1, C820.1, R803.1, R811.1, U803.4 (OUT)
unnamed: C812.2, R803.2, R808.2, U803.5 (ADJ)
unnamed: F801.1, P801.1
unnamed: JP801.2, U802.1 (SHDN\)
unnamed: L802.2, L804.1
unnamed: L803.2, L805.1
PIN24: JP801.3; also elsewhere on the board
VIN_JACK: D801.K, F801.2, L801.1; also elsewhere on the board

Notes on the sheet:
Versorgung 13...15V
1.21V
power down on alert
permanent active
poly fuse

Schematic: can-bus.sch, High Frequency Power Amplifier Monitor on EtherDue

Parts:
C901, C902: 100n/X7R; C_0603
L901: WE-SL1-744212510; WE-SL1
P901, P902: 677006144621; Firewire-Female-WE677006144621
R901: 1k8; R_0603
R902: 1k; R_0603
R903: 47k; R_0603
R904, R905: 60R; R_0805
R906, R907: 1k3; R_0805
SJ901, SJ902: Solder-Jumper; SJ_2W
U901: TJA1040T; SOIC-8_3.9x4.9mm_Pitch1.27mm

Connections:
/CAN-Bus/+5V: C901.1, U901.3 (VCC); also elsewhere on the board
CANRX0: R901.1, R902.2; also elsewhere on the board
CANTX0: U901.1 (TXD); also elsewhere on the board
unnamed: C902.1, SJ901.C, SJ902.C, U901.5 (SPLIT)
unnamed: L901.1 (AA), R904.2, R906.2, U901.7 (CANH)
unnamed: L901.3 (SA), R905.2, R907.2, U901.6 (CANL)
unnamed: L901.4 (SB), P901.3, P902.3
unnamed: L901.5 (AB), P901.4, P902.4
unnamed: R902.1, U901.4 (RXD)
unnamed: R903.1, U901.8 (STB)
unnamed: R904.1, SJ901.1
unnamed: R905.1, SJ901.2
unnamed: R906.1, SJ902.1
unnamed: R907.1, SJ902.2

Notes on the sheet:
Firewire Connectors are used for CAN
Level shift 5V to 3.3V

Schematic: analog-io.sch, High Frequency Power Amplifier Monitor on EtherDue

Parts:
C1001, C1002, C1003, C1004, C1009, C1010, C1017, C1018, C1022, C1023, C1034, C1035, C1036, C1037, C1038, C1039, C1040, C1041: 1n/X7R; C_0603
C1005, C1007, C1011, C1014: 100p/X7R; C_0603
C1006, C1008, C1012, C1015, C1016, C1019, C1020, C1021, C1024, C1025, C1028, C1029, C1030, C1031, C1032: 100n/X7R; C_0603
C1013, C1026, C1033: 10u/25V/X7R; C_1206
C1042: 10n/X7R; C_0603
D1001, D1002, D1003, D1004: BAT54S; sot23
JP1001, JP1002, JP1003, JP1004: JUMPER3; Pin_Header_Straight_1x03
LED1001: RED; LED-0805
Q1001: BSS308; sot23-gsd
R1001, R1002, R1003, R1004, R1005, R1006, R1007, R1008, R1014, R1015: 100R; R_0603
R1009, R1010, R1011, R1012: 5k6; R_0603
R1013, R1016, R1017: 4k7; R_0603
R1018, R1019: 33R; R_0603
U1001: AD7294BSUZ; QFP40P900X900X120-64N
VR1001, VR1002, VR1003, VR1004: 10k; Potentiometer_Bourns_3296W_3-8Zoll_Inline_ScrewUp
X1001, X1002, X1003, X1004, X1005, X1006, X1007, X1008, X1009, X1010, X1011, X1012: SMB; SMB-RS#420-5401_wirepad

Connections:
/Analog I/O/+3V3: C1032.1, Q1001.S, R1013.2, R1016.2, R1017.2, U1001.42 (VDRIVE); also elsewhere on the board
/Analog I/O/+5VA: C1003.1, C1009.1, C1013.1, C1016.1, C1017.1, C1019.1, C1021.1, C1022.1, C1025.1, C1029.1, D1001.3 (cathode), D1002.3 (cathode), D1003.3 (cathode), D1004.3 (cathode), U1001.5 (AVDD1), U1001.8 (AVDD2), U1001.14 (AVDD3), U1001.25 (AVDD4), U1001.56 (AVDD5), U1001.57 (AVDD6); also elsewhere on the board
/Analog I/O/+12V: C1020.1, C1024.1, C1031.1, R1009.2, R1010.2, R1011.2, R1012.2, U1001.21 (DAC_OUTV+_AB), U1001.28 (DAC_OUTV+_CD); also elsewhere on the board
/Analog I/O/VIN1: C1009.2, C1010.1, C1039.1, D1002.2 (AK), U1001.51 (VIN1); also elsewhere on the board
/Analog I/O/VIN3: C1022.2, C1023.1, C1041.1, D1004.2 (AK), U1001.49 (VIN3); also elsewhere on the board
/Analog Level Adoption/I_Fuse1_Out: C1003.2, C1004.1, C1038.1, D1001.2 (AK), U1001.52 (VIN0); also elsewhere on the board
/Analog Level Adoption/I_Fuse2_Out: C1017.2, C1018.1, C1040.1, D1003.2 (AK), U1001.50 (VIN2); also elsewhere on the board
/CAN-Bus/+5V: C1028.1, U1001.44 (DVDD); also elsewhere on the board
unnamed: C1001.1, C1005.1, R1001.2, U1001.12 (D1-)
unnamed: C1001.2, C1007.1, R1002.2, U1001.11 (D1+)
unnamed: C1002.1, C1014.1, R1003.2, U1001.10 (D2+)
unnamed: C1002.2, C1011.1, R1004.2, U1001.9 (D2-)
unnamed: C1006.1, JP1001.2, R1005.2, U1001.18 (OFFSET_IN_A)
unnamed: C1008.1, JP1002.2, R1006.2, U1001.23 (OFFSET_IN_B)
unnamed: C1012.1, JP1003.2, R1007.2, U1001.26 (OFFSET_IN_C)
unnamed: C1015.1, JP1004.2, R1008.2, U1001.31 (OFFSET_IN_D)
unnamed: C1026.1, U1001.53 (REF_ADC)
unnamed: C1030.1, U1001.54 (DCAP)
unnamed: C1033.1, C1042.1, U1001.15 (REF_DAC)
unnamed: C1034.1, U1001.19 (VOUT_A), X1009.2 (center)
unnamed: C1035.1, U1001.22 (VOUT_B), X1010.2 (center)
unnamed: C1036.1, U1001.27 (VOUT_C), X1011.2 (center)
unnamed: C1037.1, U1001.30 (VOUT_D), X1012.2 (center)
unnamed: JP1001.3, R1009.1, VR1001.2, VR1001.3
unnamed: JP1002.3, R1010.1, VR1002.2, VR1002.3
unnamed: JP1003.3, R1011.1, VR1003.2, VR1003.3
unnamed: JP1004.3, R1012.1, VR1004.2, VR1004.3
unnamed: LED1001.A, R1015.1
unnamed: Q1001.D, R1015.2
unnamed: Q1001.G, R1014.2
unnamed: R1001.1, X1001.2 (center)
unnamed: R1002.1, X1002.2 (center)
unnamed: R1003.1, X1003.2 (center)
unnamed: R1004.1, X1004.2 (center)
unnamed: R1005.1, X1005.2 (center)
unnamed: R1006.1, X1006.2 (center)
unnamed: R1007.1, X1007.2 (center)
unnamed: R1008.1, X1008.2 (center)
unnamed: R1016.1, R1018.2, U1001.39 (SDA)
unnamed: R1017.1, R1019.2, U1001.40 (SCL)
PIN24: R1013.1, R1014.1, U1001.35 (ALERT\); also elsewhere on the board
SCL0-3: R1019.1; also elsewhere on the board
SDA0-3: R1018.1; also elsewhere on the board

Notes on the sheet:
Shielded Inputs Temperature Sensors
Shielded Inputs for Offset
Shielded Outputs for Gate-Biasing
I2C Address: 0x61
unused highside current amp
TODO: R berechnen
10-turn potentiometers

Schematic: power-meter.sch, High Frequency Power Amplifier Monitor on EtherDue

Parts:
C1101, C1102: 100n/X7R; C_0603
C1103, C1104: 100p/X7R; C_0603
C1105, C1107: 47n/C0G; C_0805
C1106, C1109, C1113, C1114: 10n/X7R; C_0603
C1108, C1112: 10u/25V/X7R; C_1206
C1110: 47p/C0G; C_0603
C1111: 100n/X7R; C_0805
L1101: WE-CBF-742792093; R_0805
P1101, P1102: CONN_01X02; Pin_Header_Straight_1x02
R1101: 52R3/1%; R_0805
R1103, R1106: 0R; R_0603
R1104: 12k; R_0805
R1105: 2k2; R_0805
U1101: ADL5513; LFCSP16
U1102: REG101NA-5; DBV(R-PDSO-G5)
X1101: SMA; SMA-RS#616-3422
X1102, X1103: SMB; SMB-RS#420-5401_wirepad

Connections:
/PA-Monitor Power Supply/+8V: C1112.1, P1101.2, P1102.2, U1102.1 (IN), U1102.3 (EN); also elsewhere on the board
/Power-Meter Forward 1/+5V_PM: C1106.1, C1108.1, L1101.1, R1104.2, U1102.5 (OUT)
AD0: C1114.1, R1106.2; also elsewhere on the board
unnamed: C1101.1, C1102.1, C1103.1, C1104.1, L1101.2, U1101.1 (VPOS1), U1101.4 (VPOS2)
unnamed: C1105.1, U1101.2 (IN_HI)
unnamed: C1105.2, R1101.2, X1101.2 (center)
unnamed: C1107.1, U1101.3 (IN_LO)
unnamed: C1109.1, U1102.4 (NR)
unnamed: C1110.2, U1101.14 (CLPF)
unnamed: C1111.1, R1104.1, R1105.2, U1101.9 (TADJ)
unnamed: C1113.1, R1103.2, R1106.1, U1101.12 (VOUT), X1102.2 (center), X1103.2 (center)
unnamed: R1103.1, U1101.11 (VSET)

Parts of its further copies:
C1201, C1202, C1302, C1401, C1402, C1802, C1803: 100n/X7R; C_0603
C1203, C1204, C1303, C1304, C1403, C1404, C1605: 100p/X7R; C_0603
C1205, C1207, C1305, C1307, C1405, C1407, C1606: 47n/C0G; C_0805
C1206, C1209, C1213, C1214, C1306, C1309, C1313, C1314, C1406, C1409, C1413, C1414, C1607, C1609, C1613, C1614, C1713, C1714, C1813, C1814: 10n/X7R; C_0603
C1208, C1212, C1308, C1312, C1408, C1412, C1608: 10u/25V/X7R; C_1206
C1210, C1310, C1410, C1610: 47p/C0G; C_0603
C1211, C1311, C1411, C1611, C1711, C1811: 100n/X7R; C_0805
L1201, L1301, L1401, L1601, L1801: WE-CBF-742792093; R_0805
P1201, P1202, P1301, P1302, P1401, P1402, P1601, P1602, P1701, P1702, P1801, P1802: CONN_01X02; Pin_Header_Straight_1x02
R1201, R1401: 52R3/1%; R_0805
R1203, R1206, R1303, R1306, R1403, R1406: 0R; R_0603
R1204, R1304, R1404: 12k; R_0805
R1205, R1305, R1405: 2k2; R_0805
U1201, U1301, U1401, U1601: ADL5513; LFCSP16
U1202, U1302, U1402, U1602: REG101NA-5; DBV(R-PDSO-G5)
X1201, X1301, X1401, X1601, X1701, X1801: SMA; SMA-RS#616-3422
X1202, X1203, X1302, X1303, X1402, X1403, X1602, X1603, X1702, X1703, X1802, X1803: SMB; SMB-RS#420-5401_wirepad

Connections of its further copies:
/Analog I/O/VIN1: C1314.1, R1306.2; also elsewhere on the board
/Analog I/O/VIN3: C1414.1, R1406.2; also elsewhere on the board
/PA-Monitor Power Supply/+8V: C1212.1, C1312.1, C1412.1, P1201.2, P1202.2, P1301.2, P1302.2, P1401.2, P1402.2, U1202.1 (IN), U1202.3 (EN), U1302.1 (IN), U1302.3 (EN), U1402.1 (IN), U1402.3 (EN); also elsewhere on the board
/Power-Meter Forward 2/+5V_PM: C1206.1, C1208.1, L1201.1, R1204.2, U1202.5 (OUT)
/Power-Meter Return 1/+5V_PM: C1306.1, C1308.1, L1301.1, R1304.2, U1302.5 (OUT)
/Power-Meter Return 2/+5V_PM: C1406.1, C1408.1, L1401.1, R1404.2, U1402.5 (OUT)
AD1: C1214.1, R1206.2; also elsewhere on the board
unnamed: C1201.1, C1202.1, C1203.1, C1204.1, L1201.2, U1201.1 (VPOS1), U1201.4 (VPOS2)
unnamed: C1205.1, U1201.2 (IN_HI)
unnamed: C1205.2, R1201.2, X1201.2 (center)
unnamed: C1207.1, U1201.3 (IN_LO)
unnamed: C1209.1, U1202.4 (NR)
unnamed: C1210.2, U1201.14 (CLPF)
unnamed: C1211.1, R1204.1, R1205.2, U1201.9 (TADJ)
unnamed: C1213.1, R1203.2, R1206.1, U1201.12 (VOUT), X1202.2 (center), X1203.2 (center)
unnamed: C1305.1, U1301.2 (IN_HI)
unnamed: C1307.1, U1301.3 (IN_LO)
unnamed: C1309.1, U1302.4 (NR)
unnamed: C1310.2, U1301.14 (CLPF)
unnamed: C1311.1, R1304.1, R1305.2, U1301.9 (TADJ)
unnamed: C1313.1, R1303.2, R1306.1, U1301.12 (VOUT), X1302.2 (center), X1303.2 (center)
unnamed: C1401.1, C1402.1, C1403.1, C1404.1, L1401.2, U1401.1 (VPOS1), U1401.4 (VPOS2)
unnamed: C1405.1, U1401.2 (IN_HI)
unnamed: C1405.2, R1401.2, X1401.2 (center)
unnamed: C1407.1, U1401.3 (IN_LO)
unnamed: C1409.1, U1402.4 (NR)
unnamed: C1410.2, U1401.14 (CLPF)
unnamed: C1411.1, R1404.1, R1405.2, U1401.9 (TADJ)
unnamed: C1413.1, R1403.2, R1406.1, U1401.12 (VOUT), X1402.2 (center), X1403.2 (center)
unnamed 203: L1801.1; also elsewhere on the board
unnamed 276: L1801.2; also elsewhere on the board
unnamed: R1203.1, U1201.11 (VSET)
unnamed: R1303.1, U1301.11 (VSET)
unnamed: R1403.1, U1401.11 (VSET)

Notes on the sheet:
perforated break away
Power supply
measured power
0.4..2.2V
+5V

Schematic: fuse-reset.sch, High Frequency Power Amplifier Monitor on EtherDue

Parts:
C1501, C1504: 100n/X7R; C_0603
C1502: 1u/X7R; C_0805
C1603: 10n/X7R; C_0603
D1501: BAT54S; sot23
Q1501, Q1502: BSS123; sot23-gsd
R1501: 1k; R_0603
R1502: 100k; R_0603
R1503, R1504, R1505: 10k; R_0603
U1501: 4013_with_supply; SOIC-14_3.9x8.7mm_Pitch1.27mm

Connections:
/Analog I/O/+3V3: U1501.14 (VDD); also elsewhere on the board
unnamed: C1501.1, R1501.2
unnamed: C1501.2, D1501.2 (AK)
unnamed: Q1501.G, R1503.2
unnamed: Q1502.G, R1505.1
PIN46: U1501.3 (Cp); also elsewhere on the board
PIN47: C1603.1, U1501.11 (Cp); also elsewhere on the board
PIN48: R1501.1; also elsewhere on the board

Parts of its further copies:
C1505: 10n/X7R; C_0603
C1601, C1604: 100n/X7R; C_0603
C1602: 1u/X7R; C_0805
D1601: BAT54S; sot23
Q1601, Q1602: BSS123; sot23-gsd
R1601: 1k; R_0603
R1602: 100k; R_0603
R1603, R1604, R1605: 10k; R_0603

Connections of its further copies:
/Fuse-Reset B/Reset\: Q1602.D; also elsewhere on the board
unnamed: C1601.1, R1601.2
unnamed: C1601.2, D1601.2 (AK)
unnamed: Q1601.G, R1603.2
unnamed: Q1602.G, R1605.1
PIN46: C1505.1; also elsewhere on the board
PIN49: R1601.1; also elsewhere on the board

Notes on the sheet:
open drain output
asynchronous reset -> monoflop
1kHz
The reset output is pulsed low, when a) a 1kHz (digital, 3.3V) signl is applied to the Enable_AC input and b) a rising edge is applied to Clock input
Decoupling C is on parent sheet

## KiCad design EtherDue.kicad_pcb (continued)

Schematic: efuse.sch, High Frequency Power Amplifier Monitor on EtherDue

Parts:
C1301, C1702, C1704: 100n/X7R; C_0603
C1705, C1706: 10n/X7R; C_0603
C1707, C1708: 1n/X7R; C_0805
C1709: DNP; C_0603
C1710: 1n/X7R; C_0603
JP1701: JUMPER3; Pin_Header_Straight_1x03
L1701: WE-CBF-742792093; R_0805
LED1701: RED; LED-0805
Q1701, Q1702: BSS123; sot23-gsd
Q1703, Q1704: BSS308; sot23-gsd
R1301: 10k; R_0603
R1302, R1703, R1707: 100R; R_0603
R1307: 2k2; R_0805
R1702, R1706: 4k7; R_0603
R1704: 1k; R_0805
R1708, R1709: 0R; R_0603
R1711: 91k; R_0603
R1712: 4k7; 0603
SW1301: SW_PUSH; SW_TACTILE_SMD
U1701: MCP6H04; SOIC-14_3.9x8.7mm_Pitch1.27mm
U1702: INA206; SOIC-14_3.9x8.7mm_Pitch1.27mm
U1703: MEU1S1212ZC; MEU1-Murata-DCDC
VR1701: 10k; Potentiometer_Bourns_3296W_3-8Zoll_Inline_ScrewUp

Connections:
/eFuse 1 (10A)/+Shunt: R1708.2; also elsewhere on the board
/eFuse 1 (10A)/-Shunt: R1709.2; also elsewhere on the board
/eFuse 1 (10A)/Comp+: U1702.2 (OUT), U1702.4 (CMP1_IN+); also elsewhere on the board
/eFuse 1 (10A)/Gate: C1707.1, C1710.1, U1703.4 (VOUT+); also elsewhere on the board
/eFuse 1 (10A)/LED_K: LED1701.K, R1704.2; also elsewhere on the board
/eFuse 1 (10A)/Source: C1708.1, C1710.2, U1703.3 (VOUT-); also elsewhere on the board
unnamed: C1705.1, C1709.1, R1708.1, U1702.14 (VIN+)
unnamed: C1706.1, C1709.2, R1709.1, U1702.13 (VIN-)
unnamed: C1707.2, L1701.1, U1703.2 (VIN+)
unnamed 266: JP1701.2; also elsewhere on the board
unnamed: L1701.2, Q1704.D
unnamed: Q1701.D, R1704.1
unnamed: Q1701.G, R1703.1
unnamed: Q1702.D, Q1704.G, R1706.1
unnamed 301: Q1702.G; also elsewhere on the board
unnamed: Q1703.D, Q1704.S
unnamed: Q1703.G, R1707.2
unnamed: R1702.2, U1702.5 (CMP2_IN-)
unnamed: R1703.2, R1707.1, R1712.2, U1702.11 (CMP1_OUT)
unnamed: R1711.1, VR1701.3
unnamed: U1701.1, U1701.2 (-), U1702.3 (CMP1_IN-/0.6V_REF)
PIN24: JP1701.3; also elsewhere on the board

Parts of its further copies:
C1302, C1401, C1402, C1701, C1801, C1802, C1804, C1901, C1902, C1904: 100n/X7R; C_0603
C1805, C1806, C1905, C1906: 10n/X7R; C_0603
C1807, C1808, C1907, C1908: 1n/X7R; C_0805
C1809, C1909: DNP; C_0603
C1810, C1910: 1n/X7R; C_0603
JP1301, JP1401, JP1801, JP1901: JUMPER3; Pin_Header_Straight_1x03
L1801, L1901: WE-CBF-742792093; R_0805
LED1301, LED1401, LED1801, LED1901: RED; LED-0805
Q1301, Q1304, Q1401, Q1404, Q1801, Q1802, Q1901, Q1902: BSS123; sot23-gsd
Q1302, Q1303, Q1402, Q1403, Q1803, Q1804, Q1903, Q1904: BSS308; sot23-gsd
R1306, R1406, R1808, R1809, R1908, R1909: 0R; R_0603
R1308, R1402, R1408, R1705, R1803, R1805, R1807, R1903, R1905, R1907: 100R; R_0603
R1309, R1409, R1804, R1904: 1k; R_0805
R1407, R1710, R1810, R1910: 2k2; R_0805
R1701, R1801, R1901: 10k; R_0603
R1802, R1806, R1902, R1906: 4k7; R_0603
R1811, R1911: 91k; R_0603
R1812, R1912: 4k7; 0603
SW1401, SW1701, SW1801, SW1901: SW_PUSH; SW_TACTILE_SMD
U1403, U1802, U1902: MEU1S1212ZC; MEU1-Murata-DCDC
U1801, U1901: INA206; SOIC-14_3.9x8.7mm_Pitch1.27mm
VR1801, VR1901: 10k; Potentiometer_Bourns_3296W_3-8Zoll_Inline_ScrewUp

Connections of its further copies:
/Analog I/O/VIN1: R1306.2; also elsewhere on the board
/Analog I/O/VIN3: R1406.2; also elsewhere on the board
/eFuse 1 (10A)/Gate: R1710.2; also elsewhere on the board
/eFuse 1 (10A)/Source: R1710.1; also elsewhere on the board
/eFuse 2 (10A)/+Shunt: R1808.2; also elsewhere on the board
/eFuse 2 (10A)/-Shunt: R1809.2; also elsewhere on the board
/eFuse 2 (10A)/Comp+: U1801.2 (OUT), U1801.4 (CMP1_IN+); also elsewhere on the board
/eFuse 2 (10A)/Gate: C1807.1, C1810.1, R1810.2, U1802.4 (VOUT+); also elsewhere on the board
/eFuse 2 (10A)/LED_K: LED1801.K, R1804.2; also elsewhere on the board
/eFuse 2 (10A)/Reset\: R1801.2, SW1801.2, U1801.8 (CMP1_RESET\); also elsewhere on the board
/eFuse 2 (10A)/Source: C1808.1, C1810.2, R1810.1, U1802.3 (VOUT-); also elsewhere on the board
/eFuse 3 (60A)/+Shunt: R1908.2; also elsewhere on the board
/eFuse 3 (60A)/-Shunt: R1909.2; also elsewhere on the board
/eFuse 3 (60A)/Comp+: U1901.4 (CMP1_IN+); also elsewhere on the board
/eFuse 3 (60A)/Gate: C1907.1, C1910.1, R1910.2, U1902.4 (VOUT+); also elsewhere on the board
/eFuse 3 (60A)/ISense: U1901.2 (OUT); also elsewhere on the board
/eFuse 3 (60A)/LED_K: LED1901.K, R1904.2; also elsewhere on the board
/eFuse 3 (60A)/Reset\: R1901.2, SW1901.2, U1901.8 (CMP1_RESET\); also elsewhere on the board
/eFuse 3 (60A)/Source: C1908.1, C1910.2, R1910.1, U1902.3 (VOUT-); also elsewhere on the board
unnamed 184: R1306.1; also elsewhere on the board
unnamed 185: C1401.1, C1402.1; also elsewhere on the board
unnamed 192: R1406.1; also elsewhere on the board
unnamed 200: C1801.1, VR1801.2; also elsewhere on the board
unnamed: C1805.1, C1809.1, R1808.1, U1801.14 (VIN+)
unnamed: C1806.1, C1809.2, R1809.1, U1801.13 (VIN-)
unnamed: C1807.2, L1801.1, U1802.2 (VIN+)
unnamed 204: C1901.1, VR1901.2; also elsewhere on the board
unnamed: C1905.1, C1909.1, R1908.1, U1901.14 (VIN+)
unnamed: C1906.1, C1909.2, R1909.1, U1901.13 (VIN-)
unnamed: C1907.2, L1901.1, U1902.2 (VIN+)
unnamed 266: R1705.1; also elsewhere on the board
unnamed: JP1801.2, R1805.1
unnamed: JP1901.2, R1905.1
unnamed: L1801.2, Q1804.D
unnamed: L1901.2, Q1904.D
unnamed 301: R1705.2; also elsewhere on the board
unnamed: Q1801.D, R1804.1
unnamed: Q1801.G, R1803.1
unnamed: Q1802.D, Q1804.G, R1806.1
unnamed: Q1802.G, R1805.2
unnamed: Q1803.D, Q1804.S
unnamed: Q1803.G, R1807.2
unnamed: Q1901.D, R1904.1
unnamed: Q1901.G, R1903.1
unnamed: Q1902.D, Q1904.G, R1906.1
unnamed: Q1902.G, R1905.2
unnamed: Q1903.D, Q1904.S
unnamed: Q1903.G, R1907.2
unnamed: R1802.2, U1801.5 (CMP2_IN-)
unnamed: R1803.2, R1807.1, R1812.2, U1801.11 (CMP1_OUT)
unnamed: R1811.1, VR1801.3
unnamed: R1902.2, U1901.5 (CMP2_IN-)
unnamed: R1903.2, R1907.1, R1912.2, U1901.11 (CMP1_OUT)
unnamed: R1911.1, VR1901.3
unnamed 367: U1801.3 (CMP1_IN-/0.6V_REF); also elsewhere on the board
unnamed 368: U1901.3 (CMP1_IN-/0.6V_REF); also elsewhere on the board
PIN24: JP1801.3, JP1901.3; also elsewhere on the board

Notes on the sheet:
12V/12V
10-turn potentiometer
Decoupling C is on parent sheet

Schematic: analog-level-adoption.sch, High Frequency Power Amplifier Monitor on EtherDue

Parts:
C2001, C2002, C2003, C2010, C2011, C2012: 10n/X7R; C_0603
C2004, C2005, C2006, C2007, C2008, C2009, C2013, C2014: 1n/X7R; C_0603
D2001, D2002, D2003, D2004: BAT54S; sot23
R2001, R2002, R2003: 47k; R_0805
R2004, R2005, R2006: 2k7; R_0603
R2007, R2008, R2009: 10k; R_0603
R2010, R2011: DNP; R_0603
R2012: 6k8; R_0603

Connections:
/Analog I/O/+3V3: C2004.1, C2006.1, C2008.1, C2013.1, D2001.3 (cathode), D2002.3 (cathode), D2003.3 (cathode), D2004.3 (cathode); also elsewhere on the board
/Analog Level Adoption/I_Fuse1_Out: C2010.1, R2007.2, R2010.2; also elsewhere on the board
/Analog Level Adoption/I_Fuse2_Out: C2011.1, R2008.2, R2011.2; also elsewhere on the board
/eFuse 1 (10A)/Comp+: R2007.1; also elsewhere on the board
/eFuse 1 (10A)/Source: R2001.1; also elsewhere on the board
/eFuse 2 (10A)/Comp+: R2008.1; also elsewhere on the board
/eFuse 2 (10A)/Source: R2002.1; also elsewhere on the board
/eFuse 3 (60A)/ISense: R2009.1; also elsewhere on the board
/eFuse 3 (60A)/Source: R2003.1; also elsewhere on the board
AD2: C2001.1, C2004.2, C2005.1, D2001.2 (AK), R2001.2, R2004.2; also elsewhere on the board
AD3: C2002.1, C2006.2, C2007.1, D2002.2 (AK), R2002.2, R2005.2; also elsewhere on the board
AD4: C2003.1, C2008.2, C2009.1, D2003.2 (AK), R2003.2, R2006.2; also elsewhere on the board
AD5: C2012.1, C2013.2, C2014.1, D2004.2 (AK), R2009.2, R2012.2; also elsewhere on the board

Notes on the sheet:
Voltages from 60V to 3.3V
Currents of F1 and F2 from 12V to 5V and of F3 from 12V to 3.3V
0...5V
0...3.3V
0...60V
0...12V
place this 1nF near ADC
to VIN0
to VIN2

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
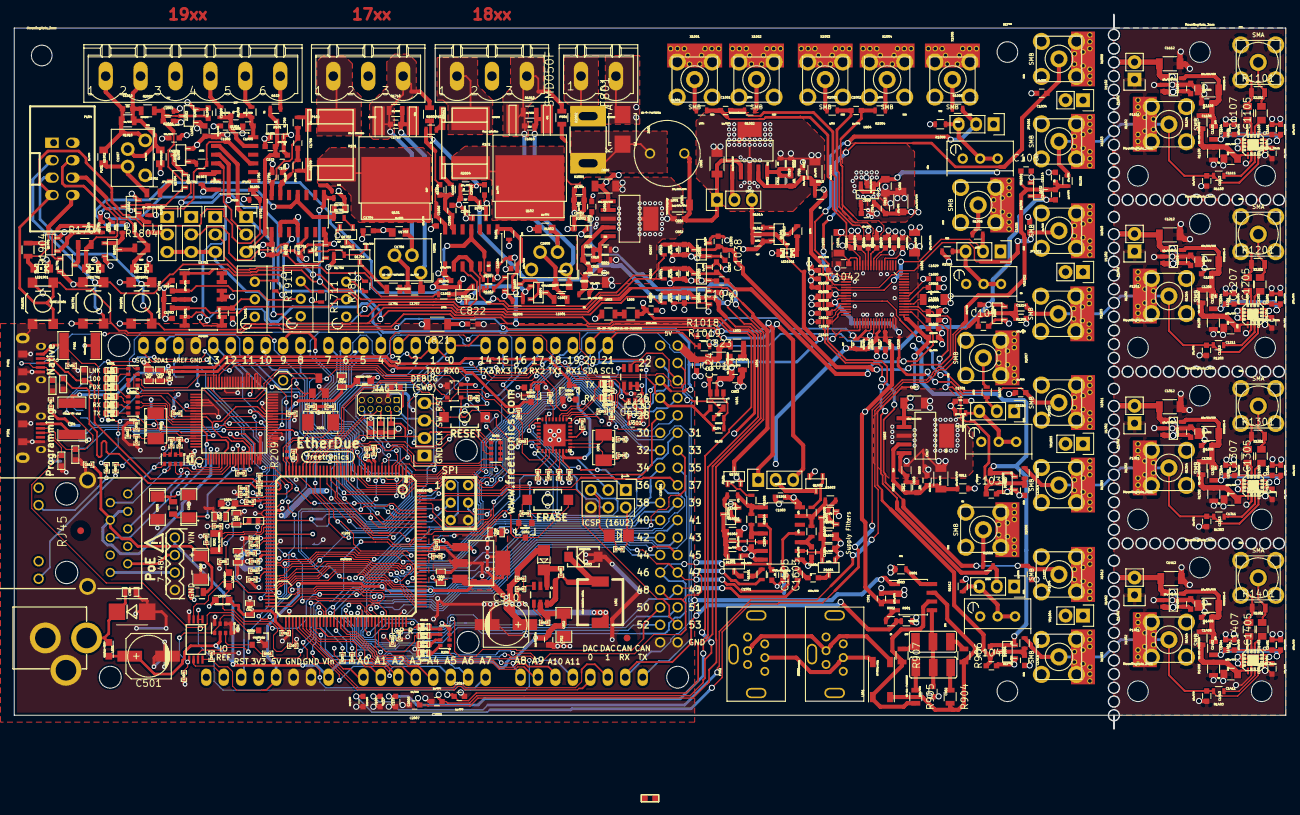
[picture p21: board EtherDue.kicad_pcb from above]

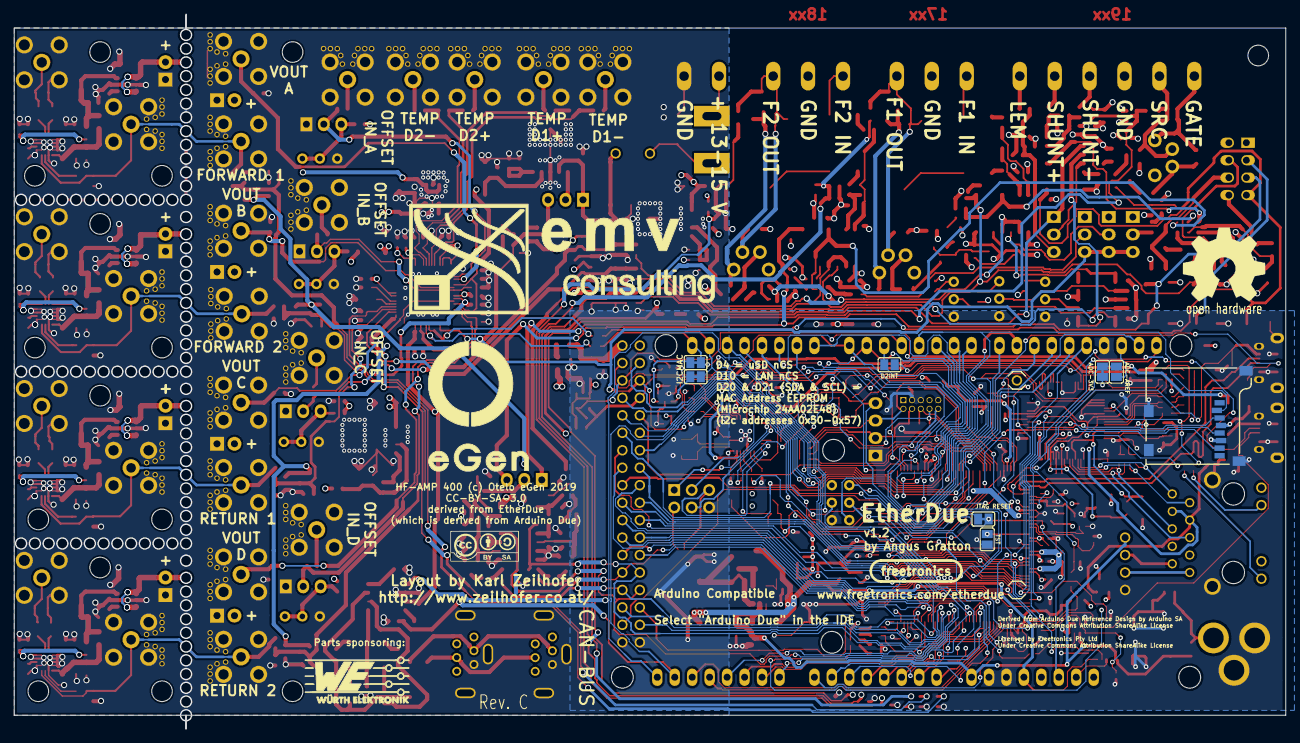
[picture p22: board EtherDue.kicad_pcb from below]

Board: 4 copper layers, 185.0 x 104.0 mm, 620 parts (9 on the bottom side), 377 nets.

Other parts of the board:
FIDUCIAL: val**; FIDUCIAL
FIDUCIAL#2: val**; FIDUCIAL
LOGO_FREETRONICS: val**; LOGO_FREETRONICS
LOGO_FREETRONICS_SMALL: val**; LOGO_FREETRONICS_SMALL
MountingHole_3mm, MountingHole_3mm#2, MountingHole_3mm#3, MountingHole_3mm#4, MountingHole_3mm#5, MountingHole_3mm#6, MountingHole_3mm#7, MountingHole_3mm#8, MountingHole_3mm#9, MountingHole_3mm#10, MountingHole_3mm#11, MountingHole_3mm#12, MountingHole_3mm#13: VAL**; MountingHole_3mm

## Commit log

2015-07-03 first produced pcb 20150617
    [BOM.csv, BOM.ods, EtherDue.kicad_pcb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]
2015-10-06 fixed missing Rs before Potis - fixed (removed) AD7294 Vpp connection
    [EtherDue.kicad_pcb, EtherDue.sch, EtherDue_Connectors.sch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]
2015-10-08 Rev B. Layout - Gerber/BOM need to be reexported
    [EtherDue.kicad_pcb, EtherDue.sch, EtherDue_Connectors.sch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]
2019-12-25 RevC - gerber needs reexporting

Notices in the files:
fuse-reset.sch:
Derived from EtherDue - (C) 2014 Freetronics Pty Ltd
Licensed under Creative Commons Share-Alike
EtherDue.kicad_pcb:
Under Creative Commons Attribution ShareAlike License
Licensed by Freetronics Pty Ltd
